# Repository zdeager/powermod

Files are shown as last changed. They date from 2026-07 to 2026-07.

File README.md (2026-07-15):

# PowerMOD

A generic power scheduler, UPS, and battery supply for I2C-capable hosts — Linux SBCs, microcontrollers, anything with a 3.3V I2C bus and a power input to control. Real-time clock, scheduled power-cycling, battery backup with load switchover, opt-in watchdog, and an event log, at a component cost of ≈$2.90.

**Status: design complete on paper. No hardware exists yet.** Every part is selected, priced, and datasheet-verified; every net is mapped pin-for-pin; the register map is ready for firmware review. Next step: transcribe the netlist into an EDA tool and lay out the board.

## Documents

| File | What it is |
|---|---|
| [powermod-spec.md](powermod-spec.md) | **The source of truth.** Full decision record with reasoning history — including reversed decisions, retained and marked. Carries the net map, the semantic-review findings, and a 45-claim verification register (every part capability cited to its datasheet; 18 claims were false and each correction is documented) |
| [powermod-user-guide-draft.md](powermod-user-guide-draft.md) | Draft user manual — integration guide, LED states, scheduling patterns, FAQ, and honest limits (drift table, output-current table, weak-supply behavior) |
| [powermod-register-map.md](powermod-register-map.md) | I2C protocol v1 — 32 registers, wire-level reference for host integration and firmware |
| [powermod-schematic.md](powermod-schematic.md) | Pin-exact netlist — every component pin to every net, MCU pin assignment, capture-time checklist. The EDA schematic transcribes this |
| [powermod-bom.md](powermod-bom.md) | Bill of materials — LCSC part numbers, verified prices, do-not-substitute notes, sourcing flags |
| [powermod_full_state_machine.svg](powermod_full_state_machine.svg) | Power state machine — all states, transitions, and gating rules |
| [hardware/](hardware/) | KiCad transcription — `netlist.py` (machine source of truth + validator) generates `powermod.net`, `powermod.kicad_sch` (ERC-clean, round-trip-verified), and via `layout.py` a placed, DRC-clean `powermod.kicad_pcb` (routing pending) |

## Open items (all require hardware)

Converter efficiency, standby current, the `CE` battery-detect decay test, factory-reset gesture feel, Q1/Q2 handover scope check.

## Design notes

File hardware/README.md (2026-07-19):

# PowerMOD hardware

Machine-generated PCB design for a Raspberry Pi Zero 2 W power scheduler /
UPS / battery board. The electrical design is defined in code (`netlist.py`);
the board was laid out and routed with the scripted KiCad + Freerouting
toolchain below, then hand-finished.

## The board — `powermod.kicad_pcb` (final)

65 × 40 mm, 4-layer (F.Cu signal / In1 solid GND / In2 signal / B.Cu signal).
Bolts under a Pi Zero 2 W (holes on the Pi's 58×23 grid, flush to the N+W
edges); the Pi covers y0–30, and all user-facing parts (USB-C out, battery,
button, LEDs, jumpers, test pads) sit on the exposed strip below it.
Single-sided assembly.

One KiCad project, one stem: `powermod.kicad_pro` (netclasses + DRC config),
`powermod.kicad_sch` (generated schematic), `powermod.kicad_pcb` (board),
`powermod.kicad_dru` (width-enforcement rules — net classes alone are NOT
checked by DRC).

**Status: fab-ready.** Fully routed, 0 unconnected, 0 clearance; the only DRC
items are 4 `track_width` flags on the L2/L1N necks at U3's 0.65 mm pins,
which physically cannot be 1.0 mm wide. Pre-fab audit (pad-for-pad netlist
diff, datasheet pin checks, operating-point math, the D5 supercap fix):
see **`PREFAB_AUDIT.md`** — read it before ordering (BOM traps, firmware
contract, bring-up plan).

> **Do NOT regenerate this board from `netlist.py`.** Placement and the
> USB-C fine-pitch escapes are hand-done. Make changes surgically on
> `powermod.kicad_pcb` and update `netlist.py` in parallel, then prove they
> agree with a pad-diff (the audit doc describes it).

## Electrical source of truth

- **`netlist.py`** — every component, pin, and net (73 components, 45 nets).
  Run it to (re)generate `powermod.kicad_sch`, `powermod.net`,
  `powermod.kicad_sym`, `sym-lib-table`, `fp-lib-table`. Has a self-test
  (golden vectors, pin counts).
- **`powermod.pretty/`** — local footprint lib: the merged-pad USB-C
  receptacle (reversible twin pads share one pad, so VBUS/GND escape cleanly
  and DRC sees no coincident-pad conflicts). Required to open the board.

## Reusable tools

All the layout/routing/placement scripts live in **`tools/`** (run them from
this directory, e.g. `python3 tools/finish_board.py powermod.kicad_pcb`, so
board paths and `_sizes.json` resolve; they add the parent dir to `sys.path`
to import `netlist.py`). `netlist.py` itself stays here — it's the design
source and writes the deliverables alongside itself. SPICE decks are in
`tools/spice/`.

Routing pipeline (for derivative boards — not this one):
- **`fr_pipeline.py`** — strip copper + export Specctra DSN / import routed
  SES. Freerouting must never see a pre-routed board.
- `tools/freerouting.jar` (gitignored, ~55 MB) — the autorouter. Java 21+, run
  with `-Djava.awt.headless=true` or it hangs on macOS.
- **`finish_board.py`** — post-route finisher: SES import → GND stitching →
  floating-pour-island tie vias → zone refill. Then DRC with
  `--refill-zones` (without it you get hundreds of phantom violations).
- **`stitch_gnd.py`** — the 2.5 mm GND stitching-via grid to the In1 plane.
- **`close_nets.py`** — route leftover nets with the In2-capable grid A*,
  each route validated by refill+DRC and reverted if it doesn't improve.
- **`router.py`** — grid A* + obstacle model (F/In2/B) used by the above.
- **`netclasses.py`** — inject net-class width targets into a `.kicad_pro`.

Placement:
- **`layout_v2.py`** — the board generator (`gen_pcb`: footprints, GND
  planes, keepouts). `layout_mount.py` configures it for this board's
  outline/holes/pinned I/O.
- **`place_constrained.py`** — constraint-aware force-directed placer
  (net springs, padded repulsion, wide-net/IC halos, rigid converter block).
- **`place_search_mount.py`** / **`relax_mount.py`** — placement search
  scored by Freerouting / overlap relaxer. **`mount_best.py`** — placer
  output snapshot (stale vs the hand-edited board; the board is
  authoritative).
- **`place_check.py`** — courtyard-overlap + off-board report.
- **`make_stencil.py`** — generates a bare user-facing-parts canvas for
  human I/O placement (its output board was removed once the layout froze).
- `_sizes.json` — cached footprint courtyard sizes (kept in this dir; the
  placer reads it cwd-relative).

SPICE (`tools/spice/`):
- **`power_path_scenarios.py`** — behavioural ngspice model of the Q1/Q2/Q3
  power path; runs the startup/switchover/unplug scenario matrix (see the
  SPICE section of `PREFAB_AUDIT.md`). Needs `ngspice` on PATH.

## Hard-won rules (cost real time — don't relearn them)

- A green DRC only checks rules that exist: keep `powermod.kicad_dru` next
  to the board, and after any rename/move confirm the 4 known `track_width`
  flags still fire (if they vanish, the rules got orphaned, not fixed).
- Netclasses live in the `.kicad_pro`. A board file copied away from its
  project routes everything at 0.2 mm and "routes fully" — a fake win.
- Zone fills are stored in the file: refill before DRC or judging renders.
- Scripted tracks don't bind to large connector pads (USB-C, bar pads) —
  those few escapes are interactive-routing territory; small pads bind fine.

## History

v1 (58×40, 2-layer) had 3A rails at 0.2 mm (the `.kicad_dru` lesson); v2
(65×30) was superseded by this board; the QFN-package MCU was swapped for the
SOIC-20 ATtiny1616 to break the routing wall; `powermod_mount.*` was renamed
to `powermod.*` once it became the only board (2026-07-17); then the MCU
migrated **ATtiny1616 → PY32F003F18P6** (TSSOP-20, ARM Cortex-M0+) on the
`instock-parts` branch (2026-07-18) for JLC assembly availability, with a full
reroute — the current board is 65×40, 4-layer, PY32. Lessons live in
the tools and `PREFAB_AUDIT.md`, not in stale board files.

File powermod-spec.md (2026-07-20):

# PowerMOD — Generic Power Scheduler / UPS / Battery Supply — Spec

Last updated: 2026-07-15
Status: **Requirements complete. Register map drafted (`powermod-register-map.md`, protocol v1). Parts selected and datasheet-verified. Schematic netlist complete (`powermod-schematic.md` — pin-exact, validated). BOM drafted (`powermod-bom.md`, **≈$2.90** @100–150 after the RTC reversal). Ready for schematic + firmware.**
Remaining before hardware: buck-boost efficiency and the final output figures (close by measuring, not reading), bench validation of the `CE` battery-detect, and the schematic-level confirmations flagged throughout. **Every IC and FET is now selected and datasheet-verified** — see the design at a glance.

> **⚠ MCU MIGRATION (instock-parts branch, 2026-07-18): ATtiny1617 → PY32F003F18P6.** No well-stocked AVR exists at JLC in any package, so the MCU is now the **PY32F003F18P6** (ARM Cortex-M0+, TSSOP-20, LCSC C5379864). **This spec still argues the MCU choice and pin budget in ATtiny terms — that text is RETAINED AS ROLLBACK RATIONALE and is MCU-agnostic** (the 20-pin-floor pin budget, the OR-latch "MCU WDT is a hard requirement", the fixed-3.3V-rail logic-level argument all hold identically for the PY32). What actually changed: the MCU part, UPDI→SWD programming, and **two PY32-specific firmware items** — ADC VREFINT calibration (see the ↪ note under §ADC) and I²C host-cutoff at VDD≥3.0V (↪ note under §Interface). **Authoritative pin map: `hardware/netlist.py` / `powermod-schematic.md` §1a.** Read every "ATtiny1617" below as "the selected MCU, now PY32"; the *net* mapping is unchanged (same 45 nets, UPDI→NRST the only swap).

## Revision note — 2026-07-15 audit

**A full cross-document audit** (this spec, the user guide, the state-machine diagram, and a register map written from them) **checked every decision against the others and against what the parts physically do.** Changes are marked inline in this document's existing decision-history style. It is a large revision; this note is the map.

**Contradictions resolved — four, each unimplementable as written:**
- **Missed-wake vs. past-wake** demanded opposite behaviour from an identical observable state → resolved by evaluating the timestamp *at commit*.
- **The reason-code register was destroyed by the act of booting** — powering on overwrote the power-off reason before any host could read it → split into two registers.
- **Emergency cutoff: delay or no delay** — the diagram and the spec disagreed → routed through the delay, one code path.
- **Minimum off-duration was never actually solved.** The gap said "minimum off-duration"; the register adopted to close it was "delay before power cut" — a different mechanism entirely. Nothing prevented a zero-second power cycle.

**BOM corrections — the design described behaviour its parts could not deliver:**
- **TP4056 → MCP73871 → *back to TP4056*, behind a discrete PFET OR (reversed later the same day).** The hot-swap claim does require power-path isolation, but **an OR-ing stage provides it just as well as a power-path IC**, and TP4056's disqualifying defects belong to the *topology* it was assumed to sit in, not to the part. The reversal halves the power stage (**~$2.00 → ~$1.00**) and roughly doubles mains output (1.3A → ~2.7A), because MCP73871's `SEL`-high limit is **1.8A total, "system power and charge current combined"** — a cap we were paying $1.46 to impose on ourselves. **BQ24074 remains disqualified**, and the MCP73871 analysis is retained as history. See "Charger and power path — REVERSED".
- **PCF85063A → RV-3028-C7 → *BM8563*, a PCF8563-class part (reversed 2026-07-15)** — the RV-3028's stated reason was false (no TCXO), and the audit later showed its 40nA never mattered either; what remained was ±1ppm for $1.62/board. Gates run against the clone's own datasheet; wake API unchanged (minute alarm + countdown residue); `BACKUP_TRICKLE` register replaced by a solder jumper. See RTC part decision.
- **14-pin MCU → ATtiny1617 (24-pin VQFN 4×4).** The pin budget missed by four, then grew twice more the same day (charger reversal; the OR's latch fix) — **18 pins, and a 20-pin part would ship with zero spare.**
- **Output 3A → ~1.2A → *a per-mode table* (same day).** 3A was never achievable on a 15W input, and drew double the battery connector's rating; the ~1.2A single figure then died with the charger reversal. **There is no one number: ~2.7A on mains, ~1.0–1.5A on battery via the connector, ~1.8–2.6A via the pads, ~2A in 3.3V mode** — see the ratings table.
- **TPS63020 selected**, and its load disconnect turns out to be *how host power is switched at all*.
- **The OR stage as first drawn latched permanently on unplug** — Q1's VBUS-tied gate held itself on through the battery, running the full load through Q2's body diode. Fixed: Q1 is MCU-driven off a VBUS-vs-VBAT comparison (Q2 stays fully passive), which costs a GPIO and makes the **ATtiny's own WDT a hard requirement**. FETs selected: **2× AON7407** (Q1/Q2), **BSS138** (Q3 driver).

**Added:** opt-in watchdog (the only unrecoverable failure mode), minimum off-duration, critical-battery threshold, LED power specification, a 3.3V logic rail, shutdown-pending status, wake-time read-back, hold-to-force on the button.

**Withdrawn after adoption** — recorded because the reversals are the useful part: **temperature-qualified charging** (the 2-pin connector gives the sensor no path to the cell), and **input-voltage telemetry** (mains detect was a digital read under the then-selected charger, so it wasn't free — **since half-reopened**: the charger reversal made mains detect a VBUS *ADC* divider, so the measurement is free again; deliberately not adopted in protocol v1. See Telemetry scope).

**Narrowed:** host support is **3.3V I2C**, not "any I2C" — a 5V host damages the board.

**Every part claim is now cited or marked unverified.** See the claims register appendix — **45 claims across four batches, 18 were false — and as of 2026-07-15, zero remain open**, and the failure rate *rose* as the claims got more consequential (batch 3: 16 of 23). The earliest two failures had already changed a decision before anyone looked. *(This sentence itself previously read "16 claims checked, two were false" — stale by 21 claims and 14 failures, in the paragraph describing the discipline. Self-descriptions rot fastest; this document's own register says so.)*

## The design at a glance

Everything below is reasoned out in this document; this table exists because it was not previously stated anywhere in one place, and a reader had to reconstruct it from prose and a Next Steps checkbox.

| | Selected | Verified |
|---|---|---|
| **MCU** | **ATtiny1617, 24-pin VQFN 4×4** | **Selected 2026-07-15.** 18 pins used, 4 spare. 1616 fits with *zero* spare; the count grew twice in one day. **VQFN-only — no SOIC variant exists** |
| **RTC** | **BM8563** (PCF8563-class) + 32kHz crystal, VDD via **2-diode OR** | **Reversed 2026-07-15** (−$1.67 after the Belling switch). ±20ppm-class; minute alarm + 1Hz countdown = seconds-exact wakes; `VL` flag; 250nA backup. **CLKOUT ships enabled — firmware disables**. I2C pins rated 6.5V independent of VDD |
| **Charger** | **TP4056** ($0.084) behind a **discrete PFET OR** | **Reversed 2026-07-15** — MCP73871 ($1.46) was 3× the converter and capped input at 1.5A *system + charge combined*. `TEMP` **grounded** (opposite of MCP73871's `THERM`) |
| **Power path** | **2× AON7407** (C176756, DFN3×3, $0.174) + **BSS138** (C52895) | **Q2 passive** (gate←VBUS). **Q1 MCU-driven** — a passive gate latched on unplug, see the OR stage. `Vgs(th)` −0.9V max, **12.5mΩ @ −2.5V**. ⚠️ AON7407 `VGS` limit is **±8V**, not ±20V |
| **Converter** | TPS63020 (adjustable, **not** 63021) | 4A switches (**3500mA min**), 25µA Iq, load disconnect. `PS/SYNC` **low**. Vin max 5.5V = **zero headroom** vs a 5.5V-compliant source |
| **Logic rail** | **XC6206P332MR** (Torex, C5446, SOT-23, $0.096) | **Iq 1µA; floor = LDO + battery divider (~3µA) + MCU sleep ≈ 5µA class.** Dropout ~38mV @ 15mA keeps the rail I2C-legal at cell-bottom. A SYS-powered MCU kills the I2C bus on mains |
| **Output** | **5V: ~1.0–2.7A. 3.3V: ~1.6–2.0A** | **Depends entirely on source + connector — see the ratings table.** Floor is ~1.0A (PH2.0, 5V, near cutoff). 3.3V never exceeds 2A in any config |
| **Battery detect** | TP4056 `CE` low → watch VBAT collapse | A **positive test**, not a threshold guess — separates *absent* from *deeply discharged*. Needs bench validation |
| **I2C** | **3.3V only**, no pull-ups fitted | 5V hosts need a level shifter — **they damage the board otherwise** |
| **Battery** | Any 3.7V LiPo, JST-PH 2-pin | **Polarity is not standardised across vendors — meter it** |
| **RTC backup** | Two solder pads + **charge solder-jumper** (open = coin-safe) | Coin cell / supercap / nothing. Supercap installs close the jumper; no register can ever charge a primary cell |
| **Ports** | 2× USB-C (5V, non-PD) | Rd 5.1k in; Rp 56k out (deliberate under-advertise). **Needs a ≥2A supply; 3A for full output** |
| **Range** | −40°C to +85°C electronics | −30/+60 if a coin cell is fitted; your LiPo narrows it further. **No charge-temperature protection** |

## What PowerMOD is

A generic, host-agnostic scheduled power controller and UPS: real time clock, battery charging and management, and a two-command power protocol (schedule a wake, request a cut) over I2C. Designed to be dropped into any project needing scheduled power-cycling, battery backup, or both — a Linux SBC, a bare-metal MCU project, or anything else with a **3.3V** I2C bus and a power input to control (the 3.3V is a hard limit, not a preference — see Interface).

The design deliberately makes zero assumptions about what it's powering or commanding: no host OS awareness, no GPIO signaling, no protocol behavior that only makes sense for one kind of host. The protocol, the power stage, and the physical connectors were all chosen specifically to keep this true (see Interface and Extensibility sections). **Linux SBCs (Olimex A64-OLinuXino, Raspberry Pi-class boards) are the first documented, validated use case and the primary motivation for building this at all — not a constraint on what the board can do.**

## The problem (as first encountered, via the Linux SBC case)

Existing scheduled-power boards for SBCs (Witty Pi and peers) infer host state instead of letting the host declare it — watching a serial pin voltage, assuming Raspberry Pi OS + Python + specific shutdown hooks, silently overwriting timezone assumptions. This breaks in real, documented ways, even on their officially-supported OS, and breaks harder on anything else (hit first-hand running Alpine Linux, requiring a custom driver). This specific, real pain point is what motivated PowerMOD's core design principle — but the principle itself (below) turned out to generalize far beyond the case that surfaced it.

## Design

The host owns the "when is it safe to cut power" decision entirely. The board never tries to detect or infer host state — it only responds to explicit commands.

**Two core operations:**
1. **Wake me at time T** — host writes a future timestamp before beginning its own shutdown sequence.
2. **Cut power now** — host issues this only once its own shutdown is genuinely complete, however its own OS determines that.

**Board exposes:** RTC (read/write), wake-time schedule, cut-now command, battery voltage, mains-vs-battery status.
**Board never needs to know:** host OS, init system, or how the host determines it's done.

This beats both Witty Pi's approach (fragile signal-inference) and a simpler "cut at time T unconditionally" alternative considered (host-decided cutoff removes the timing-race risk of a board-guessed deadline).

**Fallback safety (host hangs, never says "cut now"):**
- Board exposes mains/battery status so the host can prioritize its own shutdown urgency (low stakes on mains, real urgency on battery).
- Independent hard voltage floor, enforced by the board regardless of host cooperation: below a fixed threshold, cut unconditionally. Not a timeout guess — a physical safety limit, same category as any LiPo protection IC.
  - **"Hard floor" vs. "default disabled" — an ambiguity the register map forced to a decision, now resolved.** This bullet describes the floor as hard, fixed, and enforced regardless of cooperation. The Witty Pi precedent adopted below (register #19) is *default disabled*. Those cannot both be true.
    - **Resolved: the threshold ships enabled at 3.0V** (register map §7, §11). It remains configurable, and disabling it (value `0`) stays legal for an integrator with their own protection circuitry — but opting out of over-discharge protection is an explicit act rather than the out-of-box state.
    - **What settled it: three other resolutions in this document are load-bearing on the floor being active.** The hung-host-on-battery case is bounded by it ("the host either eventually drains the battery, triggering the independent low-voltage cutoff"); the stuck-I2C-bus case concludes "no new design needed" explicitly because of it; and the decision not to extend the watchdog to the battery case rests on it. **Shipping the floor disabled would silently falsify all three for a default board** — each argument would be leaning on a safety net that isn't there unless someone read a register table and switched it on. The "hard floor" language is the load-bearing one; the disabled default was inherited from precedent without noticing it contradicted three conclusions already drawn here.
    - **Why PowerMOD can diverge where Witty Pi could not.** Their likely reason for a disabled default is that their boards are often run with no battery, where an enabled threshold reading ~0V would fire instantly. PowerMOD gates both thresholds on the charger's battery-detect — mains-only mode has no voltage monitoring at all (Section on Scope) — so that failure mode cannot occur here. The divergence is enabled by a design decision they don't have, not a disagreement about risk.
- **Re-arm/hysteresis:** cutoff floor and re-enable threshold are separate values, not one. Board does not restore power the moment voltage creeps back above the cutoff floor — that risks a boot-current draw immediately sagging voltage back under the floor, causing a rapid cut/recover/cut oscillation right when the battery is most fragile. Power is restored only once battery voltage recovers to a meaningfully higher threshold (3.6V) **or mains power is supplied** — the latter giving immediate recovery the moment someone physically intervenes on a dead-battery device, without waiting on trickle-charge.
- **Hung host on mains — reopened, reversed, now an opt-in watchdog (audit finding, adopted).** Previously an explicit non-goal, twice reconfirmed: PowerMOD would not detect, diagnose, or act on host-level hangs at all, and detection was left entirely to the operator's own monitoring (the expected signal being the absence of whatever telemetry the host normally produces during its wake cycles). **That reasoning conflated two different things, and the conflation is what made it look principled.** The core principle (Section 2) forbids PowerMOD *inferring* host state — Witty Pi's actual sin was inferring liveness from a serial pin voltage. A watchdog where the host **explicitly writes to a register to declare itself alive** is not inference; it is the same architecture as "cut now" — an explicit host declaration that PowerMOD merely acts on. It is no more a violation of Section 2 than the two core commands are.
  - **The asymmetry was already unjustified.** The max-sleep-before-forced-wake safety net (Section on explicit scope decisions) is structurally the identical mechanism — a timer, disabled by default, that recovers a host which failed to declare something — applied to the OFF state. There was never a principled reason to accept it there and refuse it in the ON state.
  - **What it closes:** the only unrecoverable failure mode in the entire design. The old resolution's own words concede it — operator telemetry going quiet only *detects* the hang. On the remote, unattended deployments this board is explicitly built for, detection means a site visit; a watchdog means the device fixes itself. On battery the case was already bounded (the low-voltage cutoff eventually force-cycles it); on mains it was bounded by nothing at all.
  - **Requirement: a configurable watchdog timeout register, disabled by default.** If enabled, the host must write to a designated register within the timeout to declare liveness; if the timeout expires, PowerMOD power-cycles the host and records a distinct watchdog-expiry reason code. Zero BOM cost (one timer, one register), and disabled-by-default matches the same disable-by-value convention already used for the low-voltage, recovery, and max-sleep thresholds — so it never surprises an integrator who didn't ask for it.
  - **The watchdog arms on the host's first kick, not at power-on (register-map finding, load-bearing).** If it started counting the moment the rail came up, any host whose boot takes longer than the timeout would be power-cycled before it ever finished booting — permanently. A 60s timeout on a 90s-booting host is an unbreakable loop that bricks the device in the field, and unreachable over I2C precisely because the host never gets far enough to talk. **Rule: after every power-on the watchdog is disarmed; it arms on the first kick and stays armed until power is cut.** A host that never kicks is never watchdogged, which is also the correct behavior for host software that doesn't know the watchdog exists. Costs one flag, and removes any need for a separate boot-grace-period register.
  - **Still a non-goal, and this is the line:** PowerMOD does not *diagnose* anything. It does not know or care *why* the host stopped writing — crashed, hung, deadlocked, or deliberately silent are indistinguishable to it and treated identically. Operator-side telemetry monitoring remains the right tool for understanding *what* went wrong; the watchdog only restores service without waiting for a human.

**RTC backup power — optional and user-fitted, justification narrowed (audit revision).** PowerMOD provides two labelled solder pads wired to the RTC's backup supply — since the 2026-07-15 RTC reversal, via diode D4 into the BM8563's diode-OR'd VDD (formerly the RV-3028's dedicated VBACKUP pin) — not to an ad-hoc backup rail. **The board does not ship a backup source; the integrator fits one, or doesn't** (see "Backup fitting" below for why, and what to fit).

**Justification, corrected.** The earlier reasoning claimed the cell was "load-bearing for mains-only mode, redundant-but-harmless for LiPo mode." That over-claimed in one direction and under-claimed in the other, and it rested on a storage error corrected below.
- **What only the coin cell can do: keep the RTC counting through a total loss of power.** Nothing else on the board can do this — it is irreducibly a battery problem. Everything else the cell was previously credited with backing (pending wake time, power-on state bit) belongs in EEPROM and is corrected below.
- **Where that actually matters, stated honestly:** hosts that use wall-clock scheduling *and* cannot re-sync time on boot (no network, no GPS). A networked host re-syncs via NTP and never notices; a host using relative-time scheduling (Section on RTC default state) does not care what the clock reads at all. This is a real set of deployments, but a narrower one than "all mains-only deployments."
- **Off-mains LiPo swap — the case that decides it.** On mains, replacing the LiPo needs no coin cell whatsoever: **the PFET OR** (Section on charger and power path — REVERSED; *was* the power-path IC) keeps the board and RTC alive from the mains rail while the battery is genuinely isolated. **The charger reversal does not weaken this — it strengthens it; see the hot-removal claim below.** **Off mains, pulling the LiPo is a total power loss, and the coin cell is the only thing that preserves the clock across it.** A technician replacing a degraded cell at a remote solar site with no mains present is a realistic servicing scenario for the flagship deployment, and it is what keeps the cell in the design.
- **Interaction with the power-on default (worth stating, since it changed):** adopting Restore-previous-state as the default *raises* the cost of losing the RTC. Under the old Always-ON default, any total power loss recovered by booting regardless. Under Restore, a total loss during a scheduled sleep leaves the device off — so preserving the clock and schedule matters more than it did when the cell's justification was originally written.
- **Storage correction (this was simply wrong before):** the pending wake time and the power-on state bit are **EEPROM state, not coin-cell-backed state.** They are non-volatile and survive a dead coin cell for free. Only the RTC's *count* depends on the cell.
  - **Write-endurance consequence — missed on the first pass, now resolved.** The correction above originally claimed these "reuse the wear-leveling infrastructure already built for configuration and the event log." **That was asserted, not traced, and it is false**: configuration is not wear-levelled (it is written rarely), and the event log's wear-levelling is specific to its own 8×5-byte slot arithmetic. Neither covers a separate state bit or wake time. **Both are written on every power cycle** — the state bit twice (on and off), the wake time once — against roughly 100k-cycle EEPROM endurance:

    | Duty cycle | State bit life | Wake time life |
    |---|---|---|
    | Every 15 min | **1.4 years** | 2.9 years |
    | Every 30 min | 2.9 years | 5.7 years |
    | Hourly | 5.7 years | 11.4 years |
    | 4× per day | 34 years | 68 years |

    **Anything more frequent than roughly hourly fails inside its service life**, and Restore-previous-state — the mode that needs the state bit — is now the *default*. Note the irony, because it is the point: **the original coin-cell-backed-RAM design had no wear problem at all.** Moving this state to EEPROM was correct for surviving a dead cell and traded one failure mode for another without anyone noticing.
  - **Resolved, and the state bit costs nothing to fix: derive it from the event log instead of storing it.** The log already records every power transition, is already wear-levelled, and its reason enum is already self-describing (bit 7 = power-on vs. power-off — register map §8.2). So "was the host powered when power was lost?" is answered by scanning back to the most recent non-informational entry and reading one bit. **Zero additional writes, no new state, and it cannot disagree with the log.** Empty log (first ever power-up) or a log holding only informational entries → default to ON, matching the specified first-power-up behavior.
    - **⚠️ Corrected by the spec walk (2026-07-15): the naive derivation contradicts semantic-review finding 1.** "Most recent event is a power-off ⇒ host was off" reads `LOW_VOLTAGE_CUTOFF` as *off* — but finding 1 requires an emergency cutoff to record the host as **ON** (cut involuntarily). **The derivation classifies by voluntariness, not direction:** a *deliberate* cut (`HOST_REQUEST`, `BUTTON`, `BUTTON_FORCED`) derives OFF; an *involuntary* cut (`LOW_VOLTAGE_CUTOFF`, `WATCHDOG_EXPIRY`) derives **ON**; any power-on event derives ON. The watchdog case composes correctly for free: if total power dies between a watchdog cut and its automatic recovery, the derivation boots the host on power return — which is exactly what the watchdog was trying to do.
  - **Resolved for the wake time: wear-level it across a small rotation of slots**, exactly as the event log does — the same standard technique, applied to the storage that actually needed it rather than assumed to cover it. Sizing the rotation is a register-map/firmware detail; the requirement is that a per-cycle write must not land on the same byte every time.
- **Coin cell vs. supercap — settled 2026-07-15 in favour of the coin cell, on measured numbers — and the conclusion survives the RTC reversal unchanged** (the backup draw rose 45nA → 250nA, but the decision always rested on *supercap leakage and coin self-discharge dominating either figure by 10–100×*, which is exactly why the cheaper RTC was safe to adopt). Original analysis: RV-3028-C7's **40nA** backup current and dedicated VBACKUP pin (both datasheet-verified, along with its automatic switchover and trickle-charger function) made a supercap genuinely viable — no holder (one of the pricier mechanical parts), no shelf life, no user-replaceable component with its own documentation burden and failure mode. The catch is supercap self-leakage. **Now measured against a real datasheet rather than estimated** (Abracon ADCH-S05R5S coin supercaps; leakage max, 72h at rated voltage), charging to 3.3V and discharging to the RV-3028's 1.2V minimum:

| Supercap | Leakage (max) | RTC's share of drain | Backup |
|---|---|---|---|
| 0.1 F | 3 µA | 1.3% | ~19 hours |
| 0.22 F | 4 µA | 1.0% | ~32 hours |
| 0.47 F | 6 µA | 0.7% | ~45 hours |
| 1.0 F | 8 µA | 0.5% | ~73 hours |
| 1.5 F | 12 µA | 0.3% | ~73 hours |

- **The RTC is 0.3–1.3% of the drain.** The 40nA figure that makes the supercap sound viable is almost irrelevant — the capacitor's own leakage is 75–300× larger and sets the answer entirely.
- **Backup plateaus at ~3 days, and buying a bigger part does not help.** Leakage scales with capacitance, so 1.5F backs up no longer than 1F. This is the part the earlier "days, not years" hedge missed: it isn't a knob that can be turned up. **If more than ~3 days is ever needed, the supercap route is closed outright** — no amount of capacitance reaches a week.
- **A CR2032 at 40nA is limited by shelf life (~10 years), not by the load** — the RTC would take centuries to drain it. The two options are not on the same scale and no sizing exercise brings them together.

**Where this lands: the supercap covers a battery swap (minutes) and an ordinary grid outage (hours) comfortably. It does not cover a week of winter darkness at a solar site, and cannot be made to.** So the question was never "how big a supercap" but "is a multi-day ceiling acceptable" — a question about deployments, not components.

### Backup fitting: two labelled pads, no holder — board area was never costed, and it dwarfs everything (adopted 2026-07-15)

**The holder's *price* was weighed twice in this document. Its *area* was never mentioned once — and area is by far its larger cost.**

| | Board area |
|---|---|
| ~~ATtiny1616~~ + RV-3028-C7 + TPS63020 + ~~MCP73871~~ — every IC, **as costed before the charger reversal and the 1617** | **~42 mm²** |
| Same, **after the reversal + the 1617** — TP4056 (ESOP-8 ~19mm²) + 2× AON7407 (DFN3×3, 9mm² ea) + BSS138 (SOT-23) replace one 4×4 QFN; MCU 3×3 → **4×4** (+7mm²) | **~74 mm²** (**all parts now selected — measured, not estimated**) |
| **CR2032 cell alone** (before the holder's retention arms and solder tabs) | **~314 mm²** |

> **The reversal roughly doubles the IC area, and that is a real cost this document should not hide.** MCP73871's 4×4 QFN was *integration you could measure*: one 16 mm² part became a ~19 mm² ESOP-8 plus a discrete OR stage. **If the PFETs must grow to handle Q1 at 2.7A (they likely must — see the FET sizing table), this gets worse, not better.** The ~$1.20 saved per board is partly paid back in silicon area, on a board whose defining constraint is size.
>
> **Corrected twice on 2026-07-15, in both directions: ~85 mm² (guessed) → ~67 mm² (PFETs chosen) → ~74 mm² (1617's 4×4 replaces the 1616's 3×3).** That guess assumed SOP-8 PFETs; the selected AON7407 is DFN-8 3×3 (9mm²), materially smaller. **The error was pessimistic rather than optimistic, which is the safer direction to be wrong — but it was still a guess presented in a table of measurements.**
>
> **The conclusion survives, and stays a footnote:** 314 mm² still dwarfs 74 mm². The cell drops from ~7.5× to **~4.2×** the combined IC footprint — less dramatic, still decisive. **A weakened argument that reaches the same conclusion must be re-stated at its true strength, not left quoting the old multiplier.**

**The cell is ~3.2× the combined footprint of every integrated circuit in the design** (re-computed after the RTC reversal: the BM8563+crystal+diodes add ~25mm² over the ceramic RV-3028, IC total ~74→~99mm²) **and ~16× the area of the RTC subsystem it exists to back up.** Each recomputation has weakened this ratio — 7.5× → 4.2× → 3.2× — and it still clears decisively; the day it approaches 1× the pads decision reopens. The holder ships on **44mm** tape and reel (Keystone's catalogue, 20mm-cell SMT holders); every IC here ships on 8–12mm. **It is, comfortably, the largest component on the board** — and a design that has agonised over a 3×3 versus 3×4mm package elsewhere never noticed.

**Resolved: replace the holder with two labelled solder pads (`VBACKUP`, `GND`), wired to the RTC's backup diode D4 (the diode-OR replaced the RV-3028's dedicated VBACKUP pin in the 2026-07-15 part reversal) — formerly the RV-3028's VBACKUP pin.** The backup becomes user-fitted and genuinely optional — which matches what it always was: irrelevant to relative-time hosts, irrelevant to networked hosts, load-bearing only for non-networked wall-clock deployments. **This reclaims the single biggest area consumer on the board and deletes a mechanical part, a user-replaceable item, and its documentation burden, in exchange for nothing that most integrators use.**

- **The pads accept whatever the deployment needs:** a lead-terminated or solder-tab coin cell (years of backup), a supercap (~1–3 days, and now much more attractive — it was only ever rejected on that ceiling, and the pads remove its other disadvantage by removing the holder from the comparison), or **nothing at all**, which is the cheapest and correct answer for most.
- **⚠️ The documentation must forbid soldering a bare coin cell, explicitly.** Heating a lithium coin cell can vent or rupture it. Pads invite exactly that mistake from anyone who owns a CR2032 and an iron. **Only solder-tab or lead-terminated cells, or a supercap.** This is a safety instruction, not a preference, and it is the one real cost of this change.
- **The pads need polarity marking and, ideally, asymmetric geometry** — otherwise they inherit the battery connector's reversal problem with no key at all. Unlike the JST-PH case, silkscreen genuinely *is* sufficient here: a bare pad is unambiguous precisely because nothing pre-wires it for you.
- **Interaction with the temperature range (Section 8):** the coin cell's −30/+60°C was the narrowest limit on the board. **Making it optional widens PowerMOD's own range back to the silicon's −40/+85°C** for anyone who fits a supercap or nothing — an unplanned second benefit.

**"Coin cell vs. supercap" stopped being a board decision the moment the pads were adopted — and that reframing is the real resolution (2026-07-15).** This section previously ran a long argument to pick *one* backup for the board to ship, concluded "keep the coin cell," and justified it as "paying for a holder to cover the deployment this board exists for." **With no holder on the board, that conclusion answers a question that no longer exists.** The pads decision was inserted above it without rewriting the argument it invalidated — the same failure this document keeps recording elsewhere, committed here.

**What the analysis above is actually for, restated:** it is no longer a choice PowerMOD makes, it is **guidance for the integrator making it**, and every number in it still earns its place:

| Fit | Backup | When it's right |
|---|---|---|
| **Nothing** | none | Relative-time scheduling, or any host that re-syncs its clock. **Most deployments** — and the cheapest, smallest answer. |
| **Supercap** | ~1–3 days (hard ceiling) | Grid outages and off-mains LiPo swaps. One part, no shelf life, nothing user-replaceable, and the RTC's own trickle charger drives it with no support circuitry. |
| **Coin cell** (solder-tab or lead-terminated) | years | Non-networked wall-clock hosts; **the flagship remote-solar case, which can be dark for a week — precisely where the supercap's ceiling silently isn't there.** |

**So both of the earlier conclusions survive, as advice rather than as a board-level commitment:** the supercap really is the better engineering choice for most deployments, and the coin cell really is the only thing that covers a week of winter darkness. **The pads let both be true at once, which is why the decision they replaced was the wrong shape** — it forced one answer onto a board serving deployments with genuinely different needs.

**Worth recording for anyone revisiting this:** if PowerMOD ever ships a variant that is explicitly *not* for long-dark deployments — a bench/indoor scheduler, or a mains-only-only product — **the supercap becomes the better answer and the numbers above already justify it.** Nothing about that decision needs re-deriving; only the deployment assumption changes.
- **Scope of what the coin cell backs**: the RTC count only. **Does not** power the LEDs, and **does not** enable PowerMOD to actually power the host — a wake time surviving a total outage does not mean the host will wake on schedule if no real power source (mains or LiPo) is available when that time arrives. This distinction should be stated clearly in user-facing documentation to avoid the coin cell being oversold as "outage-proof" beyond timekeeping.
- **Missed wake time during a total outage — resolved, then found to contradict the past-wake rule, now re-resolved (audit finding).** Concretely: a wake time is scheduled for 2 PM; both mains and battery are unavailable from 1 PM to 4 PM (coin cell keeps the RTC alive, but there's no power to actually switch); power returns at 4 PM. The original resolution was: **wake the host immediately** rather than discarding the missed alarm, consistent with the unattended-recovery philosophy running through the rest of this design.
  - **The contradiction:** the Section on invalid/past schedule writes independently resolved that **a past wake time is simply never treated as due**, explicitly *rejecting* "wake immediately" — because a host that writes a bad timestamp would otherwise get an instant, unexplained reboot. Both rules are individually well-argued and they cannot both be implemented, because **at wake time the two cases are physically indistinguishable**: PowerMOD powers up, reads a stored timestamp that is in the past, and has no way to know whether that's because power was out during the window or because the host wrote garbage. Same observable state, two opposite required behaviors.
  - **Re-resolved: evaluate the timestamp when it is committed, not when it comes due.** This satisfies both rules' actual intent at the cost of one bit, and it reuses the shadow-register-and-commit path already required for write atomicity (Section on state-machine details):
    - **Already in the past at commit time → mark expired. Never fires, ever.** This is the bad-timestamp case, and it preserves the past-wake rule's intent: a miscalculated write causes the host to stay asleep, not to reboot mysteriously. The max-sleep safety net remains the backstop.
    - **In the future at commit time → arm it.** If it then goes by while PowerMOD has no power to act, it is a genuinely missed alarm and **fires as soon as usable power returns.** This preserves the unattended-recovery intent: the host asked for something reachable, and physical reality is the only reason it didn't happen.
  - The distinction the original two rules were each reaching for is exactly "was this reachable when the host asked for it" — which is knowable at commit time and unknowable later. Cost: one flag stored alongside the wake time in EEPROM.
- **LiPo hot-removal — claim was false against the original BOM, now made true by the power-path IC (audit finding).** The claim: when mains is connected, the battery is disconnected from the power rails and only charges — the host's power is never sourced from the battery while mains is present — so removing the LiPo on mains is safe and does not interrupt host power.
  - **This was not true of the TP4056-class charger originally speced.** That part has no separate system rail; the load hangs permanently off the BAT pin, in parallel with the battery. The battery was never isolated, and hot-removal would have dropped the host onto a current-limited charger output and browned it out. The architecture described here was always *power-path management*, which the speced charger does not do — see the Section on power stage for the full finding and the resolution.
  - ~~**With the power-path IC now adopted, the claim is accurate as written**~~ — **this was still wrong, and the charger reversal is what finally made it true (2026-07-15).**
    - **MCP73871 did *not* genuinely isolate the battery.** Its own datasheet: *"if the system demands more current than the input can provide, the ideal diode becomes forward-biased and **the battery may supplement** the input current to the system load."* So under peak load the cell was in the path *while on mains* — the exact thing the claim denies. **The audit adopted a part to make a safety claim true, and the part didn't make it true.** It was only ever true below the input current limit, which was never stated.
    - **The PFET OR does isolate it, structurally.** With VBUS at 5V and the cell at ≤4.2V, Q2's body diode is reverse-biased and its gate sits at VBUS: the battery is **off the rail, not merely deprioritised on it**. Hot-removal on mains is safe because the cell was never connected, not because something arbitrated in its favour.
    - **One honest exception, which must be documented rather than buried:** if the supply is undersized and VBUS sags *below* the cell voltage, Q2 conducts and the battery carries the load. **"Isolated on mains" holds for an adequate supply; with a weak one the cell is in the path** — see the USB-C input section.
    - **Three passes to get one safety claim right.** It was false against TP4056-alone (no isolation at all), false against MCP73871 (isolation only below the current limit), and true against TP4056-behind-an-OR. **Each pass sounded conclusive.** Anything user-facing should state the exception, not the headline.

## Scope

**Design scope: any host with 3.3V I2C — an honest, bounded claim, not "anything" (external review feedback adopted; boundary narrowed 2026-07-15, see below).** PowerMOD's protocol, power stage (now buck-boost with selectable 3.3V/5V output — see Extensibility section), and physical interface were all chosen to avoid host-specific assumptions, within that I2C boundary. This isn't aspirational — it's the actual, current design, not a future goal. **Worth being explicit about the real limit this implies**: I2C covers essentially all MCU families (RP2040, ESP32, STM32, AVR) and Linux SBCs, but does *not* cover hosts that don't expose I2C conveniently or at all — routers, many mini PCs/NUCs, and other USB-or-Ethernet-only equipment.

- **Narrowed 2026-07-15: the boundary is 3.3V I2C, not I2C.** PowerMOD is a **3.3V** I2C device (see Interface), so **a 5V host does not simply fail — it damages PowerMOD**, and needs an external level shifter. In practice this costs almost nothing against the stated targets: Linux SBCs (including the flagship Pi and A64), RP2040, ESP32 and STM32 are all 3.3V, as is the STEMMA-QT ecosystem the connector belongs to. **The casualty is the "AVR" claim above** — classic 5V AVRs like an Arduino Uno are exactly the case that breaks, and this document listed them as supported. They remain usable *with a level shifter*; they are no longer plug-and-play, and saying "any host with I2C" without that qualifier was over-claiming. "Generic" in this spec means "host-agnostic within the I2C-capable world," not literally universal — a genuinely different transport (USB serial, a simple GPIO command interface) would be needed to reach that further tier of hosts, and is explicitly out of scope for this design (same protocol logic could in principle be re-exposed over a different transport later, but that's a separate, unbuilt variant, not implied by anything here).

**Flagship documented use case: Linux SBC hosts** (Olimex A64-OLinuXino, Raspberry Pi-class boards). This is where PowerMOD's real UPS/charging behavior, mains/battery awareness, and integration guidance are most thoroughly documented (Sections on Interface, host integration patterns), because it's the case that motivated the project and the one with the deepest validation (Section 8's evidence log). It is a *use case*, not a *constraint* — the underlying design does not assume Linux, an SBC form factor, or any particular host capability.

**Bare-metal/MCU hosts — fully supported by the protocol and power stage, lighter documentation.** The two-command protocol (wake/cut, plain I2C) needs zero changes to work with a bare-metal host, and — per the analysis that follows — integration is often *simpler* than the Linux case, since a bare-metal application already knows unambiguously when it's safe to lose power, with no OS shutdown sequence to reason about. A real, independently-built, awarded project (Hackaday's 2026 Green Powered Challenge "powerTimer") validates this exact two-command pattern on a bare-metal MCU host. **What genuinely differs by host class is the power stage's operating point, not its topology or output flexibility** — a battery-and-charging-heavy UPS is naturally sized for SBC-class current draw (~1.2A, revised down from 3A — see the power stage section) and won't hit the very lowest quiescent-current numbers a pure microwatt-class MCU application might want (see table). This is a real, physical tradeoff (the same components that enable real UPS/charging behavior have their own baseline overhead), not a documentation gap — a future, separate ultra-low-power variant remains a valid idea if that specific tier is ever wanted, but it doesn't block using PowerMOD as-is for the vast majority of MCU projects today.

| Component | PowerMOD (current design, all hosts) | Theoretical future ultra-low-power variant (not built) |
|---|---|---|
| RTC | **BM8563** (PCF8563-class + crystal, ~±20ppm — **not** temp-compensated; reversed from RV-3028-C7 2026-07-15) | Same class — *the RTC stopped differentiating the variants once the audit showed backup life is leakage-dominated, see below* |
| Power switch | TPS63020 buck-boost (3.3V/5V selectable, **~1.0–2.7A depending on source and connector — see the ratings table**, load disconnect) | Simple SR-latch/MOSFET gate |
| Battery + charging | Real LiPo + **TP4056 charger behind a PFET OR** (reversed 2026-07-15), or mains-only mode | Small/coin cell, minimal charging |
| Quiescent budget | ~0.3mA (Witty Pi's actual spec, comparable class of design) | Tens of nA |
| Output | USB-C or raw pins, 3.3V/5V selectable | Simple 2-pin/JST, fixed voltage |

**Table revised (audit).** Two rows changed meaning:
- **The RTC row no longer differentiates anything.** RV-3028-C7 was listed here as the hypothetical future variant's part; it has since been adopted for the main design (see the RTC decision below), so both columns are the same part. The row is retained only to make that explicit rather than leaving a stale contrast implied.
- **The quiescent-budget argument now rests entirely on the buck-boost and the charger**, which is where it always actually lived. The RTC was never the reason PowerMOD can't reach nanoamp-class quiescent current — a 40nA RTC is compatible with either design. The real, unavoidable contributors are the buck-boost converter and the power-path charger IC, whose own baseline overhead is the price of real UPS behavior.

These still aren't tunable values on one circuit — the buck-boost converter and charger IC that make the SBC case work are exactly what prevent nanoamp-class quiescent current, so it's a different topology, not a config option. The point of the table is unchanged; only the honest attribution of *which* parts drive it has been corrected.

**RTC part — REVERSED 2026-07-15: RV-3028-C7 → BM8563 (PCF8563-class) behind a silicon diode-OR.** The section below is retained as history; its analysis of why the RV-3028 was *originally* chosen already documents that the stated reason (a TCXO) was false. The reversal closes the loop:

- **What the $1.73 was actually buying, after the audit stripped the false claims: ±1ppm factory calibration and on-die integration. Nothing else survived scrutiny** — the celebrated 40nA never mattered (supercap leakage and coin self-discharge dominate backup life by 10–100×), the TCXO never existed, and the UNIX counter is ~30 lines of BCD in firmware.
- **Gates run against the BM8563's own datasheet (GATEMODE edition), all passed:** PCF8563-identical register map including the countdown timer; alarm at minute granularity (firmware arms the minute alarm and burns the 0–59s residue on the 1Hz countdown timer — **the wake-to-the-second API is unchanged**); **SCL/SDA and INT rated −0.5 to +6.5V *independent of VDD***, which is what makes the diode-OR legal; backup draw **250nA typ @3V** (noise, per the leakage analysis); clock-integrity floor 1.2V (diode-OR'd coin cell delivers 2.3V).
- **Backup switchover is now diode physics, not a register** — 2× 1N4148-class silicon (nA leakage; the 0.7V drop is affordable on both legs since VIH = 0.7×VDD tracks the OR'd rail). **The "decorative pads" failure class from the electrical walk dies with it**: nothing needs enabling.
- **`BACKUP_TRICKLE` (`0x51`) is removed from the register map after a lifetime of hours** — supercap charging is a solder-jumpered resistor from 3V3, which is *more* coin-cell-proof than any register: no write can ever charge a primary cell.
- **What is genuinely given up:** ±1ppm → **±20ppm-class initial tolerance** (~30 s/year → ~1 min/month at 25°C; the cold parabola adds as it always did — guide §1.2 rewritten); **the deferred temperature-compensation option dies** (no offset register to trim — the ATtiny's die sensor stays free but its correction target is gone); ~+25mm² of board (TSSOP-8 + crystal + diodes vs. one ceramic).
- **New delivery-default trap, third of its class: CLKOUT ships enabled at 32kHz** (open-drain, burning backup-scale current and radiating). Firmware disables it unconditionally at init.
- **Vendor identity — resolved same day:** both vendors' datasheets are now read and gate-identical (claims row 44). **Primary: Shanghai Belling (C194063, $0.056)** — the cheaper part, with M5Stack's entire product line as field evidence; GATEMODE (C269877, $0.108) is the equally-verified alternate.
- **Net: −$1.67/board, the sole-source part becomes commodity multi-source silicon with two gate-verified vendors, and the BOM falls ≈ $4.50 → ≈ $2.90.**

*(Historical section follows.)*

**RTC part — changed to RV-3028-C7, but the reason given for changing it was false (datasheet-verified 2026-07-15).** The user guide advertised a "factory-calibrated, temperature-compensated realtime clock," while the PCF85063A originally speced is a plain crystal RTC with a single-point offset register. The claim and the part contradicted each other — that much was correct. **The audit then resolved this "by changing the part rather than retracting the claim," asserting that RV-3028-C7 "has an integrated TCXO (~±1ppm)." It does not. That assertion was wrong, and the part change did not fix the problem it was made to fix.**

- **What the datasheet actually says.** "Time accuracy: Factory calibrated to **±1 ppm @ 25°C**" — a calibration figure at a *single temperature*, not compensation across temperature. §4.15 is explicit that the offset correction "has only the effect of shifting the time vs. temperature curve vertically up or down. **It has no effect on the time vs. temperature characteristics of the final frequency.**" The oscillator parameters give the curve: **−0.035 ppm/°C² × (T−25)²**, turnover 25 ±5°C — a textbook *uncompensated* 32.768 kHz tuning-fork parabola.
- **So the swap changed nothing on this axis**, because both parts use the same class of crystal and the parabola is a property of the crystal cut, not the chip. Real compensation requires a temperature sensor and active correction, which this part has no more than PCF85063A did. Resulting drift: ~20 s/month at 10°C or 40°C, **~57 s/month at 0°C, ~111 s/month at −10°C**.
- **Resolved the way it should have been the first time: retract the claim.** The user guide no longer says "temperature-compensated"; it states the ±1 ppm @ 25°C figure, publishes the drift table, and explains that relative-time scheduling is immune to it and a re-syncing host doesn't care — which is most integrators. **This was one of the options considered and passed over on the strength of the false TCXO claim.**
- **Where the claim came from, and the competitive problem it exposes (found while verifying an unrelated claim, 2026-07-15).** Witty Pi 4 L3V7's manual leads with: "**Factory calibrated and temperature compensated realtime clock with ±2ppm accuracy**." The user guide's original wording — "factory-calibrated, temperature-compensated realtime clock" — is **very nearly that sentence**. The claim appears to have been carried over from a competitor's feature list, describing a capability they have and PowerMOD never did. That is how it survived review: it read like a specification because it *was* one — someone else's.
  - **And they genuinely have it.** Their manual: "firmware also makes temperature compensation for the crystal," using a **dedicated LM75B sensor with 0.125°C resolution**. This is not marketing; it is a sensor plus a firmware correction loop.
  - **So PowerMOD is now measurably worse than Witty Pi on RTC accuracy over temperature** — their ±2ppm *compensated* against our uncompensated parabola (~22ppm at 0°C, ~43ppm at −10°C). **On the exact axis this product exists for: waking at the right time, outdoors, unattended.** Worth stating plainly, because the rest of this spec is built on being better than Witty Pi, and here we are not.
  - ~~The fix costs nothing in parts and is deliberately deferred, not foreclosed~~ — **FORECLOSED by the RTC reversal (2026-07-15): the BM8563 has no offset register, so the correction target is gone.** The ATtiny's die sensor remains free, and firmware can still compensate *wake times* arithmetically — but the free-running clock is no longer trimmable. Restoring the option means restoring a trimmable RTC (PCF85063A-class, +$0.43), which is now the recorded price of temperature compensation. (Historically: everything needed was on the board — the ATtiny's `TEMPSENSE0`/`TEMPSENSE1` in SIGROW, and RV-3028-C7 exposed a programmable offset (`EEOffset`: ±0.954 ppm steps, ±244 ppm range, non-volatile). Firmware reads temperature, evaluates the known parabola, and writes the offset periodically — **zero BOM, zero pins, no new hardware.** This is exactly Witty Pi's approach; they simply spend ~30¢ on a dedicated LM75B for better sensor accuracy.
  - **What it would actually buy, since the benefit is bounded by sensor accuracy, not by the idea:**

    | At 0°C | Uncompensated | ATtiny internal sensor (free) | LM75B-class (~30¢) |
    |---|---|---|---|
    | Error | 21.9 ppm | ~8.8 ppm (±5°C sensor) | ~3.5 ppm (±2°C sensor) |
    | Drift | 57 s/month | ~23 s/month | ~9 s/month |

  - **Not adopted, deliberately.** The claim is retracted rather than implemented, because the drift is **irrelevant in relative-time scheduling** — the recommended mode, immune by construction — and any host that syncs from a network corrects it faster than it accumulates. The real cost was never the part; it is firmware plus a thermal characterisation that would have to be validated on hardware, spent on a problem the recommended usage doesn't have.
  - **The door is held open at no cost.** Should wall-clock accuracy outdoors ever become a genuine requirement rather than a sentence copied from a competitor, **this is a firmware release, not a board revision** — no BOM change, no pin budget, no schematic work. That is the reason to record the mechanism here in full rather than just noting the gap.
- **Keep RV-3028-C7 anyway — it earns its place on grounds that are real, just not the one it was chosen for:** **40 nA** at 3V (verified; ~5× better than PCF85063A-class, and load-bearing for the coin cell/supercap question); **integrated XTAL** so no external crystal or load-cap matching; **±1 ppm factory calibration** at 25°C with no user trim; a dedicated **VBACKUP pin with automatic switchover and trickle charger** — precisely the coin-cell interface this design needs; and a **native UNIX time counter**, which matches the register map's uint32 epoch format directly rather than requiring BCD conversion in firmware. **If genuine temperature compensation is ever wanted, it is a different part entirely** (a real TCXO RTC) — verify against a datasheet before committing, and note the audit's whole point is that this was not done last time.

**Two supported operating modes, one board:** (1) **LiPo/UPS mode** (default/primary) — full UPS behavior as described throughout this spec (charging, voltage monitoring, emergency cutoff, hysteresis). (2) **Mains-only mode** — no battery connected; PowerMOD functions purely as a scheduled power switch (wake/cut on command or schedule), with none of the UPS-related behavior (no voltage monitoring, no emergency cutoff, no charging) applicable since there's no battery to protect or charge. Both modes share the same board and protocol — mode is simply a function of whether a LiPo is physically connected, not a separate configuration to set. See also: RTC/coin-cell backup below, which applies to both modes.

- **How "is a LiPo connected" is actually determined — was undefined, now resolved (audit finding).** The claim that mode "is simply a function of whether a LiPo is physically connected" quietly assumed a detection mechanism that this spec never defined. It is load-bearing in two places at once: it selects the operating mode, *and* it drives the Battery LED's "Off = no battery present" state (Section 9). **The naive implementation — treat a very low voltage reading as "absent" — cannot distinguish an absent battery from a deeply discharged one**, which are different situations that need different signals to the operator (Off vs. fast-blink-critical). ~~**Resolved: use the power-path IC's own battery-detection function**~~ — **this resolution died with the charger reversal (2026-07-15) and was re-resolved.** It was closed by pointing at MCP73871's `STAT1`/`STAT2` decoding; TP4056 has no such function, and neither does Witty Pi's equivalent design.

**Re-resolved: pull TP4056's `CE` low and run a ~500ms decay-delta test on the VBAT node.** ~~No cell → the 4.7µF bypass collapses through a bleed resistor in milliseconds~~ — **the BOM walk falsified that (2026-07-15): the only bleed path is the 1.33MΩ sense divider, so τ = 4.7µF × 1.33MΩ ≈ 6.2 seconds.** A dedicated fast-bleed resistor would fix the time constant and destroy the ~5µA standby floor, which is the wrong trade. **The test that actually works: sample VBAT, wait ~500ms with `CE` low, sample again — an absent cell's node sags ~300mV (7.6% of a 6.2s decay); a real cell moves under a millivolt.** Still a positive test, still one GPIO; it just takes half a second instead of an imagined millisecond. Datasheet basis: *"Pulling the CE pin to low level will put the TP4056 into disable mode"* (Pin 8).

**This is better than what it replaces, not merely equivalent.** The original objection was that a voltage threshold "cannot distinguish an absent battery from a deeply discharged one." A `CE` test is a **positive measurement of the cell's presence** — a discharged cell still holds the node up, an absent one cannot — so it answers the exact question the threshold approach could not. **Cost: one GPIO and one resistor**, and the same pin doubles as firmware VPCC (see the power-stage section).

**Caveat, stated because it is not derived from any datasheet: this technique is an invention of this audit, not a vendor-sanctioned pattern.** It must be validated on hardware before the LED scheme and mode selection are allowed to depend on it. Everything else in this decision rests on quoted datasheet behaviour; this does not.

## Interface

- **Data/command:** I2C over a small connector (STEMMA-QT-style 4-pin), not a full GPIO header.
- **I2C bus voltage — never specified anywhere, and it is a host-damage hazard (audit finding, 2026-07-15).** The connector was chosen for *mechanical* reasons — small, not a 40-pin header, no host-specific footprint (Section on connector/mounting). **Its electrical implications were never traced.** No document states the bus voltage, the MCU's supply rail, or where the pull-ups go. Three things now need deciding together, and they are coupled:
  - **STEMMA-QT/Qwiic is a 3.3V ecosystem convention**, and its 4th pin carries VCC. Adopting the connector's *shape* while ignoring its *convention* invites someone to plug a 3.3V Qwiic device into a port that may not be at 3.3V.
  - **The MCU's rail is unstated.** ATtiny1617 runs 1.8–5.5V and would naturally sit on SYS, which is **3.0–5.5V depending on cell charge and mains presence** — i.e. a *moving* logic level.
  - **The hazard: I2C is open-drain, so the pull-ups set the bus voltage.** If PowerMOD fits pull-ups to its own SYS rail, the bus idles at up to ~5.5V. **A Raspberry Pi's I2C GPIO is 3.3V and not 5V-tolerant — this destroys the host.** The flagship use case is the failure case.
  - **This is the same failure as the USB-C CC resistors and the MCP73871 `THERM` bias**: a connector decision whose electrical requirements are invisible in a requirements document and fatal on a board — except this one damages the *host*, not PowerMOD.

**Resolved (2026-07-15): PowerMOD is a 3.3V I2C device. No pull-ups fitted; logic section on a dedicated 3.3V LDO.**

1. **PowerMOD fits no I2C pull-ups at all.** The host's own pull-ups define the bus. PowerMOD drives SDA/SCL open-drain only and must never *source* current onto them — which is what an I2C peripheral should do regardless, and it means PowerMOD cannot impose a voltage on someone else's bus.
2. **The logic section runs from a fixed 3.3V LDO, not from SYS.** **This is not optional, and the reason is the sharp part:** ATtiny1617's `VIH = 0.7 × VDD` and its TWI has **no SMBus-style fixed input levels** (its SMBus support is timing only — timeouts, SDA hold, quick command). So a SYS-powered MCU has a logic threshold that *moves with the rail*, and against a 3.3V host bus the breakpoint is **4.71V**:

   | MCU VDD (= SYS) | VIH | 3.3V bus |
   |---|---|---|
   | 3.0–4.2V (on battery) | 2.10–2.94V | reads HIGH ✅ |
   | ~4.7V (on mains) | 3.29V | **on the edge** |
   | 5.0–5.5V (on mains) | 3.50–3.85V | **reads LOW — bus dead** ❌ |

   **The bus would work on battery and fail on mains** — intermittent, environment-dependent, and it would present as a flaky connector for weeks before anyone suspected logic thresholds. At a fixed 3.3V, `VIH` = 2.31V and the bus is solid at every cell voltage.
3. **Two problems this LDO also solves, which is most of why it earns its place:**
   - **The battery ADC needs a stable reference.** With VDD tracking SYS, using VDD as the ADC reference makes every battery reading scale with the rail — the cutoff and recovery thresholds would drift with mains presence. A fixed rail (or the internal bandgap) is required regardless of the I2C question.
     - **↪ PY32F003 (instock-parts branch) — FIRMWARE REQUIREMENT to preserve this.** The ATtiny provided a true internal fixed ADC reference; the PY32's reference is **VDDA (= the 3.3V LDO rail)**, which holds 3.3V until the cell empties and then sags with LDO dropout — so raw readings would drift exactly as warned here, worst at the low-battery cutoff where accuracy matters most. **Firmware must sample the internal 1.2V bandgap (VREFINT) every conversion, compute the true VDDA, and rescale VBAT_DIV/VBUS_DIV** (the standard STM32/PY32 technique); this recovers the ATtiny's fixed-reference accuracy. **Accuracy ceiling (datasheet Rev 1.7 Table 5-25):** VREFINT is 1.17–1.23 V with **no per-part cal constant**, so the *absolute* result is ~±2.5% (≈ ±75 mV at the 3.0 V cutoff). The sampling's job is to recover VDDA *sag* — the failure mode this bullet warns about — not to add sub-percent absolute accuracy; ±2.5% is adequate for the 0.1 V-granular voltage thresholds, and the relative trend (tracking a cell draining) is much tighter. The 1M/330k divider (below) is unchanged. *The ATtiny reasoning in this bullet stands and is the rollback target if a well-stocked AVR ever returns — see the MCU note at the cell-bottom trace below.*
   - **It makes the STEMMA-QT connector honest** rather than merely the right shape — that ecosystem is 3.3V by convention, and PowerMOD now matches it in fact.
4. **⚠️ Consequence: a 5V host does not merely fail — it damages PowerMOD.** 5V on a pin with a 3.8V absolute maximum. **5V hosts require an external level shifter**, and the Scope section's host claims are narrowed accordingly (below). This must be stated loudly in user documentation, not buried: it is a "your board is now dead" outcome from an action that feels routine.
5. ~~**Confirm during schematic work:** the LDO must be low-Iq (single-digit µA)~~ — **CLOSED 2026-07-15: XC6206P332MR (Torex, [LCSC C5446](https://lcsc.com/product-detail/Dropout-Regulators-LDO_Torex-Semicon-XC6206P332MR_C5446.html)), SOT-23, $0.096@150, 211k in stock.** Verified: **Iq 1µA typ** — on battery standby the converter is disconnected and the charger is unpowered, so **this 1µA plus the battery-sense divider (~3µA — the largest term, see Interface) plus the sleeping MCU is the board's standby floor**, which is why the spec is Iq and not accuracy. **Dropout 250mV @ 100mA, and CMOS dropout is resistive (~2.5Ω)** — at the logic section's ~15mA it is **~38mV**, and that number is load-bearing (see the cell-bottom trace below). Input range to 6.0V covers a compliant 5.5V USB-C source. 200mA is 10× the load. **Clone note, same rule as the TP4056:** "662K" clones exist from **$0.0074** — second-sourcing is trivial, but qualify the specific vendor's part, not "a 662K."
   - **The cell-bottom trace, all datasheet numbers — the rail sags gracefully and stays legal.** Cell at the 3.0V cutoff → minus Q2's 25mV → minus 38mV dropout → **MCU VDD ≈ 2.93V** (ATtiny operating range 1.8–5.5V, fine). A host still driving I2C at 3.3V is checked against the ATtiny's **`VPIN` absolute max = VDD + 0.5V = 3.43V** — legal with **130mV margin at the single worst point in the discharge curve**. **An LDO dropping ~300mV at load would break exactly this** (ceiling 3.15V < 3.3V bus), which is why light-load dropout was a requirement and not a nicety.
     - **↪ PY32F003 (instock-parts branch) — FIRMWARE REQUIREMENT to preserve this. The ATtiny's +130mV margin does NOT transfer.** The PY32's I/O (including the I2C pins PB6/PB7 — "COM" structure, **not** 5V-tolerant) has abs-max **VIN = VCC + 0.3V** (datasheet Rev 1.7, Table 5-1), vs the ATtiny's VDD+0.5V. At the same VDD ≈ 2.93V corner that ceiling is **3.23V**, so a 3.3V host bus is **~70mV *over* abs-max** — the clean +130mV margin becomes a ~70mV overshoot onto the pin's ESD clamp (survivable via the host's pull-up current-limit, but out of spec). **Firmware must cut host power — and therefore the host's I2C drive — while VDD ≥ 3.0V**, i.e. set the low-battery host-off threshold a hair above the 3.0V cell cutoff so a 3.3V bus is never present once VDD has sagged below 3.0V. No board change — the low-battery shutdown already exists; this only constrains its threshold. (PY32 runs to 1.7V, so the MCU itself is fine lower; this is purely about the host-driven pins.) *The ATtiny analysis in this bullet is retained verbatim as the rollback reference.*
   - **Also corrected here (stale from the charger reversal): the pull-ups on the charger status pins.** ~~`STAT1`/`STAT2`/`PG`~~ → **TP4056's `CHRG`/`STDBY` are open-drain and their pull-ups go to the 3.3V rail**, not SYS — same reasoning as before, surviving the part swap. The VBUS mains-detect is a divider to an ADC pin and needs no pull-up.

- **Battery-sense divider — required, and never specified (audit finding).** The cell runs 3.0–4.2V; the ADC now sits on a **3.3V** rail. **A full 4.2V cell exceeds both the ADC's range and the pin's absolute maximum** — battery sensing needs a resistor divider, which no document mentions. It also has a standing quiescent cost (a 2×100kΩ divider draws ~21µA — around 7% of the board budget; 1MΩ resistors cut that but raise the ADC's source impedance, which AVR ADCs care about). **Size it against the ADC's input-impedance requirement and the quiescent budget together**, since those pull in opposite directions.
  - **Sized and committed (spec walk, 2026-07-15): 1MΩ top / 330kΩ bottom (~1.33MΩ total, ≈3.2µA at a full cell), with 100nF across the bottom leg as the ADC's sampling reservoir** — the cap is what lets a high-impedance divider feed an ADC that wants ~10kΩ sources: the ADC samples the cap, the divider refills it between conversions. Exact ratio is re-checked against the chosen internal reference at schematic time; the impedance and the cap are the decision.
  - **This drain was missing from every standby-floor statement, which is why it's recorded here.** The floor was quoted as "LDO 1µA + sleeping MCU" — the divider is ~3µA, i.e. **the largest single term**. Honest floor: LDO 1µA + divider ~3µA + MCU sleep ≈ **~5µA class before LED duty**. For scale, a 2000mAh LiPo self-discharges at the equivalent of ~50–140µA — the divider is ~4% of what the cell loses to itself, so it changes no conclusion; but a floor that omits its own largest term isn't a floor.
- **Power output to host:** USB-C, fixed at basic 5V, no PD negotiation (predictable, matches Witty Pi's own approach). The A64's native barrel-jack input is bridged with an off-the-shelf USB-C-to-barrel-jack adapter (5V, non-PD variant) rather than building a bespoke barrel-jack output onto the board — confirmed these adapters are a real, common commodity product. A64 requires center-positive polarity — confirm on the specific adapter chosen, not universal across the category.
- **Power input (mains):** USB-C, also fixed at basic 5V, no PD negotiation.
- **USB-C CC resistors — omitted entirely from this spec, now an explicit BOM requirement (audit finding).** "No PD negotiation" is not the same as "no CC configuration," and the distinction is easy to lose. Even a dumb 5V USB-C port needs its CC pins terminated correctly or it does not work at all:
  - **Input port:** 5.1kΩ pulldowns (Rd) on CC1 *and* CC2. Without them a USB-C charger will never enable its output, and the board is simply dead on arrival with a modern supply. This is the single most common reason a first-spin USB-C board doesn't power up.
  - **Output port:** an appropriate Rp pull-up to advertise available current to the host, matched to the actual output rating settled below.
  - Four resistors, cents total. Called out explicitly here rather than left to be absorbed from a reference design, because it is exactly the kind of thing that is invisible in a requirements document and fatal on a board.
  - **Interaction with the 3.3V jumper (Section on power stage):** in 3.3V mode the output port emits 3.3V while its CC resistor still advertises a nominal 5V USB source — out of USB-C spec. Nothing plugged into a USB-C port expects 3.3V, so this is a labeling/documentation matter rather than a hazard (the 3.3V case is served by the raw VOUT header in practice), but it should be stated rather than discovered. Consider whether the CC advertisement should be disabled in 3.3V mode during schematic work.

### What the CC resistors do to the port-swap risk — better than "accepted", short of "solved" (audit finding, 2026-07-15)

**The port-swap decision was made without CC resistors in the design, and adding them changes its conclusion.** The Interface section accepted the swap risk on silkscreen alone, judging that "backfeeding into the boost converter's output (charger into the output port) is the dangerous direction." **Correct CC implementation makes most of that hazard electrically impossible**, because of a USB-C rule the original analysis had no reason to consider: **a source only energises VBUS once it detects a sink's Rd pulldown.**

| Mis-plug | What CC sees | Outcome |
|---|---|---|
| Compliant **C-to-C charger → output port** | charger's Rp vs. our Rp | No Rd anywhere → **the charger never turns VBUS on. Nothing happens.** |
| **Host → input port** | host's Rd vs. our Rd | No source → no-op, as already documented. |
| **USB-A charger + A-to-C cable → output port** | USB-A has no CC gating at all | **5V is live on VBUS regardless → still backfeeds.** |

- **The residual risk is USB-A sources, and that is the common case** — most people own a USB-A charger and an A-to-C cable, and a legacy USB-A port drives VBUS unconditionally. So the hazard is narrowed to one scenario rather than eliminated. **Silkscreen still earns its place; it is just now guarding a much smaller door.**
- **The genuinely dangerous version is narrower still, and worth naming: 3.3V jumper mode + a USB-A backfeed puts 5V onto a 3.3V host.** In 5V mode a backfeed is 5V meeting 5V — benign, and TPS63020's load disconnect blocks VOUT→VIN while off anyway. **In 3.3V mode it is an overvoltage event on someone else's hardware.** This is the case to weigh if reverse-protection is ever revisited.
- **Note the shape of this, because it is the inverse of the usual finding:** the CC resistors were added purely to make the board *work*, and they turn out to also mitigate a hazard the spec had given up on. The original port-swap analysis wasn't wrong — it was reasoning about a board whose CC pins were unconnected, which is the board the spec described.

### USB-C current advertisement — PowerMOD's output current does not fit the spec's quantisation (audit finding)

**Rp is quantised: Default (500/900mA), 1.5A, or 3.0A. There is no ~1.2A option**, and ~1.2A is what the power budget actually allows (Section on power stage).

> **Re-checked after the charger reversal (2026-07-15) — the decision holds, but its reasoning was wrong and had to be rebuilt.** Output is no longer a single number: it is **~2.7A on mains and ~1.0–1.5A on battery through PH2.0**. So "~1.2A is what the budget allows" is simply false now, and on mains alone **1.5A (Rp=22k) would finally be honest**.
>
> **It still fails, for a better reason.** An advertisement is a *guarantee*, and it cannot be conditional on which source happens to be connected — a compliant sink reads Rp once and draws accordingly, including at 3am on battery with the cell near cutoff, where PowerMOD delivers **~1.0A**. **Advertising 1.5A would promise, in the worst configuration, half again more than the hardware can supply — and the worst configuration is the one a UPS exists for.**
>
> **Rp = 56k (Default) stands.** Note what changed: the old reasoning would have *flipped* on the new numbers, because it compared the advertisement against a typical figure. The rebuilt reasoning compares it against the **floor**, which is the only comparison an advertisement can survive.
- **Advertising 1.5A (Rp=22k) over-promises.** A compliant sink may then draw 1.5A without any negotiation — more than PowerMOD can deliver, producing brownout at exactly the moment of peak demand.
- **Advertising Default (Rp=56k) under-promises**, capping a compliant sink at 500–900mA against a real capability of ~1.0–1.35A.
- **Resolution: advertise Default (Rp=56kΩ), and accept the under-promise.** Over-advertising is a brownout; under-advertising is a limitation. **In practice it costs almost nothing for the documented hosts:** the flagship A64 takes power through a dumb USB-C-to-barrel adapter that ignores CC entirely, and Pi-class boards draw what they need without negotiating. **The advertisement matters only for strictly compliant sinks, which are not the target — but under-promising is the only honest way to be wrong.** Confirm exact Rp values against the USB-C spec during schematic work.

### USB-C input: PowerMOD ignores what the source advertises, and this must be a documented requirement

> **Re-examined after the charger reversal (2026-07-15). Every conclusion below survives; the mechanism behind each one is gone.** This is the most useful thing in the section, so it is recorded rather than rewritten:
> - **"Draws whatever it wants regardless of the advertisement" — still true, and now more so.** There is no `SEL` pin, no VPCC, no ICLC: **TP4056 + OR has no input current limiting of any kind.** The old text's "up to 1.8A" becomes "up to whatever the source will give," so the **≥2A supply requirement stands and hardens.**
> - **"Graceful failure in LiPo mode" — still true, but NOT the same outcome, and an earlier version of this correction claimed it was.** VPCC no longer exists, and neither does its load-*sharing*: **the OR is winner-take-all — it cannot blend sources, so "the battery covers the shortfall" is MCP73871 ideal-diode language with no referent in this topology.** What actually happens: mild sag → the input still carries everything, firmware backs charging off via `CE`, and the host is insulated by the buck-boost's regulation (not by the battery). Severe sag → a **handover**: the whole load moves to the cell. Host unaffected in both; the symptoms differ — *slow charging* in the first, **battery discharging while plugged in** in the second. See the OR stage for the sustained-body-diode consequence.
> - **"Mains-only mode is *harder*, not more forgiving" — still true, and for the same underlying reason.** With no cell, nothing backfills. The old text's "'if possible' is doing real work in that sentence" applies verbatim to the body diode: no battery, nothing to forward-bias, host browns out.
> - **One property is genuinely lost:** VPCC *throttled charging* to protect the input. The OR does not — it just hands the load to the battery. **So under a weak supply the cell now discharges on mains**, where MCP73871 would have reduced charge current first. `CE`-based firmware arbitration is the intended substitute (see the power-stage section), and it is a substitute, not an equal.
>
> **That a section written entirely around one part's pins survived that part's removal unchanged is worth noticing.** The conclusions were about *the system's behaviour under an undersized supply*, and were never really about `SEL` — the part was the evidence, not the reason. The MCP73871-specific text below is retained on that basis.

**The `SEL` pin forces a choice with no middle** (MCP73871 datasheet — **superseded, retained as the evidence that produced the conclusions above**): **SEL high** = "capable of providing 1.65 (typical) total amperes… limits the input current up to 1.8A"; **SEL low** = "adhering to the current limits governed by the USB specification" (100/500mA via `PROG2`).
- **SEL must be tied high.** SEL low caps input at 500mA → ~2.5W → an output around **0.45A**, which would gut the product.
- **Consequence, stated plainly: PowerMOD presents Rd (so any source turns on) and then draws up to 1.8A regardless of what that source advertised.** It does not sense the source's Rp. This is not USB-C compliant, and it is universal practice for this class of board — but it means **PowerMOD's input requires a 5V supply rated ≥2A, and nothing in this design has ever said so.**
- **The failure is graceful rather than dangerous — but only in LiPo mode, and that asymmetry was missed until VPCC was actually read (2026-07-15).** MCP73871 §3.3: "If the voltage on the IN pin drops to a preset value… due to a limited amount of input current or input source impedance, **the battery charging current is reduced. If possible, further demand from the system is supported by the battery.**"
  - **In LiPo mode this is genuinely graceful, and more so than assumed:** an undersized supply sags, charging throttles, **and the battery covers the shortfall**. The host never notices. The visible symptom is a battery that charges slowly or never reaches full — which is why "why won't my battery charge?" should send an integrator to look at their charger first.
  - **In mains-only mode there is no battery to backfill.** "If possible" is doing real work in that sentence: with no cell fitted, VPCC can only reduce a charge current that is already zero. **An undersized supply then sags until the host browns out.** The ≥2A requirement is therefore *harder* in mains-only mode than in LiPo mode — the opposite of the intuition that the simpler configuration is the more forgiving one.
  - **Configure VPCC deliberately** — its threshold is set by a divider to the VPCC pin (1.23V reference), and the datasheet's own worked example sizes it for a 5V supply. Connecting VPCC to IN *disables* the feature, which for this design would be a mistake.
- **Port-swap risk (input vs. output, both USB-C):** identical connectors on both ports create real risk of a user plugging a charger into the host-output port. This is asymmetric — backfeeding into the boost converter's output (charger into the output port) is the dangerous direction and could plausibly damage the converter or upstream components; the reverse mistake (host into the input port) is just a no-op. **Decision for v1: clear silkscreen labeling only** — no physically distinct connector, no reverse-power protection circuitry. **(Revised 2026-07-15 — the conclusion stands but its premise changed: correct CC resistors make the compliant C-to-C mis-plug electrically impossible, narrowing this risk to USB-A sources only. See "What the CC resistors do to the port-swap risk" below. This analysis was written for a board whose CC pins were unconnected, which is the board this spec described at the time.)** Deliberate tradeoff: USB-C is the universal expectation for power in/out, and USB adapters (including the barrel-jack one already needed for the A64) are cheap and everywhere, so keeping both ports as USB-C maximizes general compatibility at the cost of relying on the installer reading the label correctly, particularly at first install or when a technician revisits the device in the field. Worth revisiting (distinct output connector, or a reverse-protection IC) if this ever causes a real field failure.
- **Raw power output pins — added, alongside USB-C.** A small unpopulated header exposing VOUT + GND directly (same internal rail as the USB-C output, no new circuitry), for hosts without a USB-C power input (many bare-metal MCU dev boards use a VIN pin, barrel jack, or direct header power instead). Precedented by Witty Pi's own unpopulated header (their P3, breaking out VOUT/CATHODE for exactly this purpose). Cheap to add since it's just exposing an existing rail, not new regulation — see the extensibility note below for the real constraint this doesn't solve.

## Power stage topology and voltage flexibility — resolved, adopted for v1

**Decision: buck-boost converter (not plain boost), field-configurable output voltage via jumper/solder-bridge, default-ships-at-5V.**

**Why buck-boost, not plain boost, from v1:** A plain boost converter can only step voltage *up*, which is sufficient for a fixed 5V target (always above the LiPo's 3.0–4.2V range) but cannot support a 3.3V target — the LiPo's voltage range straddles 3.3V, so part of the discharge curve would need step-down behavior a boost converter physically cannot provide. Supporting 3.3V requires a genuinely different topology (buck-boost), not just a different-value boost converter — the supporting passives (inductor, feedback divider, capacitors) are calculated for the specific voltage relationship, so a plain-boost-to-buck-boost change is a real subcircuit redesign, not a component swap.

**Why do this now instead of deferring:** the buck-boost topology's added cost (a small number of extra passives, marginally more board area, more verification effort across buck/boost/transition operating modes) is paid once either way — adopting it now avoids ever having to redesign the power stage later if a 3.3V variant is wanted. Deferring would mean building plain-boost now and buck-boost later, paying the design/verification cost twice instead of once.

**Field-configurable voltage selection, not just a BOM-time choice:** many buck-boost ICs support output voltage selection via a simple strap pin or resistor-divider values, which can be exposed as a physical jumper or solder-bridge rather than requiring different components at manufacturing time. This is adopted for v1 — genuinely low component cost (cents), and the buck-boost IC's configurability makes it close to free once the topology decision above is already made.

**Real risk accepted, consistent with existing precedent:** a field-configurable voltage jumper introduces the same class of risk already accepted for the USB port-swap decision (Interface section) — a user could misconfigure the jumper (e.g., leave it at 5V after repurposing the board for a 3.3V-only host) and damage their host. **Resolved with the same proportionate response already used elsewhere in this spec: clear silkscreen labeling at the jumper location, no additional lockout or auto-detection circuitry.** Ships default at 5V (matching the primary Linux SBC use case). The main added cost of this feature is not componentry but ensuring the jumper's current position is genuinely easy to visually confirm before connecting a host — a documentation/silkscreen-clarity task, not a BOM cost.

**Net effect on "does this work for low-power MCUs" (the question that prompted this):** yes, meaningfully more so than the original plain-boost design — a 3.3V-target host is now a jumper setting, not a redesign. Combined with the raw VOUT/GND header (above) and the already-portable I2C protocol layer, PowerMOD's electrical design now generalizes well beyond the primary Linux SBC target with no compromise to that primary use case.

## Charger and power path — REVERSED 2026-07-15: back to TP4056, behind a discrete PFET OR

> **This section supersedes "Charger and power path — TP4056 replaced with a power-path IC" below, which is retained in full as reasoning history.** The superseded section's *architecture* description is still correct. Its **part-selection conclusion is not**, and the error is instructive enough to keep visible.

**What was wrong.** The audit disqualified TP4056 because "it has no SYS rail — the load hangs permanently off the BAT pin," so load current corrupts charge termination and hot-removal browns out the host. **Every one of those statements is true of TP4056 *alone*, and false of TP4056 behind an OR-ing stage.** With a power OR in front, the load hangs on the merged system node, never on `BAT`. On mains the cell is reverse-biased out of the path and TP4056 sees *only* charge current — clean termination. Off mains, TP4056 isn't charging at all. **Charge and discharge become mutually exclusive by construction**, which dissolves the exact defect the part was rejected for.

**This is the audit's own recurring error, committed by the audit.** A defect belonging to a *topology* was attributed to a *part*, because the words sat next to each other — the same shape as the thermistor/connector, load-switch/power-path, and TCXO findings catalogued throughout this document. The tell was available and missed: this spec's own buck-boost section already named the escape hatch ("*if 3A ever becomes a hard requirement… TP4056 charging the battery off to the side, with ideal-diode/PFET OR-ing*") without noticing it invalidated the disqualification three sections earlier.

**What prompted the re-examination:** the question "how does Witty Pi get away with this?" Their manual answers it directly — *"the battery voltage and 5V from USB-C **merge into the input voltage (VIN)**… Because VUSB-C is 5V and is always higher than VBattery (up to 4.2V), the power input from USB-C connector has higher priority. As long as the power supply is connected to USB-C, **the battery will not be drained**."* That is a voltage-OR, not a power-path IC. They pair it with a TP4056 and an MP3423 boost. **The architecture PowerMOD needs was shipping in the competitor the whole time.**

### Why this is strictly better here

| | MCP73871 (superseded) | TP4056 + PFET OR |
|---|---|---|
| Charger cost @100 | **$1.46** | **$0.084** |
| Input current cap | **1.5A total** (system + charge **combined**) | none — source-limited |
| 5V output on mains | **~1.3A** | **~2.7A** |
| Battery drained on mains? | **Yes, on peaks** (ideal diode supplements) | **No** — reverse-biased out of the path |
| Charge termination | clean (own SYS rail) | clean (OR isolates the load) |

**The charger was the single most expensive part in the power stage — ~3× the buck-boost.** That inverted the assumption this design was built on, and it was only discovered by pulling real distributor pricing instead of estimating. **Power stage falls ~$2.00 → ~$1.00 while mains output roughly doubles** (TP4056 $0.084 + 2× AON7407 $0.348 + NFET/resistors ~$0.02 + TPS63020 $0.54). **Revised up from an earlier ~$0.80** — that figure assumed AO3401A, which the FET analysis then disqualified. **The saving is ~$1.00/board, not ~$1.20; the extra ~$0.19 buys the solder-pad current path and ~13× thermal margin.** Cheaper and better at once is rare enough to be suspicious; the reason it happens here is that the $1.46 was buying *integration*, and the integration included a 1.5A input cap we never wanted.

**Two facts that killed the incumbent**, both from its own datasheet and both missed on first read:
- **`SEL` high "limits the total supply current to 1.8A (system power and charge current combined)."** The derate table below the superseded section spent that entire budget on the host and left nothing for charging. Because VPCC prioritises the load, the consequence isn't reduced output — **it's that charging starves.** A host drawing 1.2A leaves ~140mA to charge; push slightly harder and **the UPS never recharges after an outage**, which is the one thing it exists to do.
- **"The ideal diode becomes forward-biased and the battery may supplement the input current to the system load."** So under peak load the cell discharges *while on mains*, and the headline ~1.38A figure was only ever reachable **with a battery fitted**. In true mains-only mode the part could not deliver its own advertised number.
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

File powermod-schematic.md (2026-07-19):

# PowerMOD — Schematic (pin-exact netlist, v1)

Last updated: 2026-07-15
Status: **Complete pin-for-pin connectivity, ready for capture in any EDA tool.** This document *is* the schematic's source of truth; the EDA file transcribes it. Every IC pin number below is read from the part's datasheet (extraction noted per part); two jellybean pinouts are flagged as convention-verify-at-capture.
Sources: `powermod-spec.md` §Pre-BOM electrical walk (net map), `powermod-bom.md` (refs and values).

**Machine transcription: `hardware/netlist.py`** — the same connectivity as a Python data structure, with a validator (golden board-killer facts, pin counts, no singleton nets) and generators for `hardware/powermod.net` (import into pcbnew for layout) and `hardware/powermod.kicad_sch` (global-label-style schematic). **Verified with KiCad 10.0.4 (2026-07-15): ERC = 0 violations, and the netlist KiCad derives from the schematic's labels is connectivity-identical to `powermod.net` — 44 nets, same membership, proven by round-trip diff.** All footprint names verified to exist in the installed KiCad libraries (the TPS63020's VSON-14 footprint traced to a TI drawing; the LEDs moved to 4-pad PLCC4, the standard top-mount bicolor package). The §0 pin-order flags for XC6206/BSS138/J4/LED still stand — a footprint existing is not the same as the die being wired to it the way convention says.

> **⚠ MCU MIGRATION (instock-parts branch, 2026-07-18): ATtiny1617/1616 → PY32F003F18P6.** No well-stocked AVR exists at JLC in *any* package, so the MCU is now the **PY32F003F18P6** (ARM Cortex-M0+, TSSOP-20, LCSC C5379864). **The authoritative pin map is `hardware/netlist.py`, reproduced in the PY32 table at the top of §1.** This document's original **ATtiny1617 VQFN-24** tables, the pin *numbers* referenced throughout §2, the UPDI notes, and the 1.5V-reference note are **RETAINED VERBATIM AS THE ROLLBACK REFERENCE** — they are correct for the AVR and unmodified. What changed: only the MCU part + its pin numbers, UPDI→SWD programming, and **two firmware items** (ADC VREFINT calibration; I²C host-cutoff at VDD≥3.0V — see `powermod-spec.md` §Interface). **Net connectivity in §2 is unchanged** (same 45 nets; UPDI→NRST is the only swap), so every *net* mapping below still holds — read the §2 pin numbers as the ATtiny's, and the PY32 equivalent from §1/netlist.py.

## 0. Pinout provenance

| Part | Pinout basis |
|---|---|
| TP4056 (ESOP-8) | datasheet pin functions: 1 TEMP, 2 PROG, 3 GND, 4 VCC, 5 BAT, 6 STDBY, 7 CHRG, 8 CE |
| TPS63020 (VSON-14) | TI pin table: 1 VINA, 2 GND, 3 FB, 4-5 VOUT, 6-7 L2, 8-9 L1, 10-11 VIN, 12 EN, 13 PS/SYNC, 14 PG, pad PGND |
| AON7407 (DFN-8) | AOS top view: 1-3 S, 4 G, 5-8 D, pad = D |
| BM8563 (SOP-8) | Belling pin table: 1 OSCI, 2 OSCO, 3 INT, 4 VSS, 5 SDA, 6 SCL, 7 CLKOUT, 8 VDD |
| ATtiny1617 (VQFN-24) | Microchip Table 5-1 (full map below); TWI0 default SDA=PB1, SCL=PB0; UPDI=PA0 |
| XC6206 (SOT-23) | ⚠ convention (1 VSS, 2 VOUT, 3 VIN) — **confirm against the LCSC footprint at capture** |
| BSS138 (SOT-23) | ⚠ convention (1 G, 2 S, 3 D) — **confirm against the LCSC footprint at capture** |

## 1. MCU pin assignment

### 1a. PY32F003F18P6 (TSSOP-20) — CURRENT board (instock-parts branch)

Authoritative map = `hardware/netlist.py`. 17 signals + NRST + VCC/GND = all 20 pins (0 spare, like the 1616). Verified vs the LCSC C5379864 symbol.

| TSSOP-20 | Port | Signal | Mode / note |
|---|---|---|---|
| 1 | PA2 | `Q1_GATE_DRV` | output (+100k↓) — drives Q3 gate |
| 2 | PA3 | `CONV_EN` | output (+100k↓) — TPS63020 EN |
| 3 | PA4 | `VBAT_SENSE` (`VBAT_DIV`) | ADC_IN4 — 1M/330k + 100nF; **VREFINT calibration required** (see ADC note §1c) |
| 4 | PA5 | `VBUS_SENSE` (`VBUS_DIV`) | ADC_IN5 — same divider + requirement |
| 5 | PA6 | `CHG_CE` | output — TP4056 CE (100k↑VBUS = charge-by-default) |
| 6 | PA7 | `CHG_STDBY` | input, 10k↑3V3 — TP4056 STDBY |
| 7 | VSS | GND | |
| 8 | PA12 | `RTC_INT` | input (EXTI12), 10k↑3V3 |
| 9 | VCC | 3V3 | |
| 10 | PA13 | `LED_BAT_A` | output 560Ω — **shared with SWDIO** |
| 11 | PA14 | `LED_BAT_B` | output 560Ω — **shared with SWCLK** |
| 12 | PB5 | `CHG_CHRG` | input, 10k↑3V3 — TP4056 CHRG |
| 13 | PB6 | `SCL` (host bus) | **I²C1 SCL — hardware I²C slave** |
| 14 | PB7 | `SDA` (host bus) | **I²C1 SDA — hardware I²C slave** |
| 15 | PF4 | `LED_PWR_B` | output 560Ω — BOOT0 (output only; Hi-Z at reset → boots flash) |
| 16 | PF0 | `RTC_SDA` | bit-banged, open-drain — internal RTC bus |
| 17 | PF1 | `RTC_SCL` | bit-banged, open-drain — internal RTC bus |
| 18 | PF2 | `NRST` | reset — brought to J5.4 for connect-under-reset |
| 19 | PA0 | `LED_PWR_A` | output 560Ω |
| 20 | PA1 | `BUTTON` | input, internal pull-up |

**Programming: SWD** (SWDIO=PA13, SWCLK=PA14, NRST=PF2) on the 4-pin J5 header (GND/SWCLK/SWDIO/NRST). The 2 BAT LEDs share SWDIO/SWCLK, so a debugger must **connect-under-reset** (NRST=J5.4); UART bootloader (BOOT0=PF4) is the fallback.

**§1c. ADC reference (PY32).** Unlike the ATtiny's fixed internal reference, the PY32 references **VDDA (the 3.3V LDO rail)**, which sags at battery-empty. **Firmware MUST sample VREFINT (1.2V bandgap) each conversion to compute true VDDA and rescale** `VBAT_DIV`/`VBUS_DIV` — this recovers the ATtiny's fixed-reference accuracy. Divider unchanged.
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

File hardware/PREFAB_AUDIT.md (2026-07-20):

# PowerMOD mount board — pre-fab audit (2026-07-17)

Full verification of `powermod.kicad_pcb` (renamed from powermod_mount 2026-07-17) against `netlist.py`, datasheets,
and fab constraints. Method + findings recorded so a re-audit after any change
can rerun the same checks.

> **⚠ SNAPSHOT PREDATES THE MCU MIGRATION.** This audit was run against the **ATtiny1616** board (214 pads). The design has since migrated to the **PY32F003F18P6** (ARM Cortex-M0+, TSSOP-20, instock-parts branch, 2026-07-18) — so the "ATtiny1616 SOIC-20 ✓" pinout line, the ATtiny voltage-variant advice (-SN/-SFR), the `C614136` BOM row, and "J5 (UPDI header)"/UPDI programming step below are **historical, not current**. The current board is **226 pads**, J5 is a **4-pin SWD** header, and the PY32 min supply is 1.7 V. A fresh from-scratch production audit was run 2026-07-19 (USB-C CC, XC6206-MR pinout, BOM/CPL/DRU) — see that session; the authoritative electrical map is `netlist.py`.

## Checks performed and results
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

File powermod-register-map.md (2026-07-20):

# PowerMOD — I2C Register Map / Command Set

Last updated: 2026-07-15
Status: **Draft v1, protocol version 1. Ready for firmware implementation review.**
Source of truth: `powermod-spec.md`. This document defines the wire-level interface those decisions imply; where it had to decide something the spec left open, that is called out explicitly in the final section.

---

## 1. Conventions

> ### ⚠️ Electrical preconditions — read before wiring, not before coding
>
> **This document previously described the entire wire protocol without once stating the voltage it runs at.** A developer could implement every register correctly and destroy the board on first connection. The interface's electrical requirements belong in the interface document:
>
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

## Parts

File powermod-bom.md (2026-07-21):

# PowerMOD — Bill of Materials (v1 hardware)

Last updated: 2026-07-15
Status: **Draft, walked line-by-line 2026-07-15 (three findings: missing VBUS bulk, missing `INT` pull-up, and the `CE` timing claim falsified by this BOM's own values). Prices verified on LCSC 2026-07-15 at the stated tier unless marked ~estimated.**
Sources of truth: `powermod-spec.md` §Pre-BOM electrical walk (the net map this BOM implements) and §Appendix (claims register — every part capability cited there). This document adds nothing to the design; it is the transcription the spec was written to make boring.

> **⚠ MCU + 2 PARTS MIGRATED (instock-parts branch, 2026-07-18) — all now in JLC stock.** No well-stocked AVR exists at JLC in *any* package, so three parts changed. **The rows below show the CURRENT parts; the superseded parts are kept inline (and here) as the rollback reference. The authoritative BOM is `hardware/powermod_bom.csv` (generated from `netlist.py`).**
> - **U2 MCU: ATTINY1617-MNR (VQFN-24, C614176) → PY32F003F18P6** (ARM M0+, TSSOP-20, C5379864, ~22k stock). Two firmware items follow (ADC VREFINT calibration; I²C host-cutoff at VDD≥3.0V — see `powermod-spec.md` §Interface). PY32 pin map: `powermod-schematic.md` §1a.
> - **L1 inductor: Sumida CDMC6D28 (1.5µH, Isat 4.5A, OOS) → CYA0650-1.5UH** (C5189751, ~11k stock; **same 5.7mm land — no layout change**, Isat ~10A / 7mΩ). Strictly better; SPICE unaffected (same 1.5µH).
> - **SW1 button: C&K PTS647SK50 (OOS) → PTS647SN50** (C2799414, ~9k stock; identical PTS647 4.5×4.5 land).
> - **DNP/hand-solder: J3 (battery JST) and J5 (now a 4-pin SWD header, was a 3-pin UPDI header).**

---

## 1. Semiconductors — all datasheet-verified, all priced

| Ref | Part | Package | LCSC | Qty | Unit @100–150 | Role |
|---|---|---|---|---|---|---|
| U1 | **BM8563ESA** (SOP-8) | SOP-8 (= SOIC-8, 1.27mm) | [C269877](https://www.lcsc.com/product-detail/C269877.html) | 1 | **$0.108** | RTC, PCF8563-class. **Reversed from RV-3028 (−$1.67)**. ⚠ **FITTED PART = C269877 (SOP-8), not C194063.** The Belling C194063 is the **TSSOP-8** die (0.65mm pitch) — it does **not** fit this board's SOIC-8 land and was OOS at check; C269877 matches the footprint (~80k JLC stock). Both are gate-verified PCF8563-class (claims row 44). |
| U2 | **PY32F003F18P6** (Puya) — *was ATTINY1617-MNR (C614176), see migration banner* | TSSOP-20 | [C5379864](https://www.lcsc.com/product-detail/C5379864.html) | 1 | **~$0.31** | MCU (ARM Cortex-M0+, 64K/8K). 17 signals + NRST, 0 spare. Pin map: schematic §1a; +2 firmware items |
| U3 | **TPS63020DSJR** (TI) — adjustable, **not** 63021 | VSON-14 | [C15483](https://www.lcsc.com/product-detail/C15483.html) | 1 | **$0.54** | Buck-boost, 5V/3.3V out, load disconnect = host switch |
| U4 | **TP4056** (TPOWER) | ESOP-8 | [C382139](https://www.lcsc.com/product-detail/Battery-Management-ICs_TPOWER-TP4056_C382139.html) | 1 | **$0.084** | 1A LiPo charger, behind the OR |
| U5 | **XC6206P332MR-G** (Torex) | SOT-23 | [C5446](https://lcsc.com/product-detail/Dropout-Regulators-LDO_Torex-Semicon-XC6206P332MR_C5446.html) | 1 | **$0.096** | 3.3V logic rail. Iq 1µA |
| Q1, Q2 | **AON7407** (AOS) | DFN-8 3×3 | [C176756](https://www.lcsc.com/product-detail/C176756.html) | 2 | **$0.174 ×2** | Power-OR PFETs. 12.5mΩ @ Vgs −2.5V |
| Q3 | **BSS138** (onsemi) | SOT-23 | [C52895](https://www.lcsc.com/product-detail/MOSFET_FAIRCHILD_BSS138_BSS138_C52895.html) | 1 | ~$0.01 | Q1 gate level-shifter |

**Semiconductor subtotal: ≈ $3.74**

### ⚠ Do-not-substitute notes (each one is a documented failure mode)

- **U4 `TEMP` pin is GROUNDED.** The opposite of the MCP73871 this design once used — grounding *that* part's `THERM` kills charging permanently. Both instructions live in the spec; neither transfers.
- **Q1/Q2 substitutes must specify Rds(on) at Vgs = −2.5V.** AO4407A (`Vgs(th)`=3V) passes every bench test and fails in the field as the cell ages — it is **fully off** at the −3.0V worst case. Also note AON7407's `VGS` limit is **±8V**, not the usual ±20V.
- **U3 must be the adjustable TPS63020** — the 5V/3.3V jumper needs the external FB divider; the fixed-output 63021 cannot do it. `PS/SYNC` ties **low** (power-save on) or light-load efficiency collapses.
- **U5 clones ("662K", from $0.0074) and U4 clones are legitimate second sources — qualify the specific vendor's part, not the number.**
- **U1's `CLKOUT` ships ENABLED at 32kHz** (open-drain, burns backup-scale current, radiates) — firmware disables it unconditionally at init. Delivery-default trap #3; the RV-3028's `BSM`/`TCE` traps died with the part swap.
- **U1 substitutes must be checked for the 6.5V-independent I2C pin rating** (claims row 41) — the diode-OR's legality rests on it.

## 2. Power passives — values from the TI/TP4056 datasheets

| Ref | Value | Spec | Qty | Unit ~est | Note |
|---|---|---|---|---|---|
| L1 | **1.5µH** — CYA0650-1.5UH ([C5189751](https://www.lcsc.com/product-detail/C5189751.html)) | **Isat ~10A**, 7mΩ DCR | 1 | ~$0.26 | TPS63020 ref design. **Isat is the spec that matters** — switch limit 4A typ/4.5A max. *Was Sumida CDMC6D28 (Isat 4.5A, OOS); same 5.7mm land* |
| C-in | 10µF X5R ≥10V | 0805 | 2 | ~$0.02 | TPS63020 input, per datasheet |
| C-out | 22µF X5R ≥10V | 0805/1206 | 3 | ~$0.05 | TPS63020 output, per datasheet |
| C-bat | 4.7µF | 0603 | 1 | ~$0.01 | TP4056 `BAT` — **required for no-battery stability and the `CE` test** (with the 1.33MΩ divider it sets the test's τ≈6.2s — hence the 500ms decay-delta method) |
| **C-vbus** | **10µF X5R ≥10V** | 0805 | 1 | ~$0.02 | **Added by the BOM walk** — VBUS bulk: TP4056 `VCC` decoupling + hot-plug damping. The net had no capacitance at all |
| C-ldo | 1µF | 0402/0603 | 2 | ~$0.01 | XC6206 in/out |
| C-adc | 100nF | 0402 | 2 | ~$0.005 | Divider sampling reservoirs (VBAT, VBUS) |
| C-gate | 100nF | 0402 | 1 | ~$0.005 | Q1 gate-source (τ ≈ 5ms with R-gate) |
| C-vdd | 100nF | 0402 | 4 | ~$0.005 | Decoupling: U1, U2, U4, **U3 `VINA` (TI ref design — added at KiCad transcription)** |
| **Y1** | **32.768 kHz crystal**, CL per U1 (one oscillator cap is on-die — confirm CL split at layout) | 3215 | 1 | ~$0.08 | **New with the RTC reversal.** Guard-ring the layout |
| **D3, D4** | **1N4148WS** (silicon, nA leakage — deliberately not Schottky) | SOD-323 | 2 | ~$0.01 | RTC VDD diode-OR: D3←3V3, D4←backup pads. Legal per claims row 41 |
| **R-chg + JP1** | 1kΩ + solder jumper, **open by default** | 0402 | 1 | ~$0.002 | Supercap charge path. Open = coin-cell-safe; no register can close it |

## 3. Configured resistors — every value is load-bearing, from the net map

| Ref | Value | Net | Why this value |
|---|---|---|---|
| R-prog | **1.2kΩ 1%** | TP4056 `PROG` | Sets 1A charge current |
| R-cc-in ×2 | **5.1kΩ** | USB-C in CC1/CC2 (Rd) | Without these, **no USB-C charger ever powers the board** |
| R-cc-out ×2 | **56kΩ** | USB-C out CC1/CC2 (Rp) | Advertises Default (500/900mA) — deliberate under-advertise; the floor is ~1.0A |
| R-div ×4 | **1MΩ + 330kΩ** ×2 | VBAT→ADC, VBUS→ADC | **Identical ratios on purpose** — makes the Q1 comparison ratio-free. ~3.2µA / ~4µA |
| R-q1-pu | 100kΩ | Q1 gate → VSYS | Fail-safe: Q1 off, body diode carries (board degrades, never dies) |
| R-q1-s | **47kΩ** | Q3 drain → Q1 gate | Gate lands at 0.32×VSYS ⇒ Vgs ≈ −3.4V — **adequate by check, not luck** (part specified at −2.5V) |
| R-q2-pd | 100kΩ | Q2 gate → GND | Q2 on when VBUS absent |
| R-q3-pd | 100kΩ | Q3 gate → GND | MCU reset ⇒ Q1 off (defined state) |
| R-en-pd | **100kΩ** | TPS63020 `EN` → GND | **Defines the host rail during MCU reset.** Stated tradeoff: an MCU WDT reset power-cycles the host |
| R-pu ×5 | 10kΩ | `CHRG`, `STDBY`, internal SDA, SCL, **RTC `INT`** → 3V3 | TP4056 outputs and the RTC's `INT` are open-drain (datasheet: "requires pull-up resistor"). **`INT` pulls to 3V3, deliberately against the app manual's tie-to-VBACKUP advice** — an alarm asserting during a total outage would bleed the coin cell ~300µA into a pull-up serving a dead MCU |
| R-led ×4 | ~560Ω | LED cathodes ← MCU | ~2mA at Vf ≈ 2.1V |
| R28 | **100kΩ** | `CHG_CE` ↑ VBUS | **Charge-by-default (added 2026-07-16):** without it CE floats whenever PC4 is high-Z (reset, UPDI, unprogrammed MCU) — undefined charger state. Pull-up, not pull-down, so a dead-MCU board still charges; PC4 push-pull overrides. ~17µA only while on mains with PC4 driven low |
| R-fb ×3 | **180kΩ low; 1MΩ + 620kΩ high-side, JP2 across the 620k** | TPS63020 FB + jumper | **Closed at schematic (was TBD):** VFB=500mV → open = 5.00V (ships), closed = 3.28V (TI Table 3's own 3.3V values). ~2.8µA, only while the converter runs |

**Passives subtotal (all jellybean): ≈ $0.35**

## 4. Connectors and electromechanical — ~estimated, price at order

| Ref | Part | Qty | Unit ~est | Note |
|---|---|---|---|---|
| J1, J2 | USB-C receptacle, 16-pin, 5V-only class | 2 | ~$0.08 | Input and output — identical on purpose; silkscreen differentiates |
| J3 | JST **PH** 2-pin, top or side entry | 1 | ~$0.04 | Battery. **2A rating is the connector's, not the board's** |
| J4 | JST **SH** 4-pin (STEMMA-QT/Qwiic) | 1 | ~$0.06 | I2C. **Pin 4 (VCC position) is NC — deliberate** |
| SW1 | Tactile switch, SMD — **C&K PTS647SN50** ([C2799414](https://www.lcsc.com/product-detail/C2799414.html)) | 1 | ~$0.34 | The button. *Was PTS647SK50 (OOS); identical PTS647 land* |
| D1, D2 | **Bicolor LED, red/green only** | 2 | ~$0.04 | **Blue/white (Vf≈3V) have no headroom on a 3.3V rail** — this is a requirement, not a preference |
| J5 | **SWD: 1×4 header** (GND/SWCLK/SWDIO/NRST), DNP hand-solder | 1 | ~$0.02 | Field firmware updates — SWD for the PY32 (**was UPDI 1×3** for the ATtiny) |
| — | **Paired** solder pads — BAT+GND, VOUT+GND, VBACKUP+GND (each interface with its ground adjacent); JP1 (backup charge) + JP2 (5V/3.3V) solder jumpers — **both ship open** | — | $0 | Copper |

**Connector subtotal: ≈ $0.38**

---

## 5. Rollup

| | @ ~100–150 |
|---|---|
| Semiconductors (LCSC-verified) | **$2.07** |
| Power passives + resistors (~est) | $0.45 |
| Connectors/electromech (~est) | $0.38 |
| **Component total** | **≈ $2.90** |

PCB and assembly excluded. For scale: after the RTC reversal the costliest chip is the MCU ($0.93), and the entire timing subsystem (RTC + crystal + diodes + jumper) is ~$0.20 — down from $1.73. The estimated lines are ~28% of the total, all jellybeans — the number is solid to ±$0.30.

## 6. Sourcing risks — the two ⚠ flags

- **U2: SUPERSEDED → PY32F003F18P6 (~22k JLC stock).** The AVR sourcing risk recorded here is exactly why the MCU moved (migration banner): the *whole* tinyAVR/megaAVR-0 line is <~100 assembly units at JLC in every package — an availability wall, not a timing risk. **Original AVR note kept for rollback:** ~~U2 ATTINY1617-MNR: only 62 units in LCSC stock at the verified price. The -MN variant is stocked deeper at $1.63 (+$0.70). Fallback is *not* the ATtiny1616 — it no longer fits (18 signals vs 17 free with `INT` fitted). Check stock at order time; the family is mainstream Microchip and this is a timing risk, not an availability risk.~~
- **U1 BM8563: FITTED = GATEMODE C269877 (SOP-8, $0.108)** — chosen over Belling C194063 on **package**, not price: C194063 is the TSSOP-8 (0.65mm) die and does not fit this board's SOIC-8 (SOP-8, 1.27mm) land, and was OOS at check. C269877 matches the footprint with ~80k JLC stock. Both are gate-verified from their own datasheets (claims row 44, closed 2026-07-15 — electrical tables byte-identical, NXP PCF8563 as the architecture reference). If a SOP-8 Belling BM8563 is later stocked it is a drop-in alternate; the TSSOP-8 C194063 is **not** — the former sole-source risk is retired but watch the package.

## 7. Open at the bench — unchanged, and this BOM adds nothing to the list

Converter efficiency (sets the final ratings-table numbers), standby current, the `CE` battery-detect **decay-delta** test (~500ms; the "millisecond collapse" version was falsified on paper — τ≈6.2s), factory-reset gesture feel, Q1/Q2 handover scope check.

## 8. Design risks — conscious sign-off before ordering (2026-07-19 audit)

None of these block fabrication; they are judgment calls the design makes on purpose. Listed so the yes/no is deliberate, not accidental.

1. **RTC accuracy is the product's soft spot (make this a conscious accept).** BM8563 is **uncompensated**: ~±20 ppm initial + a cold parabola (~22 ppm @ 0°C, ~43 ppm @ −10°C) — worse than Witty Pi's ±2 ppm *compensated*, on the exact axis (wake-on-time, outdoors) this product exists for. Firmware can compensate *wake times* arithmetically (BM8563 has no offset register, so the free-running clock is not trimmable). If drift ever matters, the recorded fix is a **PCF85063A-class trimmable RTC (+$0.43)**. See `powermod-spec.md` §RTC.
2. **No battery reverse-polarity protection — by design.** A reversed JST cell **destroys the TP4056** (no series FET/fuse). Acceptable only if the J3 pigtail polarity is keyed/labelled unambiguously (vendors wire both ways — schematic checklist item 10). Cheap hardening if wanted: a series P-FET or a fuse on VBAT.
   - **⚠️ Escalation identified 2026-07-21 — the worst case on the board, and it is not the single-cell one.** `J3` and `TP2` (`BAT_PAD`) are the **same `VBAT` net**, i.e. two connection points on one node. A user who attaches a cell to each has paralleled two cells with no fuse, balancing or isolation. Two consequences, both worse than risk #2 alone: (a) *correct* polarity but mismatched charge dumps cell-into-cell at **6A+ for minutes** through a 2A connector, bypassing the charger's preconditioning entirely; (b) **one cell reversed is a dead short through both cells** — ~8.4V across a few hundred mΩ, order **40A** — a venting/fire event rather than a destroyed IC. Two connection points also double the odds of a polarity error. **Documented in the user guide (FAQ 5.5, "One cell, one connection point").** This raises the value of the hardening above: a series P-FET or fuse on `VBAT` now mitigates *two* fire paths, not one, and is **the single highest-value change for a rev B**.
3. **No ESD/surge protection on the external connectors.** USB-C VBUS and the STEMMA-QT I²C lines reach silicon directly. For field plug/unplug, a VBUS TVS and an I²C ESD array are cheap production-hardening (optional).
4. **Battery-path FET margin is thin at cell-empty.** Q2 (AON7407, needs ~−2.5V Vgs) sees Vgs ≈ −2.7V at the 3.0V cutoff with VSYS ≈ 2.7V — turns on, but with little margin and rising Rds(on) exactly when it carries load. Bench-verify the Q1↔Q2 handover at the low-voltage cutoff (already on the §7 list — this is the acceptance criterion).
5. **SWD shares the two BAT-LED pins** (SWDIO/SWCLK): field re-flash needs connect-under-reset (NRST on J5), and must not be done with a deeply-discharged cell attached (programmer 3.3V back-feeds through the LDO). Documented; workable.

**Not a risk — recorded so it isn't "fixed" by mistake:** the board is **65×40 mm, not the 65×30 mm Witty Pi outline**. This is **intentional** — the extra 10 mm carries the user-accessible interface (button, LEDs, STEMMA-QT, test/jumper pads) *outside* the Witty Pi footprint, overhanging on top, so it stays reachable when stacked. The Pi Zero 58×23 mm mounting pattern is preserved. Do not "correct" the outline to 65×30.

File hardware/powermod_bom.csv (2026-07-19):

Comment | Designator | Footprint | LCSC Part #
10u | C1,C2,C7 | C_0805_2012Metric | C15850
100n | C10,C11,C12,C13,C14,C15,C16 | C_0402_1005Metric | C1525
22u | C3,C4,C5 | C_0805_2012Metric | C45783
4.7u | C6 | C_0603_1608Metric | C19666
1u | C8,C9 | C_0603_1608Metric | C5673
TJ-S3227 | D1,D2 | LED_TJ-S3227_RG_3.2x2.7mm | C601677
1N4148WS | D3,D4,D5 | D_SOD-323 | C51898295
USB_C_IN | J1 | USB_C_Receptacle_TYPE-C_16P_PowerMerged | C165948
USB_C_OUT | J2 | USB_C_Receptacle_TYPE-C_16P_PowerMerged | C165948
JST_PH_2 | J3 | JST_PH_S2B-PH-K_1x02_P2.00mm_Horizontal
STEMMA_QT | J4 | JST_SH_SM04B-SRSS-TB_1x04-1MP_P1.00mm_Horizontal | C51940130
SWD_HDR | J5 | PinHeader_1x04_P2.54mm_Vertical
1.5uH | L1 | L_Sumida_CDMC6D28_7.25x6.5mm | C5189751
AON7407 | Q1,Q2 | DFN-8-1EP_3x3mm_P0.65mm_EP1.6x2.56mm | C176756
BSS138 | Q3 | SOT-23 | C52895
1.2k | R1 | R_0402_1005Metric | C25862
100k | R10,R12,R13,R14,R28 | R_0402_1005Metric | C25741
47k | R11 | R_0402_1005Metric | C25792
10k | R15,R16,R17,R18,R19 | R_0402_1005Metric | C25744
5.1k | R2,R3 | R_0402_1005Metric | C25905
560 | R20,R21,R22,R23 | R_0402_1005Metric | C137858
180k | R24 | R_0402_1005Metric | C25760
620k | R26 | R_0402_1005Metric | C270590
1k | R27 | R_0402_1005Metric | C11702
56k | R4,R5 | R_0402_1005Metric | C25796
1M | R6,R8,R25 | R_0402_1005Metric | C26083
330k | R7,R9 | R_0402_1005Metric | C25778
BUTTON | SW1 | SW_SPST_PTS647_Sx50 | C2799414
BM8563ESA | U1 | SOIC-8_3.9x4.9mm_P1.27mm | C269877
PY32F003F18P6 | U2 | TSSOP-20_4.4x6.5mm_P0.65mm | C5379864
TPS63020DSJR | U3 | VSON-14-1EP_3x4.45mm_P0.65mm_EP1.6x4.2mm | C15483
TP4056 | U4 | SOIC-8-1EP_3.9x4.9mm_P1.27mm_EP2.29x3mm | C382139
XC6206P332MR | U5 | SOT-23 | C5446
Q13FC13500004 | Y1 | Crystal_SMD_3215-2Pin_3.2x1.5mm | C32346

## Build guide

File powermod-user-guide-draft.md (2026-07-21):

# PowerMOD: Generic Power Scheduler, UPS, and Battery Supply
## User Manual (draft v0.1)

---

## 1. Product Overview

PowerMOD is a generic power controller: real time clock, scheduled power-cycling, and optional UPS/battery backup, controlled entirely over I2C. It's designed to be dropped into any project that needs to power something on a schedule, protect against power interruptions, or both — a Linux single-board computer (SBC), a bare-metal microcontroller project, or anything else with a **3.3V** I2C bus and a power input to control. PowerMOD makes no assumptions about what it's connected to beyond that — and the 3.3V is a real limit, not a preference: **a 5V I2C bus will damage the board** unless you put a level shifter in between (Section 4). Everything modern — Pi, RP2040, ESP32, STM32 — is already 3.3V.

Unlike existing scheduled-power boards, PowerMOD never tries to infer whether whatever it's powering has finished shutting down, or what kind of device it even is. Instead, **the host tells it explicitly** — when it's safe to cut power, and when it should be woken up next. This means PowerMOD works the same way regardless of what's on the other end: Raspberry Pi OS, Alpine Linux, a bare-metal firmware loop, or anything else that speaks 3.3V I2C.

**This guide uses Linux SBCs as the primary worked example throughout** (Section 4 in particular), because that's the use case PowerMOD was first built and validated for, and it's where the richest integration guidance exists. If you're connecting a bare-metal or non-Linux host, see Section 5.3 — the core protocol and hardware work identically; only the specific host-side integration pattern differs.

### 1.1 Built-in Uninterruptible Power Supply (UPS) Functionality — LiPo Mode

PowerMOD integrates battery charging with power-path switching and a buck-boost converter, and can be used as a UPS. It works with any 3.7V-nominal Lithium Ion or Lithium Polymer battery (full-charged voltage 4.2V).

**Two things about "any battery" that you need before you connect one** — both are covered properly later, but they belong here, next to the promise that creates them:
- **⚠️ Meter your battery's polarity first.** The JST-PH connector is keyed, so you cannot plug it in backwards — **but vendors do not agree on which pin is positive**, so a reversed cell seats perfectly and can cause a fire. There is no protection circuitry. This is the direct cost of "any battery": the wider the support, the likelier a cell wired the other way. **FAQ 5.5** explains what to check.
- **⚠️ PowerMOD never checks battery temperature before charging** — see immediately below.

When 5V mains power is connected via the input USB-C connector, it takes priority to power the board and host together, while the battery is charged. **Because the battery is genuinely isolated from the system rail (not powering anything) whenever mains is present, it is safe to disconnect or replace the LiPo while PowerMOD is running on mains power** — host power is not interrupted. This isolation is structural — with 5V present the battery's switch is held off and its internal diode points the wrong way to conduct — not a controller decision, which is what makes it safe to rely on: if you need to swap a degraded cell on a device that's up on mains, you can do it without taking the host down.

**The one exception: an undersized supply.** If your mains supply can't hold its voltage under the host's draw, PowerMOD hands the entire load over to the battery — that's the UPS doing its job, but it means the battery *is* in the power path even though a cable is plugged in, and it stays there until the supply recovers or is replaced. Don't pull the cell while running a heavy load from a weak supply; with a properly rated supply (Section 2), the isolation holds and hot-swapping is safe.

> ### ⚠️ PowerMOD does not check battery temperature before charging
>
> **Charging a lithium cell below 0°C plates lithium onto the anode: permanent capacity loss, and a real safety risk — not just reduced runtime.** Charging much above 45°C is separately damaging. **PowerMOD will charge whenever mains is present and the battery is below full, regardless of how cold or hot the cell is.** It has no way to know.
>
> **This is a deliberate limitation, and it matters most in exactly the deployments PowerMOD is built for** — an outdoor or unheated enclosure will go below freezing, unattended, and PowerMOD will charge straight through it.
>
> Why not: temperature qualification needs a sensor *bonded to the cell*, which normally arrives as a third wire from a battery pack that has one built in. PowerMOD uses a 2-pin battery connector so it can work with any ordinary LiPo — and there's no third wire. A sensor on the board instead would read the board's own heat, not your battery's, and would err toward saying "warm enough" precisely when it isn't. We'd rather tell you the truth than give you a protection feature that quietly doesn't protect.
>
> **If you're deploying somewhere that goes below freezing, this is yours to handle.** Options, roughly in order of reliability:
> - Use a cell rated for **low-temperature charging** (some Li-ion chemistries are; most LiPo pouches are not — check your datasheet, not the listing).
> - Keep the battery in an enclosure that stays above 0°C.
> - Have your host read battery voltage and ambient temperature from its own sensors and simply **not** ask PowerMOD for power (or disconnect mains) while it's too cold to charge safely.
>
> If none of those are practical for your deployment, PowerMOD is not the right board for it, and we'd rather say so here than have you find out via a swollen cell.

**If mains and battery are both present, the host is always prioritized.** When the 5V input can't supply both your host's draw and the full charging current at once, PowerMOD backs the charging off rather than letting the host brown out — and if the input still can't hold up even with charging paused, PowerMOD hands the load to the battery entirely (it never splits it between the two). Either way your host keeps running; the symptom is a battery that charges slowly under heavy load — or, with a genuinely inadequate supply, one that discharges while plugged in (Section 2).

After mains power is disconnected, PowerMOD monitors the battery voltage. **Below a configurable low-voltage threshold, PowerMOD independently cuts power to the host — regardless of whether the host has said it's safe to do so.** This is a hard safety floor, not a request; see Section 4.3.

### 1.1b Mains-Only Mode (No Battery)

PowerMOD does not require a LiPo battery to function. **With no battery connected, PowerMOD operates purely as a scheduled power switch** — mains in, scheduled/commanded power out to the host, with none of the UPS behavior above (no voltage monitoring, no emergency cutoff, no charging, since there's no battery present to protect or charge). This is a fully supported mode, not a degraded fallback — useful if you only want scheduled power-cycling (energy savings, forced reboots) without battery backup. See Section 1.2b for how clock and schedule continuity works in this mode.

There's nothing to configure: the mode follows automatically from whether a battery is physically connected. PowerMOD checks for the cell with a brief active test (momentarily pausing the charger and confirming the battery terminal holds its voltage) rather than just comparing a reading against some threshold. A deeply discharged battery is still recognized as a battery present, not mistaken for an absent one — it holds the test where an empty connector can't — so it charges normally and shows as critically low (Section 1.4) rather than silently disappearing from PowerMOD's view.

**One thing you lose in this mode that isn't obvious from the list above: tolerance of an undersized power supply.** When mains can't hold up, PowerMOD's protection works by handing the entire load over to the battery — and here there isn't one, so an undersized supply browns your host out instead. **The ≥2A supply requirement (Section 2) is a hard requirement in mains-only mode, not a recommendation.** It's worth pausing on, because it's backwards from intuition: *the simpler configuration is the less forgiving one.*

### 1.2 Accurate Realtime Clock and ON/OFF Scheduling

PowerMOD uses a standard crystal realtime clock, accurate to roughly **±20 ppm at room temperature — about a minute a month**. (An earlier draft used a factory-calibrated ±1 ppm part; it was swapped out deliberately — that accuracy cost more than the rest of the power stage combined and, as the modes below show, most hosts never benefit from it.) You can schedule the startup and/or shutdown of your host at any time — or an arbitrary sequence via I2C commands issued from your own scripts or software.

**It is not temperature-compensated, and that matters outdoors.** Like essentially every low-power RTC in this class, accuracy follows the crystal's temperature curve — roughly `−0.035 × (T−25)²` ppm, best at 25°C and falling away either side of it:

| Temperature | Drift (worst case, initial tolerance + temperature) |
|---|---|
| 25°C | ~1 min/month |
| 10°C or 40°C | ~1.3 min/month |
| 0°C | ~2 min/month |
| −10°C | ~2.7 min/month |
| −20°C | ~4 min/month |

**Whether this matters to you depends entirely on which time mode you use:**
- **Relative-time scheduling** (Section 4.1) — **doesn't care at all.** "Wake me 6 hours from now" is computed against PowerMOD's own clock, so a slow clock means a slightly long sleep, not a wrong one. This is the recommended mode for exactly this reason.
- **A host that re-syncs** (NTP, GPS) on each wake — **doesn't care either.** You'll correct the drift faster than it accumulates.
- **Absolute wall-clock schedules on a host that can't re-sync** — this is the case to think about. An unheated outdoor enclosure will drift roughly a minute a month, so a "run at 09:00" schedule wanders. Budget for it, or re-sync from some other source.

If you need genuine temperature compensation, that's a different class of RTC (with a real temperature sensor and correction) and PowerMOD doesn't have one.

**Unlike other boards, scheduling the ON/OFF sequence never requires installing OS-specific software on your host.** You write two values over I2C: the next wake time, and — separately, only once your own shutdown sequence is genuinely complete — a command to cut power now. How you determine "genuinely complete" is entirely up to you and your host's OS.

### 1.2b RTC Backup Power (Optional)

**PowerMOD ships with two solder pads (`VBACKUP`, `GND`) rather than a battery holder — the backup is yours to fit, and most people don't need one.** If you fit one, it **keeps the real time clock counting** through a total loss of both mains and battery power. Nothing else depends on it.

**Why pads instead of a holder:** a CR2032 holder would be the largest component on the board by a wide margin — the cell alone is about **seven times the combined footprint of every chip in PowerMOD**, and 65× the size of the RTC it exists to back up. Spending that on a part most integrators don't need was the wrong trade. Fit what your deployment actually calls for:

| What to fit | Backup | Good for |
|---|---|---|
| **Nothing** | none | Relative-time scheduling, or any host that re-syncs its clock on boot. **This is most people** — see below. |
| **Supercapacitor** | ~1–3 days | Riding out grid outages and battery swaps. No shelf life, nothing to replace, soldered once. **Requires closing one solder jumper** (see below). |
| **Coin cell** (solder-tab or lead-terminated) | years | Non-networked hosts on wall-clock schedules; remote sites that can go dark for weeks. |

> ### ⚠️ Never solder a bare coin cell to these pads
>
> Heating a lithium coin cell can make it vent or rupture. **Use a cell with solder tabs or wire leads already attached** — these are sold specifically for the purpose — or use a supercapacitor, which solders normally. If all you have is a loose CR2032 and a soldering iron, stop: that is the one combination this design cannot let you use.
>
> **Mind the polarity** — the pads are marked, and unlike the battery connector there's no plug to mislead you, so the marking is all you need. Get it right and it's unambiguous; get it wrong and you may damage the RTC.

**If you fit a supercapacitor, close the charge jumper next to the pads** (a solder jumper — one blob, once, while you're already soldering the cap). It ships **open** for a safety reason, not an oversight: the same pads may hold a lithium coin cell, and **charging a primary lithium cell can make it vent or rupture**. PowerMOD cannot see which one you soldered, so the charge path physically doesn't exist until you create it — no software setting can ever charge your coin cell by mistake. Coin-cell users: touch nothing, the open jumper is already correct.

**Your pending schedule and configuration do not depend on the coin cell** — those live in non-volatile memory and survive a total power loss (and a dead coin cell, and a firmware update) on their own. The coin cell has exactly one job: keeping the clock itself running when there's no power at all. That job can't be done any other way, which is why it's there.

**Where this actually matters for you:**
- **If your host syncs time from the network (NTP) on boot,** you will likely never notice the coin cell doing anything — your host just re-syncs after an outage.
- **If your host uses relative-time scheduling** (Section 4.1) and never sets wall-clock time, the coin cell is irrelevant to you by design — what the clock reads doesn't matter in that mode.
- **If your host relies on wall-clock schedules and can't re-sync** (no network, no GPS), the coin cell is what keeps your absolute schedule meaningful across an outage. This is the case it exists for.
- **If you're swapping the LiPo in the field:** on mains, you don't need the coin cell at all — the board stays powered from mains while the battery is isolated (Section 1.1). **With no mains present, pulling the battery cuts all power, and the coin cell is the only thing preserving the clock across the swap.**

**What the coin cell does not do:** it does not power the LEDs, and it does not enable PowerMOD to actually power the host. The clock surviving a total outage means PowerMOD still knows *when* it should wake your host — it does not mean your host will actually wake at that time if no real power source (mains or LiPo) is available when that time arrives. Think of the coin cell as protecting your clock, not as making PowerMOD outage-proof in general.

For what happens to a wake time that came due while the power was out, see Section 4.2.

### 1.3 e-Latching Power Switch

PowerMOD implements a physical power button, similar to the power switch on a PC or laptop. A single tap:
- **Powers on the host, if it is off.** No host cooperation needed — same mechanism as a scheduled wake.
- **If the host is on, immediately begins powering off the host** — after the configurable *forced* delay (Section 4.4), but **without waiting for or requiring any acknowledgment from the host.** This is a deliberate design choice, not an oversight: PowerMOD has no signal line to notify a sleeping or busy host that the button was pressed, so a "graceful request" the host might never see would be misleading. The button is a blunt, immediate manual override — closer to pulling the plug (with a grace delay) than to a polite shutdown request. **If your host needs to protect against this** (e.g., ensure filesystems are always in a safe state), it should poll the **shutdown-pending flag** (Section 4.3) frequently enough to notice that a power-off is in progress and use the remaining delay to attempt a fast save. There is no guarantee it will be running or listening at the moment the button is pressed — that's inherent to the design, not a gap in it.

  **The forced delay defaults to 30 seconds**, chosen so a Linux host that polls the shutdown-pending flag has time to notice and run a *real* shutdown sequence — not just flush a file. Check it against your own host's worst-case shutdown time and raise it if needed (Section 4.4). It's a separate register from the delay used when your host requests its own shutdown, precisely so you can make this one generous without slowing down every ordinary scheduled sleep.

- **Pressing the button again during a button-initiated power-off cancels it.** If you bump the button by accident, press it again before the delay elapses and the host stays up. This only works for shutdowns *the button started* — a second press will not cancel a shutdown your host requested itself (your host has already finished shutting down; keeping it powered would strand it), and it will never cancel a low-battery emergency cutoff (that's a safety floor, and it isn't negotiable).

- **Holding the button for 5 seconds cuts power immediately.** This is the "pull the plug" escape — no delay, no cancelling, and it works even if your host is hung solid. Use it when you want the thing off *now* and don't care what state it's in.

  **Tap and hold divide by intent**, which is worth internalising because it's the whole model:
  - **Tap** = *"start shutting down — I might change my mind."* Delay runs, LED shows it, tap again to abort.
  - **Hold 5s** = *"off, now."* Immediate, irreversible, recorded with its own reason code so you can tell the two apart afterwards.

  A hold simply overtakes a tap: the press starts the delay, and if you keep holding, the cut happens at 5s instead of waiting out the full window. You don't need to think about which you pressed first.

  **Below the low-voltage cutoff, the button does not power the host on.** The protection floor is as absolute for starting as it is for running: booting onto a cell below the floor would trip the cutoff immediately and spend the battery's last margin running out the shutdown delay. Between the cutoff and the recovery threshold, the button *does* work — you're present, and that hysteresis band exists to absorb a boot's voltage sag. If a press seems dead and the Battery LED shows the rare emergency flash (Section 1.4), that's the floor doing its job: supply mains power, or wait for the cell to recover.

  **The hold gesture only exists when your host was ON at the moment you pressed.** From OFF, a press powers the host on, and continued holding does nothing further — it will not boot your host and then cut it five seconds later. (The one other meaning of a long hold is the factory-reset gesture, which requires the button to be already held *while power is first connected* — Section 5.1.)

### 1.4 Status Indicators

PowerMOD has two bicolor LEDs:
- **Battery LED** — four states, using color and blink pattern together:
  - **Solid, color A** — charging (mains present, battery below full).
  - **Solid, color B** — charged/full (mains present, battery at capacity).
  - **Slow blink, color B** — discharging normally (running on battery, no mains present, battery healthy). This is the normal state whenever you're running on battery power with no issues.
  - **Fast blink** — battery critically low: below the **critical voltage threshold** (default 3.3V, configurable — Section 4.4), which sits above the cutoff (default 3.0V). This is an early warning shown *before* PowerMOD force-cuts power — if you see it, you still have time to act. **Once the cutoff actually fires, this LED drops to the rare flash below** — the same LED, telling the next chapter of the same story.
  - **A brief flash every ~10 seconds, color B** — emergency low-battery cutoff has fired (LiPo mode only). Your host is off, and the cell is below its protection floor.

    **Why this state is deliberately faint rather than urgent.** Everything the board draws in this state comes out of a cell that is *already below the voltage PowerMOD cut power to protect*. A fast-blinking LED here would pull several times PowerMOD's entire idle budget and hurry along exactly the over-discharge the cutoff exists to prevent — turning the warning light into part of the problem. A rare flash still tells you the board is alive and holding, at a fraction of the cost. **It is faint on purpose; it is not a fault.**

    Read this LED as the whole battery story on one indicator: **slow blink (fine) → fast blink (act now) → rare flash (host cut, board holding) → dark (fully depleted, board down)**.
  - **Off** — no battery present (mains-only mode, Section 1.1b).
- **Power LED** — four states, using color and blink pattern together:
  - **Solid, color A** — powering host.
  - **Slow blink, color A** — sleeping, with a wake **armed**.
  - **Slow blink, color B** — sleeping, with **no armed wake** — nothing will happen on its own until you intervene. Covers two cases: no wake time was ever set (e.g. after a button-forced-off with no pending schedule — see Section 1.3), **and** a wake time that was already in the past when your host committed it, and was therefore marked expired (Section 4.2).
  - **Off — emergency low-battery cutoff** (LiPo mode only). Your host has no power, and a dark Power LED says exactly that; **the Battery LED carries the emergency signal** (the rare flash above). Dark Power LED + flashing Battery LED = host down, battery below its floor. Everything dark = battery fully depleted.

**"Armed" rather than "scheduled" is a deliberate distinction, and a useful one.** A wake time your host wrote but which was already in the past gets accepted and then expires — so it *was* scheduled, and it will *never* fire. The Power LED shows color B for that case, because what the LED reports is "will anything happen on its own?", not "did anyone ask for something?" **This makes the LED a free bring-up diagnostic:** if you set a wake, your host sleeps, and the LED shows color B rather than color A, your timestamp was bad — a timezone or overflow bug — and you've caught it without attaching anything. Read `WAKE_STATUS` (Section 4.2) to distinguish "never set" from "expired."

For finer detail than the LED shows (e.g. distinguishing a scheduled shutdown from a button press, both of which show as "sleeping"), read the reason-code registers over I2C (Section 4.3).

If a battery is deeply discharged with no charging source, PowerMOD itself may eventually be unable to power any LED at all. **Extended, total absence of any LED activity should be read as "battery likely fully depleted," not as a normal sleep state** — this applies to LiPo mode only, since the coin cell (Section 1.2b) keeps the clock running but was never intended to power an LED either way.

### 1.5 Interface Introduction

1. USB-C connector for 5V mains power input.
2. USB-C connector for 5V power output to host.
3. I2C connector (4-pin, STEMMA-QT-style) for command/telemetry interface to host. **3.3V logic — see the warning in Section 4.**
4. On/off switch (physical button).
5. Power LED (bicolor status — Section 1.4).
6. Battery LED (bicolor charge status — Section 1.4).
7. PH2.0 2-pin battery connector — **rated 2A, and that rating lives in the plug's contacts, not the board** (Section 2). ⚠️ **Polarity is not standardized across battery vendors — meter it first** (FAQ 5.5).
8. Two solder pads (`VBACKUP`, `GND`) for an **optional** RTC backup — Section 1.2b. No holder is fitted; you choose whether to add a backup at all. The adjacent **charge jumper** ships open (Section 1.2b).
9. **`BAT` / `GND` solder pads — the high-current battery connection.** Soldering the cell here bypasses the connector's 2A contact limit and raises the 5V-from-battery ceiling from ~1.5A to ~2.6A (Section 2). Use these for any sustained load above ~1.5A, or when building more than a handful of units (a pad can't be reverse-seated — FAQ 5.5).
10. Unpopulated header exposing raw VOUT + GND — same power rail as the USB-C output, for hosts without a USB-C power input.
11. Voltage select jumper/solder-bridge — sets output voltage (both the USB-C output and the raw VOUT header) to 5V or 3.3V. Ships default at 5V. **Clearly check the jumper's current position before connecting a host** — PowerMOD does not detect or protect against a mismatched setting; connecting a 3.3V-only host while the jumper is set to 5V (or vice versa) can damage your host.

---

## 2. Specification / Technical Details

| | |
|---|---|
| Microcontroller | **PY32F003F18P6** (ARM Cortex-M0+, 48 MHz, TSSOP-20) — *migrated from the ATtiny1617 for assembly availability (instock-parts branch, 2026-07-18)* |
| Realtime Clock | BM8563-class (PCF8563-compatible) + 32.768 kHz crystal. ~±20 ppm; **not** temperature-compensated — see Section 1.2 for drift vs. temperature |
| DC/DC Converter | TPS63020 buck-boost, selectable 3.3V or 5V output (jumper/solder-bridge, default 5V) |
| Charging Manager | **TP4056 charger behind a PFET power-OR** — up to 1A charge current. **No battery temperature qualification** — see Section 1.1 |
| Power In | DC 5V via USB-C (non-PD) — **use a supply rated at least 2A**, see below — or 3.7V Li-ion/LiPo battery |
| Power Out | **Depends on source and battery connector — there is no single number.** ~2.7A on mains; ~1.0–1.5A on battery via the JST-PH connector; ~1.8–2.6A on battery via the solder pads. **3.3V mode is ~2A in every case.** See below |
| Standby Current | TBD — measure and document once hardware exists |
| I2C | **3.3V logic only** — no pull-ups fitted; host defines the bus. 5V hosts need a level shifter (Section 4) |
| I2C Address | 0x08 default, configurable |
| RTC Backup | **Optional** — two solder pads for a coin cell or supercap. No holder fitted (Section 1.2b) |
| Operating Environment | **−40°C to +85°C** electronics. Fitting a coin cell narrows this to **−30°C to +60°C** (the cell is then the limit); a supercap or no backup keeps the full range. Your LiPo narrows it further — see below |

**On the mains supply: use a 5V USB-C charger rated at least 2A — 3A if you want full output.** PowerMOD will draw up to the full 3A a USB-C supply can offer when it's powering your host *and* charging the battery at the same time, and — like essentially every board in this class — **it does not ask your charger's permission first.** It draws what it needs.

**With a battery fitted, plugging in something weaker fails gently — but be clear about how.** PowerMOD never blends the two sources; at any moment your host runs entirely from one or the other. A weak supply plays out in two stages:

- **Mildly undersized:** the input still carries everything. PowerMOD backs *charging* off to relieve it, and your host doesn't notice because PowerMOD's output is regulated — a sagging input still produces clean 5V (or 3.3V) out. **The battery is not helping here; it just isn't charging.** Symptom: a battery that charges slowly or never reaches 100% — so if you're wondering why it never gets there, an undersized charger is the first thing to check.
- **Severely undersized:** the input can't hold its voltage at all, and PowerMOD hands the whole load to the battery. Your host stays up, but now **the battery is discharging while a charger is plugged in**, and the board runs warmer than usual. Symptom: battery percentage *falling* with the cable connected — and your host can confirm it directly by reading the input-voltage register (Section 4.3) and watching it sag. That's not a PowerMOD fault to work around — replace the supply.

**Either way your host keeps running.** But "plugged in" does not automatically mean "not using the battery" — with a bad enough supply, you're on battery and losing ground.

> **⚠️ In mains-only mode (no battery), an undersized supply is not gentle — it browns out your host.** The protection above works by handing the load to the battery, and there isn't one. This is worth pausing on, because it's the opposite of what you'd expect: **the simpler configuration is the less forgiving one.** If you're running PowerMOD without a battery, the ≥2A supply isn't a recommendation, it's a requirement.

**On the two USB-C ports: they look identical, because they are.** One is input, one is output, and the silkscreen is what tells them apart.
- **Plugging your host into the input port does nothing** — two sinks, no power source, no harm.
- **Plugging a modern USB-C charger into the output port also does nothing.** USB-C chargers only switch their power on once they detect a device asking for it, and PowerMOD's output port isn't asking. It simply won't turn on.
- **The exception worth knowing: an old USB-A charger with an A-to-C cable.** A USB-A port has 5V live on it always — there's no handshake to save you. Plugged into the output port, it backfeeds 5V into PowerMOD. **In the default 5V configuration that's harmless** (5V meeting 5V). **If you've set the jumper to 3.3V, it is not** — you'd be putting 5V onto a rail your host expects to be 3.3V. **Check the label before plugging anything in, and check it twice if you're running at 3.3V.**

**On operating temperature:** PowerMOD's electronics are rated **−40°C to +85°C**, but the board is only as wide as its narrowest part, and that is never the silicon:
- **If you fit a coin cell, it becomes the board's limit (−30°C to +60°C).** Note the **+60°C ceiling** in particular — an outdoor enclosure in direct sun exceeds that more easily than people expect, and it's the *cell* that objects, not the circuitry. If you're mounting somewhere that bakes, think about shade, venting, or fitting a supercap instead (typically rated to the electronics' own range). **Fitting no backup at all leaves you with the full −40°C to +85°C.**
- **Your LiPo narrows it further**, and by more than you might assume: typical cells discharge down to about −20°C but are only safe to **charge between roughly 0°C and 45°C**. PowerMOD does not enforce that (see the warning in Section 1.1) — check your own cell's datasheet.
- **Running without a coin cell or without a battery widens the range back out** toward the electronics' own −40°C to +85°C. Mains-only mode with no coin cell is the most temperature-tolerant way to run PowerMOD.

> ### ⚠️ Feed the input 5V only — there is no overvoltage protection
>
> The USB-C input expects a **nominal 5V supply and nothing else.** PowerMOD does no PD negotiation (it requests 5V and takes what it's given), and there is **no TVS, clamp or overvoltage protection on the input.** The converter's recommended input maximum is **5.5V**, which a fully-compliant USB-C source is already allowed to deliver — so the margin at the top is **zero by design**, and its absolute maximum is 7V.
>
> **Anything that puts more than ~5.5V on the input destroys the converter and probably the charger with it.** In practice that means: do not use a **USB-C PD trigger board** set to 9V/12V/15V/20V, do not feed the input from a higher-voltage adapter, and do not connect a bench supply set above 5V to the VBUS pads. A normal 5V USB charger, phone charger, or PD source (which will negotiate down to 5V on its own) is fine.

**On the output current figures:** an earlier draft advertised a single "3A," which was never achievable — a non-PD USB-C input tops out at 15W total (covering the host *and* charging), and 3A at 5V draws more than double the battery connector's rating on the battery side. The honest answer isn't one smaller number, it's a table:

**There is no single output-current number, and any product that gives you one is hiding something.** What PowerMOD can deliver depends on where the power is coming from and how the battery is wired:

| Running on | 5V out | 3.3V out | What's actually limiting it |
|---|---|---|---|
| **Mains (USB-C)** | **~2.7A** | **~2.0A** | Your USB-C supply's 3A ceiling |
| **Battery, JST-PH connector** | **~1.0–1.5A** | **~1.6–2.0A** | The connector — rated 2A, and that's the wall |
| **Battery, soldered to the pads** | **~1.8–2.6A** | **~2.0A** | The converter's own switch limit |

**Read the worst row, not the best one.** On battery through the JST connector — the way most people will run this — 5V output is **~1.0A once the cell is near empty**. That is the honest floor, and it is the configuration a UPS is *for*.

**Output falls as the battery drains.** A fixed current limit delivers less power at a lower cell voltage; this is physics, not a defect. The ranges above run empty-cell → full-cell.

**Three things worth knowing:**
- **The connector costs you nearly half.** Same board, same chips: ~1.0–1.5A through the JST-PH versus ~1.8–2.6A soldered to the pads. If you need the current, solder to the pads. **Why the difference, since both land on the same copper:** the 2A is the rating of the connector's *contact interface* — a spring terminal pressing on a pin, with real contact resistance and a thermal limit — not of the board's traces. A solder joint is metallurgical, effectively milliohms. Using the connector puts a 2A-rated element in series with the cell; soldering removes it, and the next limit up (the converter's own switch rating) becomes the ceiling. (And no, board layout can't route around it — the connector's pins and the solder pads are already the same copper. The limiting junction is inside the *plug*, between your battery's crimp terminal and the pin, so it travels with the battery lead, not the board.) Sustained current past 2A doesn't melt the plug on the spot — it overheats and slowly degrades the spring contact until resistance, heat, and failure feed each other.
- **3.3V mode never exceeds ~2A**, whatever you do — the converter caps it there. **Solder pads gain you nothing in 3.3V mode.**
- **Charging is a tax.** On mains, ~2.7A drops to **~1.8A while the battery is charging at full rate**, because your host and the charger share one USB supply. Your host always wins that contest; charging absorbs the shortfall.

That covers typical Linux SBC draw and essentially any MCU host. **The final number still depends on real converter efficiency and will be confirmed on hardware, not estimated.** If your host needs sustained high current, wait for it before designing PowerMOD in.

---

## 3. How Does PowerMOD Work?

After you tap the power button, PowerMOD powers your host via the output USB-C connector, and your host boots.

**When power is connected or restored, PowerMOD's default behavior is to restore whatever the host's power state was when power was lost** — if your host was running, it boots again; if it was already asleep, it stays asleep. A brand-new board with no history boots the host on first power-up, so installation works as you'd expect. This is configurable to two fixed alternatives (always boot, or never boot without an explicit button press or schedule) — see Section 4.4.

Why this default: it means an ordinary power blip doesn't wake a host that deliberately went to sleep until morning, while a host that was genuinely running when power died still comes back on its own. **A scheduled wake still fires regardless of this setting** — including one that came due while power was out (Section 1.2b), so unattended recovery doesn't depend on this mode at all.

Your host's own software is responsible for:
1. Reading the current time from PowerMOD's RTC on boot (useful regardless of which time mode you use — see Section 4.1).
2. At some point before it needs to sleep, writing a "wake at time T" command over I2C.
3. Doing whatever it needs to do before it's safe to lose power — for a Linux host, this means running its OS shutdown sequence (unmounting filesystems, stopping services); for a bare-metal project, this might just mean finishing the current task or flushing a write. See Section 5.3 for the difference in practice.
4. Once that's genuinely complete, issuing a "cut power now" command over I2C.

PowerMOD does not need to know how your host determines step 4 is complete — whether via an OS shutdown-sequence hook, a single line at the end of a firmware loop, or manual intervention. It simply waits for the command.

PowerMOD has an RTC and always knows the time. When the scheduled wake alarm is reached, PowerMOD powers the host — equivalent to a button tap. **If the wake alarm is reached while the host is already on** (a previous shutdown didn't finish, the host rebooted on its own, or the wake alarm's time arrives during the delay-before-cut window after "cut now" was already issued), **PowerMOD does nothing — the alarm is simply a no-op.** The host is considered "on" until power is actually cut, so an in-progress shutdown always takes precedence. It is not cached or fired later once the host eventually powers off. This is deliberate: a wake alarm exists to wake a sleeping host, and there's nothing meaningful to do if the host isn't sleeping. Your host will write a fresh wake time the next time it actually goes to sleep, so nothing is lost by PowerMOD not trying to "remember" a stale alarm.

PowerMOD also measures battery voltage. If it drops below the configured low-voltage threshold, PowerMOD begins the same power-off sequence used for a button press — after the configurable *forced* delay, it removes power — regardless of whether the host is aware or has acknowledged anything. PowerMOD does not notify the host beforehand (there is no signal line to the host at all — Section 1.3), and the cutoff cannot be cancelled by anything. A host that polls the shutdown-pending flag (Section 4.3) can notice it happening and use the remaining delay to flush state, which is the only reason the delay is there. See Section 4.3.

---

## 4. Software / Protocol Usage

PowerMOD is controlled entirely via I2C register reads and writes. There is no required host-side software package, service, or daemon — you integrate the commands below into your own host's boot and shutdown sequence directly.

> ### ⚠️ PowerMOD is a 3.3V I2C device. A 5V bus will damage it.
>
> **This is not "unsupported" — it's destructive.** PowerMOD's logic runs at 3.3V, and its I2C pins have an absolute maximum of about 3.8V. Wiring them to a 5V I2C bus (a classic Arduino Uno, or anything else with 5V pull-ups) **damages the board**, possibly not immediately and possibly not obviously.
>
> **If your host's I2C is 5V, you need a bidirectional level shifter between it and PowerMOD.** There is no version of this where it's fine to "just try it."
>
> **Most hosts are already 3.3V and need nothing:** Raspberry Pi and other Linux SBCs, RP2040, ESP32, STM32, and anything in the STEMMA-QT/Qwiic ecosystem — which is what this connector is.
>
> **PowerMOD fits no pull-up resistors of its own**, deliberately. Your host's pull-ups define the bus voltage, and PowerMOD only ever pulls the lines low — it never drives them high, so it can't impose a voltage on your bus. That's why the 3.3V figure is *your* responsibility to respect: PowerMOD has no way to enforce it, and no way to protect itself if you don't.

**For exact register addresses, encodings and enum values, see `powermod-register-map.md`** (protocol version 1). This section describes what the registers are *for*; that document is the wire-level reference you'll code against. Two things from it are worth knowing before you write any code:
- **All multi-byte values are little-endian.**
- **Read each multi-byte value in one transaction, starting at its first byte.** Doing so latches a coherent snapshot — reading the middle of a field on its own can return a torn value (this matters most for the clock, which is always counting).

### 4.1 Time

PowerMOD's RTC can be used two different ways, and you can pick either depending on what your host needs — PowerMOD doesn't require or assume one over the other.

- **If your host has accurate time (NTP, chronyd, GPS, etc.) and cares about wall-clock accuracy:** write it to PowerMOD's RTC whenever convenient — not just once at initial setup, but any time you want to (re)sync, as often as you like. This is useful if you want PowerMOD to also serve as a time source your host can read on boot (see below), or if your application logic depends on absolute scheduled times rather than relative ones.
- **If your host doesn't care about wall-clock time at all:** you never need to write real time to PowerMOD. Its RTC can sit at the default epoch value (or wherever it happens to be) indefinitely — this is fine, because the recommended scheduling pattern (Section 4.2) only ever reads PowerMOD's *current* value and adds an offset to it. What PowerMOD's clock actually reads relative to true wall time is irrelevant in this mode; only its internal consistency (it keeps ticking forward correctly between reads) matters.
- **Read RTC time.** Recommended on every boot regardless of which mode you use, so your host can set its own system clock even without network access — useful in wall-clock mode for obvious reasons, and still harmless (just not meaningful) in relative-time-only mode.
- **Read RTC validity flag.** If your board's coin cell has ever been fully depleted (alongside no mains and no LiPo), the RTC resets to the epoch — the same as first power-up. This register tells you whether that's happened since you last set the time, so you can tell "trustworthy time" apart from "reset since I last synced" — particularly useful if you're using wall-clock mode and need to know whether to re-sync before trusting an absolute schedule. **Note your pending schedule and configuration are not lost in this scenario** (they don't depend on the coin cell — Section 1.2b); only the clock resets. But a wake time is only as meaningful as the clock it's measured against, so if this flag is set, treat any pending absolute schedule with the same suspicion as the time itself.

### 4.2 Scheduling

- **Write next wake time.** A timestamp — absolute or computed relative to PowerMOD's current RTC value, your choice (see below). PowerMOD will power the host at this time (see Section 3 for behavior if the host is already on when this time arrives). Writing a new wake time always replaces any previously stored one — there's no queue, just one wake time at a time. To cancel a pending wake without immediately scheduling a new one, use the separate **clear wake time** command.
- **Wake-time writes are atomic.** The write uses a staging-then-commit pattern internally, so a power loss mid-write leaves your previously-committed wake time intact rather than corrupted — you don't need to guard against this yourself.
- **Read back the stored wake time.** You can read the currently committed wake time and whether it's armed. Useful after an unexpected reboot: if your host crashed somewhere between writing a wake time and issuing "cut power now," this tells you whether the write actually landed, so you can decide whether to write a fresh one.
- **Write "cut power now."** Only issue this once your host's own shutdown sequence is genuinely complete. PowerMOD cuts power promptly — the host-requested delay **defaults to 0** (Section 4.4), because by this point your host has already declared itself finished and a halted host is still drawing current while you wait. This delay is separate from the longer *forced* delay used for button presses and low-battery cutoffs (Section 4.4) — there's no reason to make your host wait around once it's genuinely done, so keep this one short.

**Absolute vs. relative wake times — both are legitimate, pick whichever fits your use case.** If you're confident in both PowerMOD's RTC accuracy and your host's own clock (e.g., you're syncing real time via NTP/chronyd as described in Section 4.1), writing absolute wake times is completely fine — and necessary for schedules that only make sense in wall-clock terms, like "run at :15 past every hour" (a cron-style pattern). PowerMOD does not care which approach you use.

**Where relative scheduling helps specifically:** if you're in the relative-time-only mode from Section 4.1 (never syncing wall-clock time to PowerMOD at all), or if you simply want to eliminate the risk of clock-drift/timezone bugs producing a bad absolute timestamp, compute the wake time as "PowerMOD's current RTC value + desired offset" instead of an independently-calculated absolute time. This is a recommendation for that specific failure mode, not a requirement — if your clocks are trustworthy and your schedule is inherently wall-clock-based, use absolute times.

**PowerMOD accepts any well-formed timestamp without rejecting it** — there is no "is this plausible" check on the write itself, regardless of which approach you use. A miscalculated absolute timestamp (host clock drift, timezone bug) is treated as a host-side integration error, not something PowerMOD attempts to detect or correct.

**What decides whether a wake time ever fires is how it looked at the moment you committed it:**

- **Already in the past when you committed it** → it's marked expired immediately and **never fires.** Your host stays asleep rather than rebooting instantly. This is deliberate: an immediate reboot the moment a bad timestamp is written would look exactly like a boot loop, and it wouldn't fix the underlying miscalculation — only make its symptom more disruptive. The optional maximum-sleep safety net (Section 4.4) is the backstop against staying asleep indefinitely.
- **In the future when you committed it, but it came due while PowerMOD had no power to act** → it's a genuinely missed alarm, and it **fires as soon as usable power returns** rather than being discarded or waiting for the next scheduled time. Example: you schedule a wake for 2 PM; mains and battery are both unavailable from 1 PM to 4 PM; your host wakes as soon as power returns at 4 PM.
- **In the future when you committed it, but it comes due while the battery is below the recovery threshold with no mains present** → same treatment: **held, and fired the moment power is usable** (voltage back above recovery, or mains arrives). Booting your host onto a cell below PowerMOD's own protection floor would sag it straight back into the cutoff — consuming the wake and stranding the device. "As soon as it physically can" means *usable* power, not merely present power. Reported as a missed wake.

The distinction is "was this reachable when you asked for it," which PowerMOD can only know at the moment of the write — which is why it's evaluated then rather than later. In practice this means you don't need to think about it: ask for a time that's actually in the future and it will happen as soon as it physically can; ask for one that's already gone and nothing happens.

**This is not validation, and PowerMOD still won't reject anything.** It accepts whatever you write. Committing only decides what the accepted value *means*.

**Safety net for a schedule that's never set at all:** by default, if no valid wake time has ever been written, PowerMOD sleeps indefinitely once powered off — there is no implicit fallback. This matters if, for example, your host issues "cut power now" without having successfully written a wake time first (a failed write, or a logic bug) — with no wake time and no one present to press the button, the device would otherwise be stranded off indefinitely. **An optional, disabled-by-default safety register** lets you configure a maximum sleep duration (e.g. 24 hours); if enabled, PowerMOD will wake unconditionally after that duration even with no schedule set, giving your host another chance to establish one. Recommended for genuinely unattended/remote deployments; left disabled by default so it never activates unexpectedly for integrators who haven't opted in.

### 4.3 Battery and Power Status

- **Read battery voltage.** Raw voltage only — no state-of-charge/fuel-gauge estimation. Standard 3.7V-nominal LiPo assumptions apply (full ≈4.2V, cutoff ≈3.0–3.3V).
- **Read input (mains) voltage.** The raw voltage on the USB-C input, in millivolts; reads 0 with nothing plugged in. **Its best use is diagnosing an undersized supply** (Section 2): if this sags under your host's load while the battery percentage falls, your charger is the problem — you can now see the two-stage weak-supply story in numbers instead of inferring it from symptoms.
- **Read board temperature.** The temperature of PowerMOD's own board, in °C, from the MCU's on-chip temperature sensor. **Treat it as a coarse trend, not a precise reading:** the PY32F003 sensor carries no factory calibration constant, so an out-of-the-box reading is only good to roughly **±10 °C** unless the firmware applies a one-point calibration (measure once at a known temperature and store the offset). Two honest uses, both of which tolerate that coarseness: estimating RTC drift against the Section 1.2 table, and telling whether an outdoor enclosure is *anywhere near* the freezing-charge hazard. **⚠️ It is the *board's* temperature, not your battery's** — a cell in free air or against a cold wall can be much colder than the board, so treat it as a rough enclosure proxy, not as permission to charge (the Section 1.1 warning stands in full).
- **Output voltage and output current are not available.** Nothing in PowerMOD's own operation measures them, and adding sensing purely so you could read a number conflicts with keeping the board simple and cheap. (Witty Pi exposes input/output voltage and output current; PowerMOD now exposes input voltage and board temperature, and holds the line on output sensing.) Practical consequences:
  - **To know whether mains is present, read the mains-vs-battery flag above** — it answers the question that actually matters ("is the input there?") rather than handing you a voltage to interpret.
  - **To confirm your output voltage jumper setting** (Section 1.5), check it visually. There's no register for it.
- **Read status flags.** A single byte of bit flags answering most "what's going on right now" questions in one read — the cheapest thing to poll if you only poll one thing:
  - **Mains vs. battery.** Use this to prioritize your own shutdown urgency: low stakes if on mains, real urgency if on battery (a hung shutdown on battery risks the emergency cutoff below).
  - **Battery present.** Tells you whether you're in LiPo mode or mains-only mode (Section 1.1b).
  - **Charging.** Whether the battery is currently being charged. Note this reports what the charger is *doing*, not whether it's *safe* — PowerMOD does not check battery temperature and will charge a frozen cell (Section 1.1).
  - **Charge complete.** The battery is full and the charger has terminated. Read the pair together: charging=1 → charging; complete=1 → full; **both 0 → not charging for some other reason** (on battery, or charging paused for a weak supply — check the input-voltage register).
  - **Shutdown pending** — see below.
  - **RTC valid** — see Section 4.1.
  - **Wake armed** — a committed, future wake time exists (Section 4.2).
  - **Configuration defaulted.** **Worth checking on every boot.** If PowerMOD's stored configuration ever fails its integrity check at startup, it falls back to factory defaults rather than running on corrupt values — which is the safe behavior, but it means **your settings silently reverted.** A voltage threshold you deliberately raised is back at its default and nothing else will tell you. If you see this flag set, re-apply your configuration.
- **Low-voltage emergency cutoff (not a command — automatic, board-enforced):** if battery voltage drops below the configured low-voltage threshold, PowerMOD will cut power independently, whether or not the host has issued "cut now." This exists specifically to protect against a hung or crashed host that never completes its own shutdown sequence.
- **Recovery:** after an emergency cutoff, PowerMOD does not restore power the moment voltage creeps back above the cutoff threshold. It waits until voltage recovers to a separate, higher **recovery threshold**, or until mains power is supplied (whichever comes first). This avoids a rapid cut/recover/cut oscillation as boot-current draw could otherwise re-sag a barely-recovered battery back below the cutoff point.

  **What actually happens when recovery is reached — stated precisely, because three parts of this manual used to imply three different things:** an emergency cutoff records your host as having been **ON** (it was cut involuntarily — it never chose to sleep). When the recovery condition is met, PowerMOD treats it as power becoming available again and applies your **power-on mode** (Section 4.4): the default **Restore-previous-state** boots the host (its recorded state is ON), **Always ON** boots it, and **Always OFF** leaves it down until a button press or scheduled wake. The reason code reported is *power restored* — whether it was mains arriving or the battery climbing past the recovery threshold; both mean the same thing here: power is usable again.
- **Read shutdown-pending status.** Tells you a power-off is currently in progress and the delay timer is running, along with what triggered it. **This is the register to poll if you want any chance of reacting to a button press or a low-battery cutoff** — both happen without warning and without your host's consent, and this flag plus the forced delay (Section 4.4) is the entire window you get. Nothing requires you to poll it; PowerMOD will proceed either way.
- **Read time remaining before power is cut.** Valid while a shutdown is pending — tells you how long you actually have left, in tenths of a second. **This is what makes the pending flag actionable rather than merely alarming:** knowing a cut is coming doesn't help unless you know whether there's time to unmount cleanly or only time to flush. Don't compute this from your configured delay — you have no idea when the timer started, only PowerMOD does.
- **Read last-power-off reason and last-power-on reason.** These are **two separate registers**, and both are worth reading on boot:
  - **Last power-off reason** — why PowerMOD cut power the last time — one of exactly five: host-requested cut, button tap, **button-forced-off (distinct from a graceful shutdown — see Section 1.3)**, low-voltage emergency cutoff, or watchdog expiry. Note there is no "scheduled shutdown" reason and that's not an omission: PowerMOD schedules *wakes*, never shutdowns — when your host shuts down on its own schedule, it does so by issuing "cut power now," so it reports as a host-requested cut. This is the one that tells you whether your last shutdown was normal or whether your battery is failing.
  - **Last power-on reason** — why PowerMOD powered your host up: scheduled wake, missed wake fired on power restore, button press, power restored, max-sleep safety timeout, watchdog expiry. If more than one wake condition becomes true at effectively the same moment (e.g. a safety timeout and a scheduled wake coinciding), PowerMOD still performs a single wake, and the reported reason follows a fixed, deterministic priority order rather than being ambiguous.
  - A simple flag is also available: was the previous shutdown due to low battery? Convenient if that's all your host's logic needs.

  **These are two registers rather than one for a reason that matters to you:** booting is itself an event. If a single register held both, the wake reason would overwrite the power-off reason during the very act of powering your host up — so by the time your host could read it, "why did I lose power last time" would always have been replaced by "because you just woke up." Kept separate, the power-off reason survives your boot and is still there to read.
- **Read event log.** PowerMOD keeps the last 8 power transitions (each a reason code + timestamp, same format as the most-recent-reason registers above) in non-volatile storage, so it survives power loss and firmware updates. Useful for understanding what happened over multiple cycles on a remote device you can't check on in person — e.g., seeing a pattern of repeated low-voltage cutoffs might indicate a failing battery or charging problem before it becomes a hard failure. The log is a circular buffer (oldest entries are overwritten as new ones are added) rather than an unlimited history.

  **⚠️ One ambiguity to know about when reading that pattern: PowerMOD does not measure output current.** It senses battery and input *voltage* only, so it cannot distinguish "the battery is weak" from "the host drew more than the supply could deliver and dragged the rail down." Both appear in the log as low-voltage cutoffs. Before concluding a cell is failing on a remote device, consider whether the host has a periodic heavy load or the supply is undersized (FAQ 5.10) — a healthy battery under an overloaded supply logs exactly like a dying one.
  - **If you use relative-time scheduling** (Section 4.1) and never set wall-clock time, the log's timestamps are offsets from an arbitrary epoch and restart from zero after any RTC reset — so read them for *ordering and intervals* ("three cutoffs within an hour of each other"), which is most of what the log is for, rather than as wall-clock history.

### 4.4 Configuration

**Configuration writes don't take effect until you commit them.** Writing any register in this section stages the value; it changes nothing until you write the commit command. This is deliberate — it's what makes a power loss partway through reconfiguring you harmless, and it's what lets several related values (like the two voltage thresholds) be validated and applied as one atomic set rather than passing through an invalid intermediate state.

The sequence is:

1. **Write** the config registers you want to change. Nothing has happened yet.
2. **Read them back if you want** — reads return your *staged* values, so you can confirm exactly what you're about to apply. Three safety nets behind this: staged values you never commit are **discarded when your host powers off**, so a fresh boot always reads the running configuration; the commit-status register **reports when uncommitted staged changes exist** (worth checking on boot if your software may have crashed mid-configuration); and a **discard command** throws staged changes away without committing them.
3. **Write the commit command.** PowerMOD validates the whole staged set, writes it, reads it back to verify, and stores a checksum.
4. **Check the commit status register.** It reports success, or why it refused — most usefully, that a staged value was out of range or that the threshold pair was inverted (below). **A rejected commit changes nothing at all**; it never applies partially.

If you skip step 3, nothing you wrote will survive — or take effect at all. See `powermod-register-map.md` for the exact addresses and command values.

- **State when power connected.** Three modes:
  - **Restore previous state (default)** — powers on only if the host was actively powered at the moment mains/battery power was lost; stays off if it had already been powered off, whether via a schedule or a button press. (An emergency cutoff counts as ON — your host didn't choose to go down — so recovery re-boots it; Section 4.3.) A board with no history (first ever power-up) boots. Note this refers to PowerMOD's own power output, not any host-side sleep/suspend concept — PowerMOD has no visibility into what your host's OS is doing internally.
  - **Always ON** — boots automatically whenever mains or battery power is first available, no button press needed.
  - **Always OFF** — requires an explicit button press or scheduled wake, matching the behavior of other boards in this category.

  **Which to choose.** The default suits most deployments and is the safest starting point. Reach for **Always ON** if your host has no schedule at all and you simply want it running whenever there's power — but be aware that on a scheduled, battery-backed deployment it means a brief power interruption at 2 AM will boot a host you intended to sleep until 6 AM, and unless your host's software checks whether it *should* be awake, it will happily stay up and drain the battery. Reach for **Always OFF** on a bench or hobby setup where you want nothing to happen without you. **A scheduled wake fires in all three modes**, so none of this affects whether your device recovers on schedule — only what happens on an unscheduled power event.
- **I2C address.** Default 0x08, configurable by writing the address register **and committing** — but note this requires updating your own host-side code to match, and does not take effect until PowerMOD is fully power-cycled. (So the address doesn't change under you mid-session: you commit, then it applies at the next power-up, by which time your code should already expect the new one.)
- **Low-voltage threshold** (default 3.0V, **enabled**) **and recovery threshold** (default 3.6V). Independently configurable, and either can be disabled (Section 4.3).

  **Unlike some boards in this category, the low-voltage cutoff is on by default.** It's a safety floor protecting your battery from over-discharge, and a floor that ships disabled protects nobody who didn't already know to switch it on. You can disable it if you have your own protection circuitry, but that's a deliberate choice rather than the starting state. Neither threshold does anything when no battery is connected — there's nothing to protect.

- **Critical voltage threshold** (default 3.3V). Below this, the Battery LED shows its critical-warning pattern (Section 1.4) — an early warning while you can still do something, since it sits above the 3.0V cutoff. Set to 0 to disable the warning entirely. **This only drives the LED; it never cuts power** — that's the cutoff's job.

  **The three thresholds describe one journey down a discharging cell**, and PowerMOD enforces their order: **3.3V critical (warn) → 3.0V cutoff (host off) → 3.6V recovery (host back)**. A commit that puts them out of order is rejected — a warning below the cutoff would fire at the same instant the host dies, and a critical threshold above recovery would alarm about the recovery that just succeeded.

  **Recovery must be higher than cutoff, and PowerMOD enforces it**: a commit that would set recovery at or below cutoff is rejected outright, because that reintroduces exactly the cut/recover/cut oscillation the two-threshold design exists to prevent. Leave yourself real margin — 0.1V passes the check but boot current can sag the rail further than that, so you'd oscillate anyway. **Aim for at least 0.3V; the defaults give you 0.6V.**

  **If you're raising both thresholds, stage both and commit once.** Validation runs against the whole staged set, so committing a higher cutoff first — while the old, now-lower recovery value is still in place — gets rejected even though your intended end state is fine.

  **Setting recovery to 0 (disabled) is a legitimate choice, not a broken one:** after an emergency cutoff your host then stays off until *mains* is supplied, rather than rebooting on battery recovery alone. Useful if you'd rather a device not resume on a marginal cell without someone physically present.
- **Delay before power cut — two separate registers.**
  - **Host-requested delay** (**default 0**) — the pause after your host issues "cut power now." **Defaults to zero deliberately.** Your host only sends that command once it has *already finished*, so there is nothing to wait for — and waiting is not free. A halted Raspberry Pi doesn't power itself off; it sits there drawing roughly 220–300mA depending on the model (measured across Pi 3/4/5 — halt deliberately leaves the SoC powered). On a 15-minute schedule, a 7-second delay would burn about **2% of a 2000mAh battery every day** doing nothing at all. Raise this only if your host has a specific reason to need a settle window.
  - **Forced delay** (default 30 seconds) — the pause after a button press, a low-battery cutoff, or a watchdog expiry, where your host has *not* declared anything and may be mid-work. **This is the only warning window your host gets, so size it to your host.** The 30s default assumes you might want to poll the shutdown-pending flag, notice, and run a real shutdown in the time available — measure your host and raise it if that's tight. It's a separate register precisely so you can make it generous without paying that cost on every ordinary scheduled sleep.
- **Minimum off duration** (default 5 seconds). After power is cut, PowerMOD holds it off for at least this long before *anything* can bring the host back — a scheduled wake, the button, the watchdog, mains returning, any of it. **This protects against the classic power-cycle-too-fast failure:** an SBC whose rails haven't discharged below its reset threshold may not cleanly restart, and hangs or boots strangely. You will normally never notice this register — a scheduled wake is minutes or hours away — it only engages when something tries to re-power the host almost immediately. Set to 0 to disable if you know your host doesn't care.
- **Watchdog timeout.** Disabled by default. If enabled, your host must write to the watchdog register periodically to declare itself alive; if it stops for longer than the configured timeout, PowerMOD power-cycles it and records a watchdog-expiry reason code. **This is the only mechanism that recovers a host that has hung while on mains power** — without it, a hung host stays hung until someone physically intervenes (Section 5.2). Recommended for remote or unattended deployments. PowerMOD doesn't know or care *why* your host stopped writing — it only restores service.

  **The watchdog does not start counting until your host kicks it for the first time after each power-on.** This means a slow boot can never trip it: if your host takes three minutes to come up and your timeout is 60 seconds, nothing happens until your software is actually running and has kicked once. It also means a host that never kicks at all is never watchdogged, so enabling this register can't strand software that doesn't know about it. Once your host has kicked once, the watchdog stays armed until power is cut — so make sure your kick lives somewhere that runs for as long as your host is up, not just at startup.

  **A late kick during the watchdog's own shutdown window cancels it.** If your host was busy rather than hung — it missed the deadline, the forced-delay window opened, and *then* it kicked — the shutdown is called off and logged, exactly parallel to a second button press cancelling a button-initiated shutdown. The watchdog exists to restore service; power-cycling a host that has just proven it's alive would do the opposite. (This is the only thing that cancels a watchdog shutdown — the button does not, and nothing cancels a low-battery cutoff.)
- **Maximum sleep before forced wake.** Disabled by default (see Section 4.2). If enabled, PowerMOD wakes unconditionally after this duration even with no schedule set — a safety net against a device being stranded off indefinitely by a failed/missing schedule write. If both a normal scheduled wake and this safety timeout are active at once, whichever time arrives first wins — no special precedence beyond that. "Unconditionally" means *even with no schedule* — it does not mean *onto a dying battery*: like a scheduled wake (Section 4.2), a max-sleep expiry while the battery is below the recovery threshold with no mains is held, and fires once power is usable.
- **Protocol/firmware version.** Read-only register — check this once at integration time if you care about compatibility across firmware revisions.

### 4.5 Firmware Updates

PowerMOD's firmware can be updated in the field via its 4-pin **SWD** header (GND, SWCLK, SWDIO, NRST). Use any SWD programmer — an ST-Link clone, a CMSIS-DAP/DAPLink, or a J-Link — driven by PyOCD or OpenOCD (PY32F0 support is upstream in both). **The two battery-status LEDs share the SWDIO/SWCLK pins, so the debugger must _connect under reset_ — that is why NRST is brought out to the header.** The USB-serial bootloader (via BOOT0) is the fallback if SWD is unavailable. One caution: **do not flash with a deeply-discharged battery attached** — the programmer's 3.3 V can back-feed through the LDO. Configuration (voltage thresholds, power-on mode, I2C address, RTC calibration) is kept in a reserved flash region (the PY32 has no separate EEPROM); a normal firmware update preserves it, but a full chip-erase clears it — use your programmer's application-only (config-preserving) update, not mass-erase, unless you intend to reset configuration.

---

## 5. Frequently Asked Questions

### 5.1 What I2C address does PowerMOD use? Can I change it?

Default is 0x08. It's configurable — write the new address, then commit it (Section 4.4) — but changing it requires also updating your host-side integration code, and the new address only takes effect after a full power cycle (disconnect all power, including battery, then reconnect).

**Forgot the address you set, or want to reset all configuration back to defaults?** Hold the physical power button while power is first connected, and keep holding it for at least **5 seconds**, to trigger a factory reset.

**"Power first connected" means from completely dark — no mains *and* no battery.** On a battery-backed unit, that means disconnecting both and reconnecting while holding the button. This is deliberate, not an oversight: **a running system cannot be fat-fingered into a configuration wipe** — holding the button on a live board force-cuts the host (recoverable; Section 1.3), never resets anything. The reset gesture only exists when the board is already stateless in your hands. Conveniently, it's the same full power-down that an I2C address change already requires, so "recovery procedure" is one physical procedure: pull mains, pull battery, hold, reconnect, keep holding 5 seconds, watch for the alternating LEDs.

The reset restores the I2C address and all other configuration (voltage thresholds, power-on mode, delays, watchdog, etc.) to their defaults. **PowerMOD acknowledges the reset by alternating both LEDs for 2 seconds** — a pattern no other state uses — so you can tell it actually happened rather than guessing. (Release the button before 5 seconds and the board simply powers on normally; no reset. Your host is not powered during the 5-second window — the gesture resolves first, so a reset never yanks configuration out from under a booting host.) Your RTC time, any pending schedule, and the event log are not affected — the log in particular is deliberately preserved, since you're most likely to want it precisely when you've had to reset something.

### 5.2 What happens if my host crashes or hangs before it can issue "cut now"?

**Enable the watchdog (Section 4.4) if you want this handled automatically.** With it enabled, your host writes to a register periodically to say it's alive; if it stops, PowerMOD power-cycles it and records a watchdog-expiry reason. This is the only thing that recovers a hung host on mains power, and it's the reason to turn it on for anything remote.

**PowerMOD still does not detect or diagnose a hang** — and the distinction matters. The watchdog isn't PowerMOD noticing your host is unwell; it's your host failing to say it's well, which PowerMOD treats as a simple timeout without any idea whether you crashed, deadlocked, or just went quiet. Consistent with the core design principle (Section 1: PowerMOD never infers host state — it only acts on what the host explicitly tells it, or on the explicit absence of that).

**So the watchdog restores service; it doesn't tell you what happened.** Understanding *why* your host hung is still your own monitoring's job: if your host normally reports in (telemetry, a heartbeat, logs), a hang shows up as that reporting stopping. The event log (Section 4.3) shows what PowerMOD did around that time — including whether the watchdog fired, and how often — but not why your software hung. A device that quietly watchdog-reboots every few hours is working exactly as configured and still has a problem worth investigating.

**With the watchdog disabled (the default):**
- **On mains:** no automatic recovery from PowerMOD's side. Your host stays powered and unresponsive until you notice (via your own monitoring going quiet) and physically address it.
- **On battery:** PowerMOD's independent low-voltage cutoff (Section 4.3) will eventually force a power cycle once the battery drains below the safety threshold, protecting the battery from over-discharge — but this is not a fast recovery mechanism, and your host will be unresponsive until the battery genuinely drains.

If your host reboots on its own before it can issue "cut now" (crash, watchdog reset, or the sequence simply not completing), no special recovery logic is needed: any wake alarm that was pending simply becomes a no-op once the host is already running again (see Section 3). Nothing is stranded or requires cleanup — your host will write a fresh schedule whenever it next goes to sleep.

### 5.3 What kinds of hosts does PowerMOD actually work with?

Anything with a **3.3V** I2C bus and a power input you want controlled — PowerMOD's protocol and hardware make no assumptions beyond that. Two integration patterns are documented, covering most real projects:

**Linux SBC hosts** (any distribution — Raspberry Pi OS, Alpine, others): you are responsible for integrating the "write wake time" / "issue cut now" calls into your host's boot and shutdown sequence. A common, well-precedented integration pattern (used successfully on other embedded Linux platforms) is hooking a script into your shutdown sequence after filesystems are unmounted (e.g., a late-running script in `/etc/rc0.d/`-style shutdown ordering, or the systemd equivalent).

**Bare-metal/MCU firmware projects:** you're responsible for your own "when am I safe to cut" logic — which is often simpler than the Linux case, since there's no OS shutdown sequence to hook into. A single I2C write at the end of your application's work loop, right before you'd otherwise call your own sleep function, is typically sufficient.

Both cases use the identical I2C protocol (Section 4) — nothing about PowerMOD changes based on which one you're integrating with.

**The real boundary is 3.3V I2C, not Linux vs. bare-metal.** PowerMOD is generic across anything that can speak I2C at 3.3V logic — Linux SBCs, RP2040, ESP32, STM32, and the whole STEMMA-QT/Qwiic ecosystem. Two limits, both worth knowing before you design it in:

- **No I2C at all → not a fit.** Many routers, mini PCs/NUCs and other USB/Ethernet-only equipment simply don't expose a bus.
- **5V I2C → needs a level shifter, and will damage PowerMOD without one.** This is the case to watch: a classic 5V AVR like an Arduino Uno *can* host PowerMOD, but only through a bidirectional level shifter. See the warning at the top of Section 4. Everything modern is 3.3V and needs nothing.

### 5.4 Power connections for non-USB hosts and non-5V hosts

For power delivery to a host without a USB-C power input, use the raw VOUT/GND header (Section 1.5) instead of the USB-C output.

For a host that needs 3.3V instead of 5V, PowerMOD's output voltage (both USB-C and the raw header) is set by a jumper/solder-bridge, selectable between 5V and 3.3V — see Section 1.5. It ships set to 5V by default. **Check the jumper matches your host's expected voltage before connecting anything** — PowerMOD does not detect or protect against a mismatched setting.

**In 3.3V mode, use the raw VOUT header, not the USB-C output.** Nothing that expects USB-C power expects 3.3V on it, so the USB-C output isn't meaningful in this mode — it will still advertise itself as a nominal 5V source even though it isn't one. This won't hurt anything you're likely to plug in, but the raw header is the intended path for 3.3V hosts.

**The two outputs are one rail, not two.** The USB-C output and the raw VOUT header are the same electrical node. Practical consequences:

- **They are always at the same voltage**, whichever the jumper selects. You cannot run the USB-C port at 5V and the header at 3.3V.
- **They share one current budget.** Every figure in Section 2 is the *total* across both, not per-output. Drawing 1A from each is 2A total, and on a battery via the JST connector that is already over budget.
- **They switch off together.** VOUT is a *switched* rail — when PowerMOD powers your host down (scheduled shutdown, low-battery cutoff, button press), **both outputs go to 0V.** There is no always-on output. If you need something permanently powered, VOUT is the wrong tap.
- **⚠️ Never feed power *into* either output.** Because they are one node, back-feeding either one energises the other. This is harmless in 5V mode (5V meeting 5V), but **in 3.3V mode it puts 5V onto a 3.3V host** — an overvoltage event on your own hardware. If you run in 3.3V mode, treat *both* connection points as outputs that must never be driven.

### 5.5 Is my battery protected against reverse polarity?

**No. And the connector will not save you — it is keyed, which is exactly the problem.**

> ### ⚠️ Verify your battery's polarity with a multimeter before you plug it in
>
> **JST-PH is a keyed connector with no standardised polarity.** Roughly **half** of battery vendors wire the positive terminal to one pin, and half to the other. There is no convention, and **wire colour does not settle it either**.
>
> **This means you cannot plug it in "the wrong way round" — and that is the danger.** The plug fits exactly one way, seats perfectly, and may still be reverse polarity. There is nothing to notice and nothing to line up. **PowerMOD has no reverse-polarity protection**, and reversing a LiPo can cause permanent damage or fire.
>
> **The board's silkscreen cannot help you here.** It tells you which pin is positive on *our* side; it cannot tell you which wire your vendor put there. The only actionable check is:
>
> **Meter the battery's own connector — red probe to the pin that will mate with the pad marked `+` — before it ever goes near the board.** Do this for every new battery, and again for any battery from a different supplier, even if an identical-looking one worked last time.
>
> If you're building more than a handful, consider soldering the cell to the labelled BAT/GND pads instead of using the connector. A pad is unambiguous in a way a keyed plug is not.
>
> **This is not a PowerMOD quirk.** Boards in this category ship this hazard unmitigated as a rule — the Witty Pi 4 L3V7 uses the same PH2.0 connector, has no protection either, and does not mention polarity anywhere in its 53-page manual. We would rather tell you than match them in silence.

**Related, and more dangerous — do not connect two batteries.** PowerMOD gives you two places to attach a cell: the JST connector and the labelled BAT/GND solder pads. **They are the same electrical node.** They are two ways to connect *one* battery, not two battery inputs.

> ### ⚠️ One cell, one connection point — never both
>
> Attaching a cell to the JST connector *and* another to the BAT pads wires the two cells in **direct parallel**, with nothing between them but board copper — no fuse, no balancing, no isolation, no current limiting.
>
> - **Even with correct polarity, mismatched cells are a hazard.** The fuller cell dumps into the emptier one, limited only by their internal resistance. A full cell meeting a flat one can push **6 A or more**, for *minutes*, until they equalise. That current runs through the 2 A-rated JST connector, and it completely bypasses the charger — including the gentle preconditioning a deeply-discharged cell requires. Hard-charging a flat lithium cell at several amps is a fire risk.
> - **With one cell reversed, it is far worse than the single-cell case above.** Two cells connected in opposition are a **dead short through both of them** — roughly 8.4 V across a few hundred milliohms, on the order of **40 A**. That is a venting/fire event, not merely a destroyed charger. Two connection points also double your chances of making a polarity mistake in the first place.
> - **The charger cannot help you.** It sees a single pair of terminals and one voltage. It has no way to know there are two cells, that one is weak or aged, or that they have drifted apart.
>
> **If you want more capacity, fit one larger cell.** PowerMOD is indifferent between a 1000 mAh and a 10000 mAh battery, and this sidesteps every problem above. If you genuinely must parallel cells, join them into a **single pack with one pigtail before the board** — identical model, batch and age, each charged to within ~50 mV of the other first, and never hot-plugged onto a live pack. Do not use PowerMOD's two connection points as the joining method.
>
> Note this buys you no extra *current*, only runtime — the connector, not the battery, is what caps output (FAQ 5.10).

### 5.6 What if the I2C bus itself becomes stuck or unresponsive?

PowerMOD doesn't attempt to detect or recover from a globally stuck/jammed I2C bus itself — that's inherently your host's responsibility (most I2C bus controllers/drivers have their own bus-recovery procedures for this). What matters is the worst case is already bounded: if I2C is completely unreachable for any reason (a stuck bus, a hung host, anything else), PowerMOD's independent battery-voltage safety floor (Section 4.3) still protects against over-discharge regardless — it doesn't depend on I2C communication at all. Your host being unable to gracefully schedule or shut down in this scenario is a real limitation, but not an unsafe one.

### 5.7 PowerMOD doesn't boot the host, or immediately shuts it down again?

*[To be written once real hardware/firmware exists and real failure modes are observed — Witty Pi's own equivalent FAQ section describes several GPIO-pin-conflict-driven failures specific to their design. PowerMOD's I2C-only interface is expected to avoid that entire failure category by construction, since it shares no GPIO pins with the host and doesn't passively monitor host signal lines — but this should be confirmed against real hardware, not assumed.]*

### 5.8 How should I store PowerMOD or its battery long-term?

No PowerMOD-specific guidance beyond standard LiPo/Li-ion battery handling practices — storage voltage, self-discharge, and general care are the same as for any lithium battery-powered device. Follow your battery manufacturer's recommendations.

**One PowerMOD-specific thing that isn't storage but belongs on your radar:** PowerMOD does not check battery temperature before charging, so a cold deployment can damage cells over time even though nothing looks wrong. See the warning in Section 1.1 — it's the one battery-safety responsibility this board hands entirely to you.

### 5.9 Can I use more than one PowerMOD with the same host?

Not something PowerMOD is designed for — one board per host is the only configuration considered or intended. Using multiple PowerMODs on a shared I2C bus hasn't been tested and isn't something we're planning to support.

**The reverse also isn't supported: one PowerMOD controlled by two hosts (two I2C masters).** Behaviour in that configuration is undefined — nothing arbitrates between two hosts writing conflicting wake times, or one host issuing a power-off request while the other assumes it's still running. PowerMOD assumes exactly one controlling host, and that assumption is load-bearing throughout its design.

### 5.10 What happens if my host tries to draw too much current?

**Electrically, it's graceful — the voltage sags, nothing breaks.** The converter has its own current limit and thermal shutdown: past its limit it simply stops regulating and **VOUT droops** rather than failing. Even a dead short on the output just parks it in current limit. The power-path transistors are rated above anything the converter will pass, and the traces were sized with margin.

**What you'll actually experience** is your host browning out — a Raspberry Pi trips its undervoltage detector around 4.65V, so expect the undervoltage flag, instability and reboots. **The realistic damage is to your data, not your hardware:** a brownout mid-write is how SD cards get corrupted.

**There is one thing that genuinely can be damaged, and it's the battery connector.** Because the converter boosts from a 3.0–4.2V cell up to 5V, the *battery-side* current is much higher than what your host is drawing — roughly **3A from the cell for 2A out at 5V**. The JST-PH connector is rated 2A and has **no protection of any kind**: nothing trips, the crimp and housing simply get hot. Sustained overload on a JST-connected cell is the one case to actively avoid.

Be aware there is **no fuse, no resettable fuse, and no output overcurrent protection anywhere on the board.** The converter's internal limit is the entire protection story.

**On mains, overload has a second effect worth knowing.** PowerMOD has no input current limiting, so it will overdraw a weak supply. When that happens the input voltage sags below the battery voltage and **the cell quietly takes over the load — while you are still plugged in.** So an undersized USB supply drains your battery instead of charging it, and the charger's "full" detection is disturbed at the same time. If a device on mains is losing charge, suspect the supply before the battery.

**If you need more current:** solder the cell to the BAT/GND pads instead of using the JST connector (that's the difference between roughly 1.0–1.5A and 1.8–2.6A at 5V), keep the cell well charged, and avoid charging at peak load. Note that 3.3V mode is capped by the converter at 2A regardless, so the pads buy you nothing there. See the per-mode table in Section 2.

---

## Draft notes / TBD markers (for internal use, not final manual)

Items above marked TBD or "open item" map directly to still-open items in the design spec:
- **Standby current** — needs real hardware to measure, and **the earlier note here was itself an example of the mistake the audit found.** It read: "the RTC draws 40nA and the buck-boost 25µA, so the ~0.3mA budget looks comfortable." Those are the two *smallest* terms — 0.01% and 8% of the budget. **The dominant term is the LEDs** (~67% of it in normal sleep; see spec §LED electrical specification), and it went uncosted while the noise got checked. The budget is **tight, not comfortable**, and it turns on LED drive current and duty cycle — not on the ICs.
- ~~Operating temperature range~~ — **resolved: −30°C to +60°C with the coin cell fitted** (Section 2). The electronics are rated −40°C to +85°C; the coin cell is the limit.
- **Maximum output current (Section 2)** — resolved as a per-mode table, not a number. ~~An earlier version of this note still said "charger 1.5A input… expected ~1.2A" — both figures belonged to the charger that was replaced~~; the binding limits are now the USB source (3A), the battery connector (2A), and the converter's own switch limit, per the table in Section 2. What remains open is real converter efficiency, which shifts the table's figures a few percent and is measured on hardware, not read.
- ~~Factory reset hold duration and acknowledgment LED pattern (FAQ 5.1)~~ — **committed as v1 defaults (2026-07-15): 5s hold, both LEDs alternating for 2s.** 5s matches the force-off hold — one number for every deliberate hold gesture. Bench note only: confirm the gesture *feels* right; the values ship unless hardware contradicts them.
- ~~Default forced delay~~ — **resolved: 30.0s** (register map §11). Sized for a host to notice via polling and complete a real shutdown, not merely flush.
- FAQ 5.7 deliberately left as a placeholder — writing it now would be guessing at failure modes; better to populate once real hardware exists, same as Witty Pi's own troubleshooting section was clearly written from real support tickets, not anticipated in advance.

**Audit revision (2026-07-15).** This draft was revised alongside the spec after a cross-document audit.

> **This note previously contained a flat contradiction of the guide it summarises** — it claimed "the RTC is now a part that genuinely backs §1.2's temperature-compensation claim," while §1.2 says the opposite, because that claim was retracted. **The changelog asserted the very thing the document withdrew.** It is corrected below, and worth recording: a changelog is the last thing anyone re-reads and the first thing a reader trusts.

**Claims withdrawn — the guide previously promised things PowerMOD does not do:**
- **±1 ppm factory-calibrated RTC ("30 seconds a year").** Withdrawn 2026-07-15 with the part swap: the accuracy was real but cost more than the entire power stage, and the recommended integration modes never see it. Now ~±20 ppm (~1 min/month); §1.2's table rescaled. If your host re-syncs or uses relative scheduling, nothing changed for you.
- **Temperature-compensated RTC.** It isn't, and never was. §1.2 now publishes the actual drift curve. (The wording appears to have been lifted from a competitor's feature list — they genuinely have it; we don't.)
- **Temperature-qualified charging.** Briefly added, then removed: the 2-pin battery connector gives a sensor no route to the cell. §1.1 now warns about the hazard instead of claiming to handle it.
- **Input voltage readable.** Withdrawn when mains detection was a digital read and the number wasn't free; the hardware then changed under it, and **as of 2026-07-15 it is readable after all** (Section 4.3) — along with board temperature and a charge-complete flag from the same review. A claim that went promised → withdrawn → delivered, each move for a stated reason.
- **"Any host with I2C."** The boundary is **3.3V** I2C — a 5V host damages the board.

**Behaviour changes that affect you:**
- Power-on default is **Restore-previous-state** (was Always ON).
- **Host-requested cut no longer waits** (was 7s) — a halted host is still drawing current.
- **Minimum off-duration** added: power stays off ~5s before anything can re-power the host.
- **Hold the button 5s** to force power off immediately.
- ~~Output current derated from 3A to **~1.2A**~~ — **superseded the same day.** The charger was reversed (MCP73871 → TP4056 behind a PFET power-OR), which roughly **doubled mains output to ~2.7A**. There is now **no single output number** — it depends on your source and how the battery is wired. See the table in Section 2. A **≥2A supply is still required, ≥3A for full output.**
- **The honest floor is ~1.0A** — 5V, on battery, through the JST-PH connector, cell near empty. That is the configuration most people will run, and the one a UPS exists for.
- **Critical-battery threshold** added (3.3V default) — the Battery LED's warning state previously had nothing to trigger it.
- Emergency-cutoff LED is now a **rare flash**, not a fast blink — it runs on a cell already below its protection floor.
- **RTC backup is now optional**, on solder pads. No holder is fitted.
- Opt-in **watchdog** added; reason codes split into power-on and power-off registers; the **shutdown-pending flag** this guide already told hosts to poll now actually exists.

**Claims that became true:** the LiPo hot-swap in §1.1. Worth stating precisely, since the charger chip today is the same TP4056 the original draft speced: **wired as originally drawn** (load hanging on the battery pin) the claim was the *opposite* of the hardware's behaviour; **wired behind the power-OR PowerMOD now uses**, the battery genuinely sits out of the path on mains and the claim holds — with the undersized-supply exception §1.1 documents.

**Contradictions resolved:** the wake-time rules in §1.2b and §4.2 previously contradicted each other outright, and are now one rule.

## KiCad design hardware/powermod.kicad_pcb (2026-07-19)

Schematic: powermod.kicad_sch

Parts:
C1, C2, C7: 10u; C_0805_2012Metric
C3, C4, C5: 22u; C_0805_2012Metric
C6: 4.7u; C_0603_1608Metric
C8, C9: 1u; C_0603_1608Metric
C10, C11, C12, C13, C14, C15, C16: 100n; C_0402_1005Metric
D1, D2: TJ-S3227; LED_TJ-S3227_RG_3.2x2.7mm
D3, D4, D5: 1N4148WS; D_SOD-323
J1: USB_C_IN; USB_C_Receptacle_TYPE-C_16P_PowerMerged
J2: USB_C_OUT; USB_C_Receptacle_TYPE-C_16P_PowerMerged
J3: JST_PH_2; JST_PH_S2B-PH-K_1x02_P2.00mm_Horizontal
J4: STEMMA_QT; JST_SH_SM04B-SRSS-TB_1x04-1MP_P1.00mm_Horizontal
J5: SWD_HDR; PinHeader_1x04_P2.54mm_Vertical
JP1: CHG_JUMPER; SolderJumper-2_P1.3mm_Open_RoundedPad1.0x1.5mm
JP2: VSEL_JUMPER; SolderJumper-2_P1.3mm_Open_RoundedPad1.0x1.5mm
L1: 1.5uH; L_Sumida_CDMC6D28_7.25x6.5mm
Q1, Q2: AON7407; DFN-8-1EP_3x3mm_P0.65mm_EP1.6x2.56mm
Q3: BSS138; SOT-23
R1: 1.2k; R_0402_1005Metric
R2, R3: 5.1k; R_0402_1005Metric
R4, R5: 56k; R_0402_1005Metric
R6, R8, R25: 1M; R_0402_1005Metric
R7, R9: 330k; R_0402_1005Metric
R10, R12, R13, R14, R28: 100k; R_0402_1005Metric
R11: 47k; R_0402_1005Metric
R15, R16, R17, R18, R19: 10k; R_0402_1005Metric
R20, R21, R22, R23: 560; R_0402_1005Metric
R24: 180k; R_0402_1005Metric
R26: 620k; R_0402_1005Metric
R27: 1k; R_0402_1005Metric
SW1: BUTTON; SW_SPST_PTS647_Sx50
TP1: VBACKUP_PAD; TestPoint_Pad_2.0x2.0mm
TP2: BAT_PAD; TestPoint_Pad_2.0x2.0mm
TP3: VOUT_PAD; TestPoint_Pad_2.0x2.0mm
TP4: GND_PAD; TestPoint_Pad_2.0x2.0mm
TP5: VBACKUP_GND_PAD; TestPoint_Pad_2.0x2.0mm
TP6: VOUT_GND_PAD; TestPoint_Pad_2.0x2.0mm
U1: BM8563ESA; SOIC-8_3.9x4.9mm_P1.27mm
U2: PY32F003F18P6; TSSOP-20_4.4x6.5mm_P0.65mm
U3: TPS63020DSJR; VSON-14-1EP_3x4.45mm_P0.65mm_EP1.6x4.2mm
U4: TP4056; SOIC-8-1EP_3.9x4.9mm_P1.27mm_EP2.29x3mm
U5: XC6206P332MR; SOT-23
Y1: Q13FC13500004; Crystal_SMD_3215-2Pin_3.2x1.5mm

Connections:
3V3: C9.1, C14.1, D3.2 (A), R15.1, R16.1, R17.1, R18.1, R19.1, R27.1, U2.9 (VDD), U5.2 (VOUT)
BUTTON: SW1.1 (A), U2.20 (PA1/BUTTON)
CC1_IN: J1.A5 (CC1), R2.1
CC1_OUT: J2.A5 (CC1), R5.1
CC2_IN: J1.B5 (CC2), R3.1
CC2_OUT: J2.B5 (CC2), R4.1
CHG_CE: R28.2, U2.5 (PA6/CHG_CE), U4.8 (CE)
CHG_CHRG: R15.2, U2.12 (PB5/CHG_CHRG), U4.7 (CHRG)
CHG_JP: D5.2 (A), R27.2
CHG_JPD: D5.1 (K), JP1.1 (A)
CHG_STDBY: R16.2, U2.6 (PA7/CHG_STDBY), U4.6 (STDBY)
CONV_EN: R14.1, U2.2 (PA3/CONV_EN), U3.12 (EN)
D1_GRN: D1.2 (A_GRN), R21.2
D1_RED: D1.3 (A_RED), R20.2
D2_GRN: D2.2 (A_GRN), R23.2
D2_RED: D2.3 (A_RED), R22.2
FB: R24.1, R25.1, U3.3 (FB)
FB_MID: JP2.1 (A), R25.2, R26.1
GND: C1.2, C2.2, C3.2, C4.2, C5.2, C6.2, C7.2, C8.2, C9.2, C10.2, C11.2, C13.2, C14.2, C15.2, C16.2, D1.1 (K_GRN), D1.4 (K_RED), D2.1 (K_GRN), D2.4 (K_RED), J1.A1 (GND), J1.A12 (GND), J1.SH (SHIELD), J2.A1 (GND), J2.A12 (GND), J2.SH (SHIELD), J3.2 (BAT-), J4.1 (GND), J5.1 (GND), Q3.2 (S), R1.2, R2.2, R3.2, R7.2, R9.2, R12.2, R13.2, R14.2, R24.2, SW1.2 (B), TP4.1, TP5.1, TP6.1, U1.4 (VSS), U2.7 (VSS), U3.2 (GND), U3.13 (PS/SYNC), U3.15 (PGND), U4.1 (TEMP), U4.3 (GND), U4.9 (PAD), U5.1 (VSS)
L1N: L1.1, U3.8 (L1), U3.9 (L1)
L2: L1.2, U3.6 (L2), U3.7 (L2)
LED_BAT_A: J5.3 (SWDIO), R22.1, U2.10 (PA13/SWDIO/LED_BAT_A)
LED_BAT_B: J5.2 (SWCLK), R23.1, U2.11 (PA14/SWCLK/LED_BAT_B)
LED_PWR_A: R20.1, U2.19 (PA0/LED_PWR_A)
LED_PWR_B: R21.1, U2.15 (PF4/BOOT0/LED_PWR_B)
NRST: J5.4 (NRST), U2.18 (PF2/NRST)
OSCI: U1.1 (OSCI), Y1.1 (X1)
OSCO: U1.2 (OSCO), Y1.2 (X2)
PROG: R1.1, U4.2 (PROG)
Q1_GATE: C12.2, Q1.4 (G), R10.2, R11.1
Q1_GATE_DRV: Q3.1 (G), R13.1, U2.1 (PA2/Q1_GATE_DRV)
Q3_DRAIN: Q3.3 (D), R11.2
RTC_INT: R19.2, U1.3 (INT), U2.8 (PA12/RTC_INT)
RTC_SCL: R18.2, U1.6 (SCL), U2.17 (PF1/RTC_SCL)
RTC_SDA: R17.2, U1.5 (SDA), U2.16 (PF0/RTC_SDA)
RTC_VDD: C13.1, D3.1 (K), D4.1 (K), U1.8 (VDD)
SCL: J4.4 (SCL), U2.13 (PB6/I2C_SCL)
SDA: J4.3 (SDA), U2.14 (PB7/I2C_SDA)
VBACKUP: D4.2 (A), JP1.2 (B), TP1.1
VBAT: C6.1, J3.1 (BAT+), Q2.5 (D), Q2.6 (D), Q2.7 (D), Q2.8 (D), Q2.9 (D), R6.1, TP2.1, U4.5 (BAT)
VBAT_DIV: C10.1, R6.2, R7.1, U2.3 (PA4/VBAT_SENSE)
VBUS: C7.1, C15.1, J1.A4 (VBUS), J1.A9 (VBUS), Q1.5 (D), Q1.6 (D), Q1.7 (D), Q1.8 (D), Q1.9 (D), Q2.4 (G), R8.1, R12.1, R28.1, U4.4 (VCC)
VBUS_DIV: C11.1, R8.2, R9.1, U2.4 (PA5/VBUS_SENSE)
VOUT: C3.1, C4.1, C5.1, J2.A4 (VBUS), J2.A9 (VBUS), JP2.2 (B), R4.2, R5.2, R26.2, TP3.1, U3.4 (VOUT), U3.5 (VOUT)
VSYS: C1.1, C2.1, C8.1, C12.1, C16.1, Q1.1 (S), Q1.2 (S), Q1.3 (S), Q2.1 (S), Q2.2 (S), Q2.3 (S), R10.1, U3.1 (VINA), U3.10 (VIN), U3.11 (VIN), U5.3 (VIN)

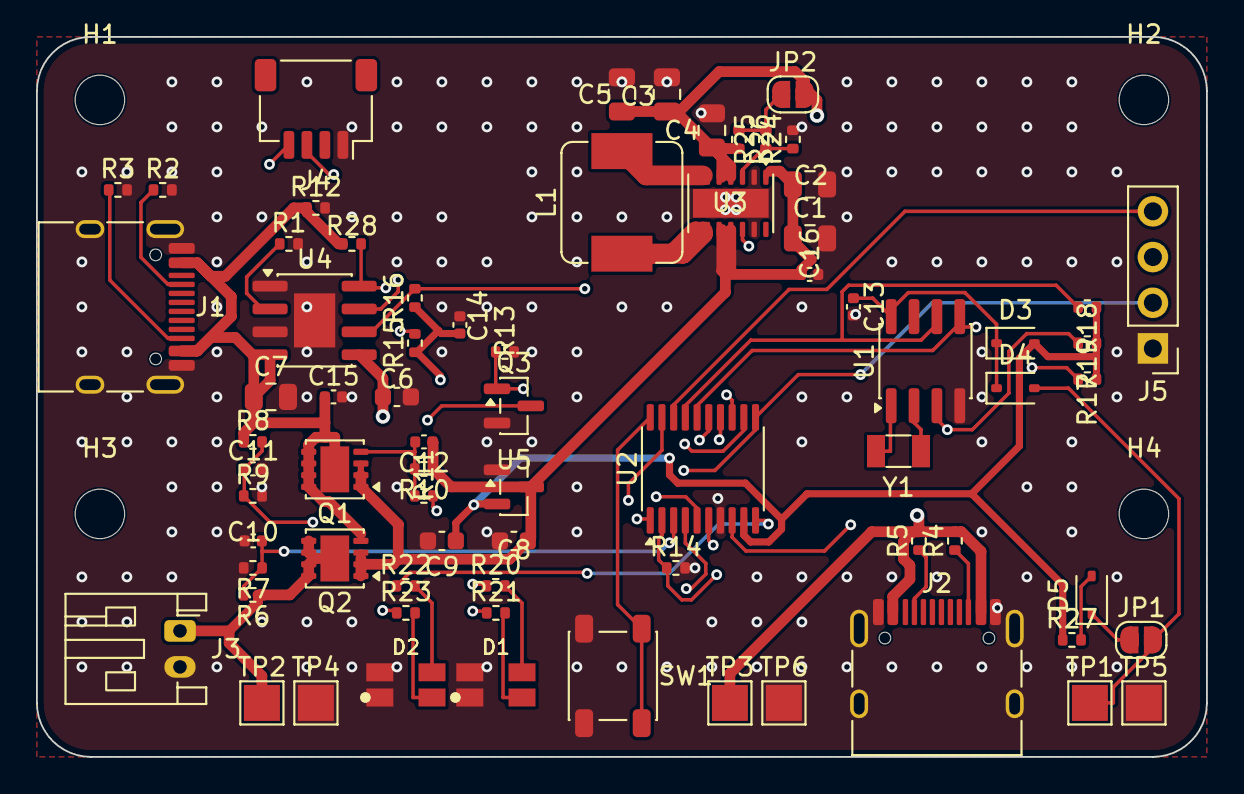
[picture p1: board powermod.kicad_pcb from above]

Board: 4 copper layers, 65.0 x 40.0 mm, 77 parts (0 on the bottom side), 45 nets.

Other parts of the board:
H1, H2, H3, H4: M2.5; MountingHole_2.7mm_M2.5

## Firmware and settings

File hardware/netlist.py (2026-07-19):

#!/usr/bin/env python3
"""PowerMOD — machine netlist, transcribed from ../powermod-schematic.md.

Single source of truth for generated KiCad artifacts:
  powermod.net        KiCad S-expression netlist (pcbnew: File > Import Netlist)
  powermod.kicad_sch  KiCad 7 schematic, global-label style (connectivity by
                      net labels on every pin; no drawn wires). Open, annotate
                      is already done, run ERC there — kicad-cli was not
                      available where this was generated.

Every (ref, pin, net) below is transcribed from powermod-schematic.md, whose
pin numbers were themselves extracted from datasheets. Footprint fields are
best-effort standard-library names — verify each in KiCad's footprint browser
before layout (checklist item 9).
"""
import uuid, sys, os

# ---------------------------------------------------------------- components
# ref: (value, footprint_besteffort, lcsc, {pin: (pinname, net)})
# net "NC" = deliberately unconnected (emitted as no-connect in the sch).
FP = {
  'R04':'Resistor_SMD:R_0402_1005Metric', 'R06':'Resistor_SMD:R_0603_1608Metric',
  'C04':'Capacitor_SMD:C_0402_1005Metric','C06':'Capacitor_SMD:C_0603_1608Metric',
  'C08':'Capacitor_SMD:C_0805_2012Metric','SOT':'Package_TO_SOT_SMD:SOT-23',
  'SOD':'Diode_SMD:D_SOD-323','TP':'TestPoint:TestPoint_Pad_2.0x2.0mm',
  'SJ':'Jumper:SolderJumper-2_P1.3mm_Open_RoundedPad1.0x1.5mm',
}
COMPONENTS = {
 # --- ICs ---
 # LCSC verified 2026-07-17: C194063 is the TSSOP-8 BM8563 (wrong package, OOS).
 # C269877 = BM8563ESA, SOP-8 -> matches this SOIC-8 footprint. ~80k in stock.
 'U1': ('BM8563ESA', 'Package_SO:SOIC-8_3.9x4.9mm_P1.27mm', 'C269877', {
   '1':('OSCI','OSCI'), '2':('OSCO','OSCO'), '3':('INT','RTC_INT'), '4':('VSS','GND'),
   '5':('SDA','RTC_SDA'), '6':('SCL','RTC_SCL'), '7':('CLKOUT','NC'), '8':('VDD','RTC_VDD')}),
 # PY32F003F18P6TU (Puya, ARM Cortex-M0+ 48MHz, TSSOP-20, LCSC C5379864, ~22k
 # stock, Extended). Replaces the ATtiny1616: NO well-stocked AVR exists at JLC
 # in any package — the whole tinyAVR 1-series AND megaAVR-0 line are <~100 units
 # each, all Extended (checked 2026-07-18). Pinout transcribed from the LCSC/
 # EasyEDA symbol (C5379864) verified 2026-07-18. Constraints honoured:
 #   ADC  -> PA4/PA5 (ADC_IN4/5)          HW I2C1 -> PB6/PB7 (STEMMA bus)
 #   RTC I2C bit-banged -> PF0/PF1        SWD -> PA13/PA14, shared with the 2 BAT
 #   LEDs (LEDs tolerate SWD idle; debugger connects under reset via NRST=PF2 on
 #   the header). BOOT0=PF4 carries an LED OUTPUT only (Hi-Z at reset -> internal
 #   pull-down -> boots flash; never put an input on BOOT0). 0 spare pins.
 # ADC ref = VDD (3.3V, the XC6206 rail). Existing 1M/330k dividers peak at
 # VBUS 5.25V->1.30V, VBAT 4.25V->1.05V: no clip, ~1.6k/1.3k of 4096 counts
 # (finer than the ATtiny's 10-bit) -> dividers UNCHANGED (also keeps the BOM to
 # common in-stock values). Ref accuracy = LDO ±2%; firmware can trim vs the
 # internal bandgap if needed. Net names are IDENTICAL to the ATtiny mapping
 # (only pin assignment moved) except UPDI dropped / NRST added.
 'U2': ('PY32F003F18P6', 'Package_SO:TSSOP-20_4.4x6.5mm_P0.65mm', 'C5379864', {
   '1':('PA2/Q1_GATE_DRV','Q1_GATE_DRV'), '2':('PA3/CONV_EN','CONV_EN'),
   '3':('PA4/VBAT_SENSE','VBAT_DIV'),     '4':('PA5/VBUS_SENSE','VBUS_DIV'),
   '5':('PA6/CHG_CE','CHG_CE'),           '6':('PA7/CHG_STDBY','CHG_STDBY'),
   '7':('VSS','GND'),                     '8':('PA12/RTC_INT','RTC_INT'),
   '9':('VDD','3V3'),                     '10':('PA13/SWDIO/LED_BAT_A','LED_BAT_A'),
   '11':('PA14/SWCLK/LED_BAT_B','LED_BAT_B'), '12':('PB5/CHG_CHRG','CHG_CHRG'),
   '13':('PB6/I2C_SCL','SCL'),            '14':('PB7/I2C_SDA','SDA'),
   '15':('PF4/BOOT0/LED_PWR_B','LED_PWR_B'), '16':('PF0/RTC_SDA','RTC_SDA'),
   '17':('PF1/RTC_SCL','RTC_SCL'),        '18':('PF2/NRST','NRST'),
   '19':('PA0/LED_PWR_A','LED_PWR_A'),    '20':('PA1/BUTTON','BUTTON')}),
 'U3': ('TPS63020DSJR', 'Package_SON:VSON-14-1EP_3x4.45mm_P0.65mm_EP1.6x4.2mm', 'C15483', {
   '1':('VINA','VSYS'), '2':('GND','GND'), '3':('FB','FB'), '4':('VOUT','VOUT'),
   '5':('VOUT','VOUT'), '6':('L2','L2'), '7':('L2','L2'), '8':('L1','L1N'),
   '9':('L1','L1N'), '10':('VIN','VSYS'), '11':('VIN','VSYS'), '12':('EN','CONV_EN'),
   '13':('PS/SYNC','GND'), '14':('PG','NC'), '15':('PGND','GND')}),
 'U4': ('TP4056', 'Package_SO:SOIC-8-1EP_3.9x4.9mm_P1.27mm_EP2.29x3mm', 'C382139', {
   '1':('TEMP','GND'), '2':('PROG','PROG'), '3':('GND','GND'), '4':('VCC','VBUS'),
   '5':('BAT','VBAT'), '6':('STDBY','CHG_STDBY'), '7':('CHRG','CHG_CHRG'),
   '8':('CE','CHG_CE'), '9':('PAD','GND')}),
 # Pinout VERIFIED 2026-07-19 vs Torex XC6206 datasheet: the XC6206 has TWO
 # pin variants (MR vs PR). Ours is the -MR- package (C5446 = XC6206P332MR-G),
 # whose SOT-23 assignment is pin1=VSS, pin2=VOUT, pin3=VIN -> matches below.
 # (The PR package differs; do NOT copy this to a PR part.)
 'U5': ('XC6206P332MR', FP['SOT'], 'C5446', {
   '1':('VSS','GND'), '2':('VOUT','3V3'), '3':('VIN','VSYS')}),
 # --- FETs ---
 'Q1': ('AON7407', 'Package_DFN_QFN:DFN-8-1EP_3x3mm_P0.65mm_EP1.6x2.56mm', 'C176756', {
   '1':('S','VSYS'), '2':('S','VSYS'), '3':('S','VSYS'), '4':('G','Q1_GATE'),
   '5':('D','VBUS'), '6':('D','VBUS'), '7':('D','VBUS'), '8':('D','VBUS'), '9':('D','VBUS')}),
 'Q2': ('AON7407', 'Package_DFN_QFN:DFN-8-1EP_3x3mm_P0.65mm_EP1.6x2.56mm', 'C176756', {
   '1':('S','VSYS'), '2':('S','VSYS'), '3':('S','VSYS'), '4':('G','VBUS'),
   '5':('D','VBAT'), '6':('D','VBAT'), '7':('D','VBAT'), '8':('D','VBAT'), '9':('D','VBAT')}),
 'Q3': ('BSS138', FP['SOT'], 'C52895', {         # pin order = convention, VERIFY
   '1':('G','Q1_GATE_DRV'), '2':('S','GND'), '3':('D','Q3_DRAIN')}),
 # --- diodes / LEDs / crystal ---
 # TOGIALED TJ-S3227 dual-die LED, LCSC C601677 (~7.7k stock, yellow-green die
 # fixes the dim-green problem). Pinout from LCSC's EasyEDA model (verified
 # 2026-07-17): two INDEPENDENT diodes, top row anode=3 cathode=4, bottom row
 # anode=2 cathode=1. Local footprint matches that numbering (stock KiCad Avago
 # PLCC4 numbers the pads the OTHER way -> would reverse polarity, so NOT used).
 # Mapping below is polarity-correct (anodes->drive nets, cathodes->GND).
 # Red-vs-green DIE identity (top=RED assumed here) is not fixed by the EasyEDA
 # data; it's electrically irrelevant (both dies, identical 560R) and firmware-
 # adjustable — confirm against the datasheet colour drawing at assembly if the
 # silk label must match. Both D1/D2 are the same part, so any swap is uniform.
 'D1': ('TJ-S3227', 'powermod:LED_TJ-S3227_RG_3.2x2.7mm', 'C601677', {
   '1':('K_GRN','GND'), '2':('A_GRN','D1_GRN'), '3':('A_RED','D1_RED'), '4':('K_RED','GND')}),
 'D2': ('TJ-S3227', 'powermod:LED_TJ-S3227_RG_3.2x2.7mm', 'C601677', {
   '1':('K_GRN','GND'), '2':('A_GRN','D2_GRN'), '3':('A_RED','D2_RED'), '4':('K_RED','GND')}),
 'D3': ('1N4148WS', FP['SOD'], 'C51898295', {'1':('K','RTC_VDD'), '2':('A','3V3')}),
 'D4': ('1N4148WS', FP['SOD'], 'C51898295', {'1':('K','RTC_VDD'), '2':('A','VBACKUP')}),
 # D5 blocks the supercap back-draining through R27 into a dead 3V3 rail
 # (~3mA vs the RTC's 0.25uA — found in the 2026-07-17 pre-fab audit).
 # Charge path is now 3V3 -> R27 -> D5 -> JP1 -> VBACKUP; ceiling ~2.85V.
 'D5': ('1N4148WS', FP['SOD'], 'C51898295', {'1':('K','CHG_JPD'), '2':('A','CHG_JP')}),
 # Epson Q13FC13500004: 32.768kHz, CL=12.5pF (matches BM8563 internal caps),
 # 3215 2-pin, +-20ppm. LCSC C32346, ~286k stock (verified 2026-07-17).
 'Y1': ('Q13FC13500004', 'Crystal:Crystal_SMD_3215-2Pin_3.2x1.5mm', 'C32346', {
   '1':('X1','OSCI'), '2':('X2','OSCO')}),
 # --- connectors / electromech ---
 # merged-pad USB-C: reversible twins (A4≡B9, A9≡B4, A1≡B12, A12≡B1) share ONE pad,
 # so VBUS/GND are single pads -> no coincident-pad DRC flags, cleaner escape.
 # CC PINS = A5/B5 (2026-07-19, CORRECTED): the footprint is NOT mirrored. Verified
 # three ways — (1) USB-C spec: CC1=A5, CC2=B5, SBU1=A8, SBU2=B8; (2) the real
 # C165948 is the TYPE-C-31-M-12, standard pinout (LCSC/EasyEDA land pattern);
 # (3) KiCad's authoritative HRO TYPE-C-31-M-12 footprint is geometrically
 # IDENTICAL to ours (pad "A5" @ x=-1.25 = CC1, pad "A8" @ x=+1.25 = SBU1). So CC
 # belongs on A5/B5 and A8/B8 are the (unused) SBU pins -> NC. NOTE: commit a2826a7
 # wrongly moved CC to A8/B8 on a bogus "mirrored footprint" claim — that put the CC
 # resistors on the floating SBU pins (board would not negotiate VBUS). This reverts
 # it. Do NOT move CC off A5/B5 again without re-checking against the HRO footprint.
 'J1': ('USB_C_IN', 'powermod:USB_C_Receptacle_TYPE-C_16P_PowerMerged', 'C165948', {
   'A1':('GND','GND'),'A12':('GND','GND'),
   'A4':('VBUS','VBUS'),'A9':('VBUS','VBUS'),
   'A5':('CC1','CC1_IN'),'B5':('CC2','CC2_IN'), 'A8':('nc','NC'),'B8':('nc','NC'),
   'A6':('D+','NC'),'A7':('D-','NC'),'B6':('D+','NC'),'B7':('D-','NC'),'SH':('SHIELD','GND')}),
 # CC on A5/B5, A8/B8 (SBU) -> NC (see the corrected note above).
 'J2': ('USB_C_OUT', 'powermod:USB_C_Receptacle_TYPE-C_16P_PowerMerged', 'C165948', {
   'A1':('GND','GND'),'A12':('GND','GND'),
   'A4':('VBUS','VOUT'),'A9':('VBUS','VOUT'),
   'A5':('CC1','CC1_OUT'),'B5':('CC2','CC2_OUT'), 'A8':('nc','NC'),'B8':('nc','NC'),
   'A6':('D+','NC'),'A7':('D-','NC'),'B6':('D+','NC'),'B7':('D-','NC'),'SH':('SHIELD','GND')}),
 # LCSC blanked -> DNP/hand-solder (THT). SMT-only assembly order; hand-solder the
 # 2-pin JST battery connector yourself (part = JST S2B-PH-K / LCSC C173752 if you
 # source it). Same treatment as J5. Part still on the board + CPL, just not placed.
 'J3': ('JST_PH_2', 'Connector_JST:JST_PH_S2B-PH-K_1x02_P2.00mm_Horizontal', None, {
   '1':('BAT+','VBAT'), '2':('BAT-','GND')}),
 'J4': ('STEMMA_QT', 'Connector_JST:JST_SH_SM04B-SRSS-TB_1x04-1MP_P1.00mm_Horizontal', 'C51940130', {
   '1':('GND','GND'), '2':('VCC_NC','NC'), '3':('SDA','SDA'), '4':('SCL','SCL')}),
 # SWD programming header (was 3-pin UPDI). PY32 = 2-wire SWD; target is USB-
 # powered while flashing, so no VCC pin needed. 1x04 GND/SWCLK/SWDIO/NRST — the
 # 4th pin folds NRST into the header (replaces the old TP7 probe pad) so
 # connect-under-reset is a proper header pin. Needed because the two BAT LEDs
 # share SWDIO/SWCLK, so a debugger must hold NRST low to attach. 4th pad lands at
 # ~(53,25.1), ~1.7mm clear of R5. Hand-solder, DNP.
 'J5': ('SWD_HDR', 'Connector_PinHeader_2.54mm:PinHeader_1x04_P2.54mm_Vertical', None, {
   '1':('GND','GND'), '2':('SWCLK','LED_BAT_B'), '3':('SWDIO','LED_BAT_A'),
   '4':('NRST','NRST')}),
 # C&K PTS647SN50SMTR2LFS (C2799414, ~9k stock) — in-stock sibling of the OOS
 # SK50; identical PTS647 4.5x4.5 SMD land pattern (Sx50 footprint), N vs K is
 # only plunger height. Drop-in, no board change.
 'SW1':('BUTTON', 'Button_Switch_SMD:SW_SPST_PTS647_Sx50', 'C2799414', {
   '1':('A','BUTTON'), '2':('B','GND')}),
 'JP1':('CHG_JUMPER', FP['SJ'], None, {'1':('A','CHG_JPD'), '2':('B','VBACKUP')}),
 'JP2':('VSEL_JUMPER', FP['SJ'], None, {'1':('A','FB_MID'), '2':('B','VOUT')}),
 # CYA0650-1.5UH (Chilisin, C5189751, ~11k stock, Extended) — in-stock swap for
 # the OOS Sumida CDMC6D28. Its lands are 2.35x3.5mm @ 5.7mm PITCH; the pitch
 # matches this footprint (Sumida pads were 2.0x3.4mm @ 5.7mm), and body is
 # 7.2x6.6mm ~ the Sumida's 7.25x6.5mm, so it drops onto the existing land
 # pattern with NO board change (terminals slightly wider than the pads ->
 # solders fine). Rating: a 7.2x6.6mm 1.5uH molded part is Isat ~9A typ, well
 # above the 3-4A converter peak — CONFIRM exact Isat/Irms on the datasheet.
 'L1': ('1.5uH', 'Inductor_SMD:L_Sumida_CDMC6D28_7.25x6.5mm', 'C5189751', {
   '1':('1','L1N'), '2':('2','L2')}),
 # --- test pads ---
 'TP1':('VBACKUP_PAD', FP['TP'], None, {'1':('P','VBACKUP')}),
 'TP2':('BAT_PAD',     FP['TP'], None, {'1':('P','VBAT')}),
 'TP3':('VOUT_PAD',    FP['TP'], None, {'1':('P','VOUT')}),
 'TP4':('GND_PAD',     FP['TP'], None, {'1':('P','GND')}),
 'TP5':('VBACKUP_GND_PAD', FP['TP'], None, {'1':('P','GND')}),
 'TP6':('VOUT_GND_PAD',    FP['TP'], None, {'1':('P','GND')}),
}
# JLC part numbers for the jellybean passives (verified on lcsc.com 2026-07-17).
# Resistors: UNI-ROYAL 0402WGF series (JLC Basic). Caps: Samsung CL-series
# (Basic) except 1u=C5673 (Extended, 25V, well-stocked; the Basic 50V had 50 in stock).
PASSIVE_LCSC = {
  '560':'C137858','1k':'C11702','1.2k':'C25862','5.1k':'C25905','10k':'C25744',  # 560R: YAGEO RC0402JR-07560RL (was UNI-ROYAL C25126, JLC shortfall 2026-07-19)
  '47k':'C25792','56k':'C25796','100k':'C25741','180k':'C25760','330k':'C25778',
  '620k':'C270590','1M':'C26083',
  '100n':'C1525','10u':'C15850','22u':'C45783','1u':'C5673','4.7u':'C19666',
}
def R(val,a,b,fp='R04'): return (val, FP[fp], PASSIVE_LCSC.get(val), {'1':('1',a),'2':('2',b)})
def C(val,a,b,fp='C04'): return (val, FP[fp], PASSIVE_LCSC.get(val), {'1':('1',a),'2':('2',b)})
COMPONENTS.update({
 'R1': R('1.2k','PROG','GND'),          # TP4056 1A
 'R2': R('5.1k','CC1_IN','GND'),  'R3': R('5.1k','CC2_IN','GND'),
 # R4/R5 swapped vs CC1/CC2 (2026-07-19): CC1/CC2 are symmetric (identical 56k Rp),
 # and after the A5/B5 CC fix R4 sits beside J2.B5 and R5 beside J2.A5 — so label
 # R5=CC1_OUT (->A5), R4=CC2_OUT (->B5) to keep each Rp next to its pad, no crossover.
 'R4': R('56k','CC2_OUT','VOUT'), 'R5': R('56k','CC1_OUT','VOUT'),
 'R6': R('1M','VBAT','VBAT_DIV'), 'R7': R('330k','VBAT_DIV','GND'),
 'R8': R('1M','VBUS','VBUS_DIV'), 'R9': R('330k','VBUS_DIV','GND'),
 'R10':R('100k','VSYS','Q1_GATE'),      # Q1 pull-up
 'R11':R('47k','Q1_GATE','Q3_DRAIN'),   # gate series
 'R12':R('100k','VBUS','GND'),          # Q2 gate pulldown (gate tied to VBUS)
 'R13':R('100k','Q1_GATE_DRV','GND'),   # Q3 gate pulldown
 'R14':R('100k','CONV_EN','GND'),       # EN defined during MCU reset
 'R15':R('10k','3V3','CHG_CHRG'), 'R16':R('10k','3V3','CHG_STDBY'),
 'R17':R('10k','3V3','RTC_SDA'),  'R18':R('10k','3V3','RTC_SCL'),
 'R19':R('10k','3V3','RTC_INT'),        # to 3V3, NOT VBACKUP (claims row 39)
 'R20':R('560','LED_PWR_A','D1_RED'), 'R21':R('560','LED_PWR_B','D1_GRN'),
 'R22':R('560','LED_BAT_A','D2_RED'), 'R23':R('560','LED_BAT_B','D2_GRN'),
 'R24':R('180k','FB','GND'), 'R25':R('1M','FB','FB_MID'), 'R26':R('620k','FB_MID','VOUT'),
 'R27':R('1k','3V3','CHG_JP'),          # supercap charge, behind JP1
 'R28':R('100k','VBUS','CHG_CE'),       # CE default-ON: TP4056 charges even with the MCU in reset/unprogrammed (2026-07-16); MCU PC4 push-pull overrides
 'C1': C('10u','VSYS','GND','C08'),  'C2': C('10u','VSYS','GND','C08'),
 'C3': C('22u','VOUT','GND','C08'),  'C4': C('22u','VOUT','GND','C08'),
 'C5': C('22u','VOUT','GND','C08'),
 'C6': C('4.7u','VBAT','GND','C06'), 'C7': C('10u','VBUS','GND','C08'),
 'C8': C('1u','VSYS','GND','C06'),   'C9': C('1u','3V3','GND','C06'),
 'C10':C('100n','VBAT_DIV','GND'),   'C11':C('100n','VBUS_DIV','GND'),
 'C12':C('100n','VSYS','Q1_GATE'),   # Q1 gate-source
 'C13':C('100n','RTC_VDD','GND'), 'C14':C('100n','3V3','GND'), 'C15':C('100n','VBUS','GND'),
 'C16':C('100n','VSYS','GND'),       # VINA decoupling — TI ref design (found at transcription)
})

# ------------------------------------------------------------------ validate
def build_nets():
    nets={}
    for ref,(val,fp,lcsc,pins) in COMPONENTS.items():
        for pin,(pname,net) in pins.items():
            nets.setdefault(net,[]).append((ref,pin))
    return nets

def validate():
    nets=build_nets(); errs=[]
    # non-NC nets must have >=2 nodes
    for net,nodes in nets.items():
        if net!='NC' and len(nodes)<2: errs.append(f"singleton net {net}: {nodes}")
    # board-killer golden facts (from powermod-schematic.md §3 checklist)
    G=[('Q1','1','VSYS'),('Q1','4','Q1_GATE'),('Q1','5','VBUS'),
       ('Q2','1','VSYS'),('Q2','4','VBUS'),('Q2','5','VBAT'),
       ('U4','1','GND'),('U3','13','GND'),('U3','12','CONV_EN'),
       ('U1','3','RTC_INT'),
       # PY32F003 MCU (TSSOP-20) key pins — verified vs LCSC C5379864 symbol
       ('U2','9','3V3'),('U2','7','GND'),('U2','3','VBAT_DIV'),('U2','4','VBUS_DIV'),
       ('U2','13','SCL'),('U2','14','SDA'),('U2','18','NRST'),
       ('J5','4','NRST'),('J5','3','LED_BAT_A'),
       ('J4','2','NC'),('D3','2','3V3'),('D4','2','VBACKUP'),
       ('D3','1','RTC_VDD'),('D4','1','RTC_VDD')]
    for ref,pin,net in G:
        got=COMPONENTS[ref][3][pin][1]
        if got!=net: errs.append(f"GOLDEN FAIL {ref}.{pin}: {got} != {net}")
    # INT pull-up rail
    if COMPONENTS['R19'][3]['1'][1]!='3V3': errs.append("R19 not to 3V3")
    # pin-count sanity
    expect={'U1':8,'U2':20,'U3':15,'U4':9,'U5':3,'Q1':9,'Q2':9,'Q3':3}
    for ref,npins in expect.items():
        if len(COMPONENTS[ref][3])!=npins: errs.append(f"{ref} pin count {len(COMPONENTS[ref][3])}!={npins}")
    return nets, errs

# ---------------------------------------------------------------- generators
def u(): return str(uuid.uuid4())


def gen_bom(path):
    """JLCPCB assembly BOM (Comment, Designator, Footprint, LCSC Part #).
    Test points and solder jumpers are bare copper (not components) and have no
    CPL placement, so they are OMITTED — leaving them in makes JLC warn
    'designators don't exist in the CPL file'. Real parts with no LCSC (e.g. the
    J5 header) stay, with a blank LCSC = 'do not place / hand-solder' at upload."""
    from collections import defaultdict
    NONPLACED=('TestPoint','SolderJumper','Jumper')  # copper features, not parts
    groups=defaultdict(list)  # (value, footprint, lcsc) -> [refs]
    for ref,(val,fp,lcsc,pins) in COMPONENTS.items():
        if any(k in fp for k in NONPLACED): continue
        groups[(val,fp,lcsc or '')].append(ref)
    def keyf(r): return (r[0][0], int(''.join(c for c in r[0] if c.isdigit()) or 0))
    rows=[]
    for (val,fp,lcsc),refs in groups.items():
        des=','.join(sorted(refs,key=lambda r:(r[0],int(''.join(c for c in r if c.isdigit()) or 0))))
        rows.append((des,val,fp.split(':')[-1],lcsc))
    rows.sort(key=lambda x:x[0])
    out=['"Comment","Designator","Footprint","LCSC Part #"']
    for des,val,fp,lcsc in rows:
        out.append(f'"{val}","{des}","{fp}","{lcsc}"')
    open(path,'w').write('\n'.join(out)+'\n')
    placed=sum(1 for r in rows if r[3]); nolcsc=[r[0] for r in rows if not r[3]]
    return len(rows), placed, nolcsc

def gen_net(path):
    nets,_=validate()
    out=['(export (version "E")\n (components']
    for ref,(val,fp,lcsc,_) in sorted(COMPONENTS.items()):
        f=f'\n   (fields (field (name "LCSC") "{lcsc}"))' if lcsc else ''
        out.append(f'  (comp (ref "{ref}") (value "{val}") (footprint "{fp}"){f})')
    out.append(' )\n (nets')
    code=1
    for net,nodes in sorted(nets.items()):
        if net=='NC': continue
        ns=''.join(f'\n   (node (ref "{r}") (pin "{p}"))' for r,p in sorted(nodes))
        out.append(f'  (net (code "{code}") (name "{net}"){ns})'); code+=1
    out.append(' ))')
    open(path,'w').write('\n'.join(out))
    return code-1
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

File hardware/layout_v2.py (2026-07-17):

#!/usr/bin/env python3
# NOTE: this is the SHARED BOARD GENERATOR (gen_pcb, place_footprint, GND plane).
# layout_mount.py imports it; the v2 FLOORPLAN/board size below is legacy default.
"""PowerMOD v2 layout generator — Raspberry Pi Zero form factor, 4 layers.

Same electrical design as v1: reads connectivity from netlist.py, which is
untouched. Only the geometry changes, so ERC and the BOM carry over verified.

v2 vs v1 (hardware/layout.py, 58x40mm 2-layer):
  - 65 x 30mm, the Pi Zero outline, with the Pi's own M2.5 mounting-hole grid
    (58 x 23mm, 3.5mm in from each corner) so the board stacks on the same
    standoffs as the host.
  - 4 layers: F.Cu signal / In1.Cu solid GND plane / In2.Cu signal+power / B.Cu
    signal. The inner GND plane is the point of the exercise. v1's entire
    endgame was fighting a 2-layer pour that signal traces kept carving into
    isolated islands; with a dedicated plane, any GND pad connects with one via
    and the island/stitching failure mode structurally cannot occur.
  - Trace widths are ENFORCED via net classes (netclasses.py). v1 silently
    routed 3A rails at 0.2mm and passed DRC clean, because with no net class
    defined there was no width rule to check. v2 does not repeat that.

Layer policy: In1 is the GND plane and carries no tracks (a full-board rule area
forbids them; vias and pour still allowed). In2 is left free for routing —
splitting it into power planes was tried and abandoned because the power nets'
pads are geographically interleaved under this placement, so no clean partition
exists that doesn't strand pads. The high-current rails instead get 1.1mm traces
per netclass, and the router gets a third layer, which is what a 65x30 board at
this density actually needs.

Floorplan intent: power flows left to right, J1 (USB-C in) on the west short
edge -> charger/OR -> VSYS -> converter (tight L1 loop) -> VOUT -> J2 (USB-C
out) on the east short edge. Human-facing parts (LEDs, button, jumpers, test
pads) and the remaining connectors live on the long edges. Crystal sits far
from the converter's switching loop.

NOT done here: signal routing (Freerouting, via fr_pipeline.py). Build the whole
thing with ./build_v2.sh.

STATUS (2026-07-16): placement clean (0 courtyard overlaps, verified against
KiCad's own DRC), routing ~91% — 10 of 117 nets fail. NOT yet fab-ready. What the
failed experiments rule out, so they are not repeated:

  * Layers/area are NOT the constraint. v1 (2-layer, 58x40, 2320mm2) leaves 12
    unrouted at full width; v2 (4-layer, 65x30, 1950mm2) leaves 10-13. Nearly
    identical — the extra copper layers just offset the 16% smaller board.
  * Trace width is NOT the constraint. 1.1mm rails -> 10 unrouted; 0.6mm escapes
    into power planes -> also 10.
  * In2 as power planes vs free routing: no material difference (11 vs 10), and
    the planes add dangling vias, because Freerouting still routes signals across
    a plane sitting on a signal-typed layer.
  * Shorter nets are NOT better. A force-directed pass (place_opt.py) cut
    weighted net length 24% and made routing WORSE (17 unrouted): it clustered
    parts and closed the routing channels. Congestion, not length, is the
    objective that matters here.

The remaining failures are all long hauls whose members this floorplan scatters
(CHG_CE spans 30mm; VOUT's members run x 24..53). The next honest lever is a
floorplan designed around routing channels and power-domain geography — a human
judgement call, not another optimiser pass.
"""
import os, re, sys
sys.path.insert(0, os.path.dirname(__file__) or '.')
from netlist import COMPONENTS, build_nets

KISHARE = "/Applications/KiCad/KiCad.app/Contents/SharedSupport/footprints"
BOARD_W, BOARD_H = 65.0, 30.0        # Raspberry Pi Zero outline

# Pi Zero mounting holes: 3.5mm in from each corner -> 58 x 23mm grid, M2.5.
HOLE_INSET = 3.5
HOLES = [(HOLE_INSET, HOLE_INSET), (BOARD_W-HOLE_INSET, HOLE_INSET),
         (HOLE_INSET, BOARD_H-HOLE_INSET), (BOARD_W-HOLE_INSET, BOARD_H-HOLE_INSET)]
HOLE_FP = 'MountingHole:MountingHole_2.7mm_M2.5'
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

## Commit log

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2026-07-15 KiCad transcription: generated netlist + schematic from machine source
    hardware/netlist.py transcribes powermod-schematic.md into a single
    Python data structure (69 components, 230 pins, 44 nets) with a
    validator: golden board-killer facts (Q1/Q2 source=VSYS, TEMP=GND,
    PS/SYNC=GND, INT pull-up rail, J4 pin2 NC, diode orientations), pin
    counts per package, no singleton nets. Generates powermod.net (pcbnew
    netlist import) and powermod.kicad_sch (global-label connectivity).
    Found at transcription: TPS63020 VINA decoupling (100nF, TI reference
    design) was missing from the doc — added as C16 everywhere.
    kicad-cli unavailable here: KiCad itself is the final parser check;
    run ERC on first open.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
    [powermod.kicad_sch]
2026-07-15 KiCad verification: ERC clean, round-trip connectivity proven
    kicad-cli 10.0.4 now installed. Iterated the generator: lib_symbols
    need the full library prefix; placement grid moved to 1.27mm multiples;
    generated powermod.kicad_sym + sym-lib-table + fp-lib-table so all
    references resolve. Every footprint verified to exist on disk —
    TPS63020's VSON-14 traced to a TI drawing, LEDs moved to 4-pad PLCC4
    (the C155 candidate was reverse-mount), switch to PTS647, exact Sumida
    inductor name.
    Final state: ERC = 0 violations, and 'kicad-cli sch export netlist'
    produces connectivity IDENTICAL to our generated powermod.net (44 nets,
    same membership) — KiCad's own engine derives from the schematic
    ex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
    [powermod.kicad_sch]
2026-07-15 Layout: placed, DRC-clean board (routing pending)
    hardware/layout.py: floorplan-as-code. Parses real footprint geometry
    from the installed KiCad libraries, places all 69 components + 4 M2
    holes on a 62x46mm 2-layer outline, binds every pad to its net, pours
    GND both sides. Floorplan encodes the checklist: power flows J1 ->
    charger/OR -> converter -> J2 left to right; crystal ~36mm from the
    inductor loop; connectors on edges.
    Iterated under kicad-cli pcb drc: 200 violations -> 0 electrical/
    mechanical. Remaining: the 160-edge ratsnest (routing deliberately not
    generated) and cosmetic silk warnings. TPS63020 footprint moved to the
    plain EP variant; thermal vias added manually at layout with 0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
    [powermod.kicad_pcb, powermod.kicad_sch]
2026-07-15 Autorouter: 111/115 edges routed — EXPERIMENTAL, not DRC-clean yet
    hardware/router.py: grid A* over a 0.25mm lattice, two layers. Targets
    come from KiCad's own DRC ratsnest; obstacles from parsing every pad
    (coordinates validated 310/310 against KiCad's report). Fine-pitch
    attach via pre-generated 0.2mm escape stubs (legal by construction);
    neck-down near pads; F.Cu preferred so the B.Cu GND pour survives;
    power nets first at 1mm. Spatial hashing: blocked() 11us -> 0.4us.
    Six systematic bugs found and fixed under DRC iteration, including a
    ratsnest parser that paired coordinates across report blocks (33 of 46
    edges were garbage - the routed 'successes' included cross-net shorts)
    and a nea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
    [powermod.kicad_pcb]
2026-07-15 Routing via Freerouting: 0 shorts/clearance/crossings, 4 hand-items left
    Pipeline: pcbnew python (DSN export) -> Freerouting 2.2.4 headless
    (113/115 edges, 11s) -> SES import -> scripted post-passes using
    router.py's obstacle model: 12 GND stitching vias (full-path legality
    sampling), one B-layer route, and EP net bindings.
    Big catch: all five exposed pads (U2/U3/U4/Q1/Q2) were floating - KiCad
    footprints name them '15'/'25'/'9', netlist.py said 'EP', so U3's PGND
    and the FET thermal drains never bound. Surfaced by a DRC clearance
    report naming 'Pad 15 [<no net>]'. Fixed on-board via pcbnew API;
    netlist.py source fix pending regeneration.
    DRC now: 13 unconnected (two U2 escapes Freerouting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
    [powermod.dsn, powermod.kicad_pcb]
2026-07-15 hardware/: remove regenerable intermediates and superseded artifacts
    Kept: the three generators (netlist/layout/router) + fr_pipeline +
    fix_eps, the KiCad project files, current ERC/DRC reports, and the
    current board render. Removed: DSN/SES/round-trip intermediates (the
    scripts recreate them), pre-route render, stale DRC snapshots, local
    prefs. All now gitignored.
    [powermod.dsn]
2026-07-15 Compact re-layout: 56x40mm (-21%), paired solder pads, EP fix at source
    User review caught pad-pairing defect: one shared GND pad served three
    solder interfaces, 36mm from VBACKUP - 'two solder pads (VBACKUP, GND)'
    was physically false. Added TP5/TP6; all three interfaces now have
    adjacent ground partners.
    Also: netlist.py EP keys fixed at source ('EP' -> '25'/'15'/'9' per
    real footprint pad names), so regenerated boards bind exposed pads
    natively. Board shrunk 62x46 -> 56x40 via scaled floorplan + edge
    overrides, iterated under courtyard DRC. Freerouting re-routed the
    compact board in 8-17s per cycle (115/117 edges - placement iteration
    is now cheap, which IS the layout-optimization answer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
    [powermod.kicad_pcb, powermod.kicad_sch]
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2026-07-15 hardware: v1 board fully routed, DRC clean (0 errors, 0 unconnected)
    Completes the 58x40mm 2-layer layout: every signal net routed by
    freerouting, GND plane fully stitched, 0 unconnected pads and 0
    error-severity DRC violations. Remaining 140 items are silkscreen
    cosmetics only.
    Two router.py bugs fixed, both of which had been silently distorting
    the obstacle map for hours of failed routing attempts:
    - parse_pads() classified any pad without F.Cu as bottom-layer copper,
    so solder-paste stencil apertures (F.Paste, no copper at all) became
    phantom B.Cu obstacles. This is what sealed U2's exposed pad and made
    a 2.6mm pad look like it had no room for a thermal via.
    - route_edge() probed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
    [powermod.kicad_pcb]
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2026-07-16 hardware: v2 Pi Zero 4-layer WIP + the width defect v1 hid from DRC
    Two things here: a serious correctness finding about v1, and v2 scaffolding.
    THE FINDING — v1 is not fab-ready, and DRC could not have told us.
    Every power rail (VBUS/VSYS/VBAT/VOUT) is routed at 0.2mm against the >=1mm
    powermod-schematic.md requires for the ratings-table currents: ~5x overload at
    3A. It took two independent omissions, and both are now fixed:
    - Routing: no net class existed, so Freerouting had nothing to aim for and
    defaulted every net to 0.2mm. netclasses.py defines them; they propagate
    into the DSN and the router honours them.
    - Checking: a net class track_width is only a ROUTER PREFERENCE.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
    [powermod_v2.kicad_pcb]
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2026-07-16 hardware: full electrical verification pass + R28 (CE pull-up) + ADC ref
    Reconfirmed the schematic against fresh datasheet evidence, not recall
    (user-requested gate before continuing v1/v2 layout work):
    - TPS63020: pin-function table extracted from TI's PDF -- all 14 pins +
    EP=PGND match netlist.py exactly. VFB=500mV; our JP2-closed divider is
    TI's own 3.3V table row (1M/180k); open computes 5.00V. Switch limit
    4A typ confirmed; C16 satisfies the VINA bypass rule (<=0.22uF).
    - AON7407: package confirmed DFN3x3-8 EP=D (footprint correct); gate
    drives checked against the +/-8V VGS limit: Q1 -3.57V driven, Q2 worst
    +/-5.25V, all safe and past the -3.0V/25mOhm requirement point.
    - OR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
    [powermod.kicad_sch, powermod_v2.kicad_pcb]
2026-07-16 hardware: v2 placement fixes (J2/LEDs) + cleaner no-pours routing (~92%)
    Placement corrections from visual review:
    - J2 (USB-C out) was rotated 180 -> opening faced INTO the board; a plug
    could not be inserted. Now rot 0, facing out the south edge, like J1
    faces out the west edge. Orientation model confirmed against J1.
    - D1/D2 LEDs aligned at the same height, evenly spaced, each with its two
    current-limit resistors grouped directly below (were stranded 15mm away
    by the RTC). J5 (UPDI, location-flexible) moved to the south band to
    make room. 0 courtyard overlaps, verified against KiCad.
    Routing approach changed: dropped the F.Cu power pad-field pours (gated
    behind PADPOURS=1). The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
    [powermod_v2.kicad_pcb]
2026-07-16 hardware: extend grid router to route on In2 (4-layer); diagnose the wall
    Adds In2.Cu as a third routable layer to router.py's A* (was F/B only):
    - Obstacles tracks 'I'; THT pads and vias block it, SMD F/B pads do not
    (In2 is far clearer than the outer layers as a result -- ~73% free here).
    - parse_existing reads In2 segments; via transitions generalized to any
    layer pair, checking the drill is clear on every layer it spans.
    - In2 costed as cheap as F (ideal for long hauls). Guarded by USE_IN2 so
    the 2-layer v1 flow is unaffected.
    close_nets.py routes the remaining nets with this router, each validated
    by a full refill+DRC (kept only if unconnected drops with no new short/
    dangling/cl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
    [close_nets.py, router.py]
2026-07-16 hardware: consolidate — drop v1/v2 + scratch, keep tools + mount board
    Cleaned the accumulated experiment cruft down to the electrical source of
    truth, the reusable tooling, and the active (mount) board.
    Removed:
    - v1 board + layout (layout.py, powermod.kicad_pcb, .kicad_dru). v1 was never
    correct -- it routed 3A rails at 0.2mm; the lesson lives in the docs, not a
    stale board file.
    - v2 experiment (powermod_v2.kicad_pcb) -- superseded by the mount board. Its
    project/rules files were renamed to powermod_mount.*.
    - Superseded scripts: place_opt.py (failed net-length optimiser), place_relax.py
    (-> relax_mount.py), finish_v2.py (unsafe batch finisher), build_v2.sh.
    - Stale committed a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
    [powermod.kicad_pcb, powermod_mount.kicad_pcb, powermod_mount_best.kicad_pcb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]
2026-07-16 attiny: swap MCU to ATtiny1616 SOIC-20 — breaks the QFN routing wall
    The 24-pin QFN (0.5mm pitch) was the persistent autorouting blocker: two of
    its pins could never escape, boxed in by their routed neighbours, and no
    placement or router technique moved them. Swapping to the ATtiny1616 in
    SOIC-20 (1.27mm pitch, 2.5x coarser, no exposed pad, hand-solderable) removes
    that wall entirely -- verified: the MCU pins (3V3, Q1_GATE_DRV) that were stuck
    across every prior attempt now route, and the residual is ordinary nets
    (VBUS/VOUT pour connections, GND stitching), no escape wall.
    Electrical: we used exactly 18 signals and the SOIC-20 has exactly 18 I/O, so
    it fits -- at the cost of the 4 spare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
    [powermod.kicad_sch, powermod_mount.kicad_pcb]
2026-07-17 hardware: pre-fab audit + D5 supercap-drain fix; mount board final
    Full pre-fab audit (PREFAB_AUDIT.md): board verified pad-for-pad against
    netlist.py (214/214 + 11 NC), every IC pinout re-checked against datasheets,
    all operating points computed (FB divider exactly 5.000/3.278V via JP2, ADC
    ranges, gate drive, ~7.5uA off-state drain). Findings fixed:
    - D5 (1N4148WS) added in the VBACKUP charge path (3V3 -> R27 -> D5 -> JP1,
    new net CHG_JPD): without it the supercap back-drains through R27 into the
    dead 3V3 rail at ~3mA exactly when backup is needed.
    - 2 PGND vias added in U3's exposed pad (the TPS63020 4A power-ground return
    had no via to the In1 plane within 3.5mm).
    - USB-C merged-p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
    [powermod.kicad_sch, powermod_mount.kicad_pcb]
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2026-07-17 hardware: verify LCSC part numbers — two were wrong, now fixed
    Checked all 7 audit-list numbers against lcsc.com:
    - C2891852 ("ATtiny1616") was actually a 4-pin 1.2mm pin header. Correct
    part is C614136 (ATTINY1616-SN, SOIC-20) — 0 LCSC stock at check time;
    in-stock substitute C145558 (ATTINY1616-SFR) has a 2.7V minimum supply
    (thin margin at battery-empty), so prefer the -SN from Mouser/DigiKey.
    - C194063 (BM8563) was the TSSOP-8 package — does not fit the SOIC-8
    footprint — and out of stock. Correct: C269877 (BM8563ESA, SOP-8, ~80k).
    - C15483/C382139/C176756/C5446/C52895 all confirmed correct and stocked.
    netlist.py LCSC fields corrected; verification table in PREFAB_AUDIT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
    [powermod.kicad_sch]
2026-07-17 hardware: commit LED + crystal BOM parts (both in-stock, verified)
    Crystal Y1: Epson Q13FC13500004 (LCSC C32346, ~286k stock) — 32.768kHz
    CL=12.5pF matching the BM8563. Netlist-only (footprint unchanged).
    LEDs D1/D2: TOGIALED TJ-S3227 (LCSC C601677, ~7.7k stock), yellow-green die
    fixes the dim-green issue. Its pinout is the OPPOSITE numbering to the stock
    KiCad Avago PLCC4 (would reverse polarity), so a local footprint was built
    from LCSC's EasyEDA model (2 independent diodes, anodes=pins 2/3,
    cathodes=pins 1/4). D1/D2 swapped on the board and anodes re-routed; cathodes
    tie through the GND pour. Board rebuilt at rot 0 (anodes stacked under the
    resistors, no crossing). LED_SMD lib dropped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
    [powermod.kicad_pcb, powermod.kicad_sch]
2026-07-17 hardware: VBUS current-sharing (manual route) + audit review pass
    VBUS current-sharing (audit open item d): A4↔A9 tied with a 0.6mm F.Cu link
    in the narrow channel right of the connector pad column — routed by hand in
    KiCad where the scripts could only fit 0.4mm. Split is now A9 73% / A4 27%
    (was ~100/0): A9's USB-C contacts drop from 1.15A to 0.84A each at the 2.3A
    peak, comfortably inside the ~1.25A/contact rating. Also simplified several
    VBUS/other routes in passing.
    Audit review pass on PREFAB_AUDIT.md: fixed stale counts (214/214 pads, 234
    SMD pads); rewrote the ADC-reference firmware note (use VDD/3.3V or 2.5V, not
    the marginal 1.5V); added Finding 3 (power-rail width-vs-current a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
    [powermod.kicad_pcb]
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2026-07-17 hardware: record SPICE results; move tooling into tools/
    PREFAB_AUDIT.md: added a "SPICE verification" section — behavioural ngspice
    of the Q1/Q2/Q3 power path confirms the OR-ing/bootstrap/soft-start work and
    that VOUT holds its setpoint (5V or 3.3V) through USB unplug in every
    battery-backed case (converter's 1.8V floor masks the VSYS sag). Findings:
    unplug VSYS sag (harmless, VOUT uninterrupted), low-battery margin, and a
    3.3V-rail droop that reinforces using the ATtiny -SN (1.8V) not -SF (2.7V).
    Repo tidy: the 14 layout/routing/placement scripts moved to tools/ (+ the
    SPICE deck in tools/spice/). netlist.py stays at top — it's the design source
    and writes the deliverables here. Move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
    [close_nets.py, finish_board.py, layout_mount.py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]
2026-07-17 hardware: move freerouting.jar into tools/ with the rest of the tooling
    Filesystem move (the jar is gitignored, ~55MB). Updated the gitignore path,
    pointed place_search_mount.py at the jar next to itself (dirname(__file__)),
    and fixed the README reference.
    [place_search_mount.py]
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2026-07-17 hardware: fix inductor part# + footprint-audit the whole BOM
    L1: C329701 (Chilisin SCDS74) does NOT fit — its pads are 6.9mm pitch vs the
    footprint's 5.7mm. Only the Sumida CDMC6D28NP-1R5MC (C17554046) fits exactly,
    but it's OOS at LCSC -> consign or hand-solder (2 pads). Corrected in netlist.
    Footprint audit (PREFAB_AUDIT.md): JLC checks stock, not footprint match, so
    verified every part's package vs its board footprint. USB-C (C165948) merged
    footprint confirmed correct (12 signal + 4 shield match the real connector);
    JST-SH clone matches; passives + standard IC packages safe. Flagged: SW1 button
    pad-span reads ~0.9mm long (verify vs C&K datasheet); J3/J5 are through-hole
    (hand-solder o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
    [powermod_bom.csv]
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2026-07-18 hardware: omit test points + solder jumpers from assembly BOM
    TP1-6 and JP1/JP2 are bare copper (test pads / solder-bridge jumpers), not
    components — they have no CPL placement, so JLC warned "designators don't
    exist in the CPL file". gen_bom() now skips TestPoint/SolderJumper footprints.
    BOM and CPL now match exactly (65 designators, no orphans). J5 header kept
    (real part, blank LCSC = hand-solder).
    [powermod_bom.csv]
2026-07-18 hardware: swap MCU ATtiny1616 -> PY32F003F18P6 (netlist)
    No well-stocked AVR exists at JLC in any package (whole tinyAVR/megaAVR-0 line
    <~100 units, all Extended, verified 2026-07-18). PY32F003F18P6 (ARM M0+,
    TSSOP-20, LCSC C5379864, ~22k stock) is in-stock, cheaper, and stays out of QFN.
    - U2: TSSOP-20 pinout transcribed + verified vs LCSC C5379864 symbol. ADC on
    PA4/PA5, HW I2C1 on PB6/PB7 (STEMMA), RTC I2C bit-banged on PF0/PF1, SWD on
    PA13/PA14 shared with the 2 BAT LEDs (connect-under-reset via NRST=PF2),
    BOOT0=PF4 carries an LED output. 0 spare pins. Net names unchanged vs the
    ATtiny map (only pin assignment moved); UPDI dropped, NRST added.
    - Dividers UNCHANGED: with VDD (3.3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
    [powermod.kicad_sch, powermod_bom.csv]
2026-07-18 hardware: board footprint swap for PY32F003 (U2 TSSOP-20, J5 SWD, TP7 NRST)
    Text-level swap on powermod.kicad_pcb (pcbnew footprint mutation segfaults):
    - U2 SOIC-20W -> TSSOP-20_4.4x6.5mm, 20 pads net-assigned to the PY32 pinmap
    - J5 3-pin UPDI -> 3-pin SWD (GND/SWCLK/SWDIO); a 5-pin header won't fit the
    packed RTC/USB corner, so NRST is exposed on the new TP7 probe pad instead
    - stripped 201 stale MCU-net segments + 6 local 3V3/GND stubs
    Verified in pcbnew: correct nets, zero courtyard collisions. DRC clean apart
    from the 4 known U3 track_width necks + 36 unrouted MCU connections (ratsnest).
    MCU-area routing still to do; power/USB/charger routing untouched.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
    [powermod.kicad_pcb, powermod.kicad_sch, powermod_bom.csv]
2026-07-18 hardware: in-stock swaps for L1 inductor + SW1 button (LCSC-only, no re-layout)
    - L1: Sumida CDMC6D28 (OOS) -> CYA0650-1.5UH (C5189751, ~11k). Lands are
    2.35x3.5mm @ 5.7mm pitch = same pitch as the existing L_Sumida_CDMC6D28
    footprint, body 7.2x6.6mm ~ same, so it drops onto the current land pattern
    with no board change. Confirm exact Isat/Irms on datasheet (size implies ~9A).
    - SW1: C&K PTS647SK50 (OOS) -> PTS647SN50 (C2799414, ~9k). Same PTS647 4.5x4.5
    SMD footprint; N vs K is only plunger height. Drop-in.
    Whole BOM now in-stock except J5 (SWD hand-solder header, DNP by design). The
    only board change for the all-in-stock goal is the MCU (TSSOP-20), already done.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
    [powermod.kicad_sch, powermod_bom.csv]
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2026-07-18 hardware: user MCU/J3 placement + fix J3-flip VBAT short
    User placed the TSSOP (36.5,22.5) and moved/rotated J3 to the exposed strip
    (7.95,33). Flipping J3 swapped its pads, so the stale VBAT stubs to the old J3
    spot shorted to the new GND pad — stripped those 6 tracks/vias. Board verified:
    pad-diff 226/226, no courtyard collisions, DRC clean apart from the 4 known U3
    track_width necks + 38 unrouted (MCU nets + J3 VBAT/GND). MCU-area routing TBD.
    [powermod.kicad_pcb]
2026-07-18 hardware: full Freerouting reroute for the PY32F003 board
    Option B: strip-and-reroute the whole board (grid A* + incremental Freerouting
    both can't thread the MCU corner; Freerouting crashes on pre-routed input, so
    full reroute is the only viable autoroute). Freerouting v2.2.4 -mp 50:
    121 -> 6 unrouted. finish_board: SES import + 136 GND stitch vias + 2 island
    ties -> 382 tracks, 181 vias.
    DRC clean apart from the 4 known U3 track_width necks. Pad-diff 226/226.
    6 connections remain: the USB-C large power pads (VBUS->J1 A4/A9, VOUT->J2
    A4/A9 + TP3) — the known "scripted/auto tracks don't bind to big connector
    pads" case; hand-route these (and re-apply the VBUS A9/A4 current-share split).
    N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
    [powermod.kicad_pcb]
2026-07-18 hardware: complete board routing + regenerate CPL
    Hand-routed the 6 USB-C large-pad escapes (VBUS->J1 A4/A9, VOUT->J2 A4/A9,
    VOUT->TP3) at 0.6mm. Board now: 0 unrouted, 0 clearance, pad-diff 226/226.
    Only the 4 known U3 track_width necks remain on copper. Remaining DRC items
    are silkscreen warnings (ref-des over copper/overlap) — cosmetic, fab-clipped.
    CPL regenerated from final placement (65 placements).
    [powermod.kicad_pcb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]
2026-07-18 hardware: J5 3-pin+TP7 -> 4-pin SWD header (NRST folded in) [WIP]
    Fold the NRST probe pad (TP7) into J5 as a 4th header pin: J5 1x03 -> 1x04
    (GND/SWCLK/SWDIO/NRST), TP7 removed, NRST net now U2.18 + J5.4. Cleaner
    programming connector (proper connect-under-reset pin, no loose test pad).
    WIP: J5's default in-place spot puts pin 4 over routed copper (a GND stitch via
    + VOUT/3V3 traces). User repositions J5 to a clear area next; then reroute its
    4 connections + refill + DRC + regen CPL/gerbers. pad-diff 226/226.
    [powermod.kicad_pcb, powermod.kicad_sch, powermod_bom.csv]
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2026-07-18 hardware: full reroute after placement loosening; both GND pads tied
    User spread C10/U2/J5. Full Freerouting reroute (121->6). finish_board tied
    C10.2 GND cleanly this time; U2.7 (MCU GND) tied via a 0.9mm F.Cu stub+via
    (the pour island was still too tight for a direct plane via). 387 tracks,
    195 vias. pad-diff 226/226, DRC clean except 4 known necks. Power trunks 0.6mm,
    switch node 1.1mm. Remaining: 5 USB-C large-pad escapes to hand-route.
    [powermod.kicad_pcb]
2026-07-18 hardware: reroute after U1-near-U2 placement; RTC bus ~34mm shorter
    User moved U1 (RTC) adjacent to U2 (MCU) and J5 to the edge. Full Freerouting
    reroute (121->6). All 4 GND islands now tie automatically - no stub+via hack
    for U2.7 this time. 409 tracks, 198 vias, pad-diff 226/226, DRC clean except
    the 4 known necks.
    RTC bus shortened: RTC_INT -13.4mm, RTC_SCL -12.2mm, RTC_SDA -8.1mm, 3V3 -4.1mm.
    Minor +3mm on SDA/SCL/VBUS_DIV (slow signals). Crystal still ~3mm, power trunks
    0.6mm unchanged. Remaining: USB-C large-pad escapes to hand-route.
    [powermod.kicad_pcb]
2026-07-18 hardware: regenerate CPL for final routed board (TP3 done, 0 unrouted)
    USB-C escapes + TP3 hand-routed -> board fully routed. Final verify: 0 unrouted,
    0 clearance, pad-diff 226/226, no singleton nets, footprints match, BOM/CPL
    cross-check clean (65/65, no orphans). CPL re-exported from final placement.
    [powermod_cpl.csv]
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2026-07-18 hardware: switch-node reroute (L1N/L2) -> 0 DRC errors
    User rerouted L1N/L2 uniformly at 1.1mm (single-layer F.Cu, no vias, ~9.7mm each)
    right up to U3's QFN L-pins, eliminating the 4 intrinsic track_width necks that
    the board carried since the ATtiny days. Error-level DRC now 0 (was 4). Only
    cosmetic silk warnings remain. pad-diff 226/226, 0 unrouted. Gerbers refreshed.
    [powermod.kicad_pcb]
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2026-07-18 hardware: fix J1/J2 (USB-C) CPL position - origin vs centroid
    The custom merged-pad USB-C footprint's origin sits 3.22mm off its pad
    centroid (body-center anchor, but all pins on one side). kicad-cli exports the
    origin as Mid X/Y, so JLC placed the connectors 3.22mm off their pads (caught
    in JLC's placement preview - would have been an assembly failure at 0.6mm
    pitch). Patched J1/J2 Mid X/Y to the pad centroid: J1 (8.12,-15.0),
    J2 (50.0,-31.83). All other parts use standard footprints (origin = body
    center = JLC reference), verified not to need correction.
    NOTE: a raw `kicad-cli export pos` regen re-introduces the offset - either use
    this patched CPL or move the J1/J2 footprint anchor to th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
    [powermod_cpl.csv]
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

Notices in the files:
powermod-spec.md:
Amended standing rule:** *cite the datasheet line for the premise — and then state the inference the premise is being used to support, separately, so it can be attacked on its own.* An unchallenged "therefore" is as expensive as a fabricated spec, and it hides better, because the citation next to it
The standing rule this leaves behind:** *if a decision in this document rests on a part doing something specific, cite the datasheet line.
